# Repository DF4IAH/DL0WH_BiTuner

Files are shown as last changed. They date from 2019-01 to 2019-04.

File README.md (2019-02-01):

# DL0WH_BiTuner_Firmware
Based on the DJ0ABR tuner hardware this project is a replacement for the controller PCB and its firmware. The new PCB does have a __STM32L476RGT6__ MCU device and has got preparations for SWR metering.

## V1.2 PCB after placement and routing was done:
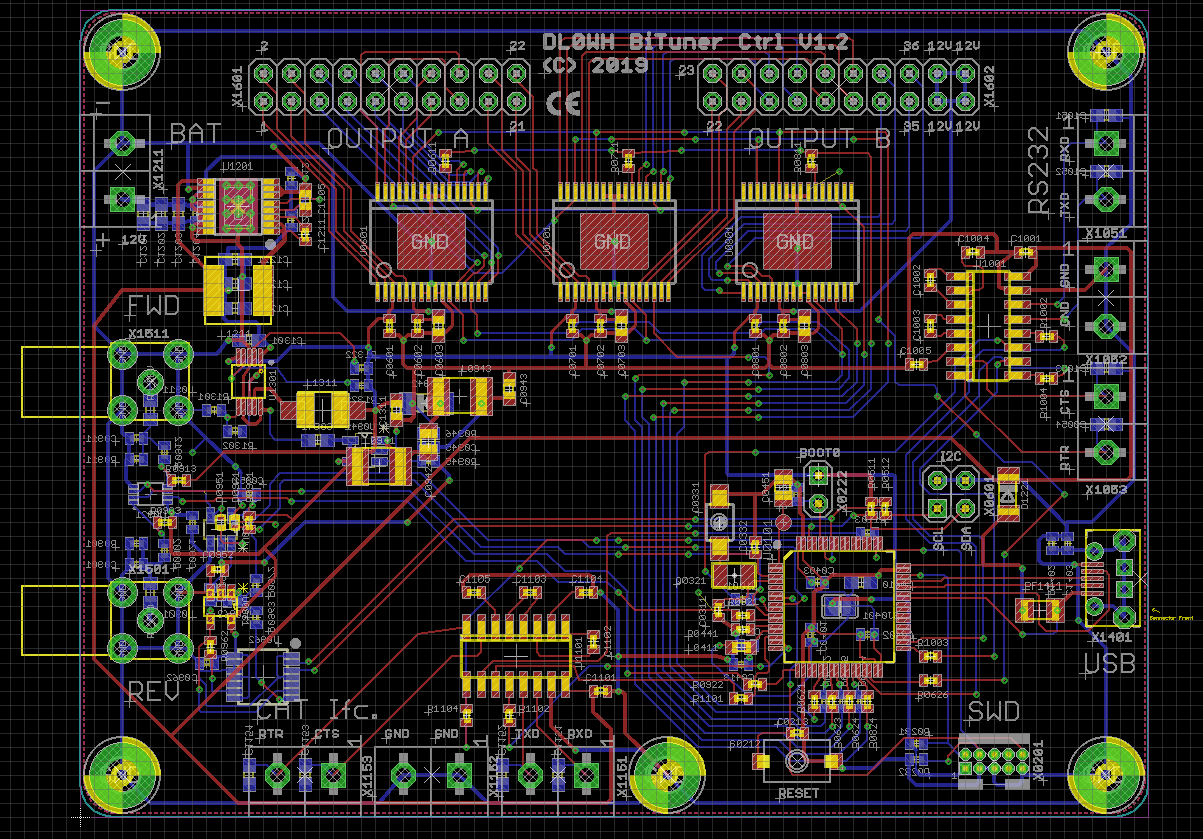
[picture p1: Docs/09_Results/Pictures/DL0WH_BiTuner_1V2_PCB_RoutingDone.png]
Screenshot of V1.2 no polyfill


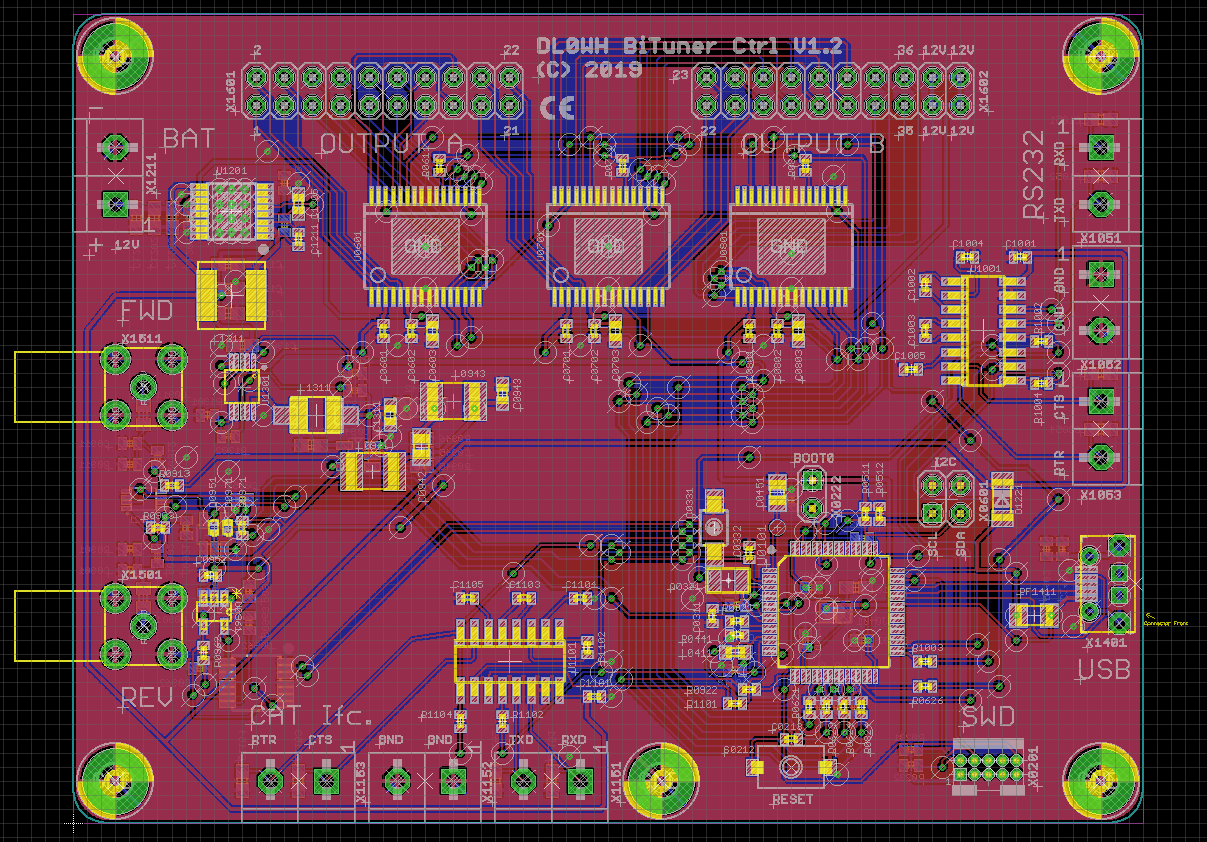
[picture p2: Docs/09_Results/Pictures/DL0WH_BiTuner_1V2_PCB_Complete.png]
Screenshot of V1.2 complete


## V1.2 MCU Pinout:
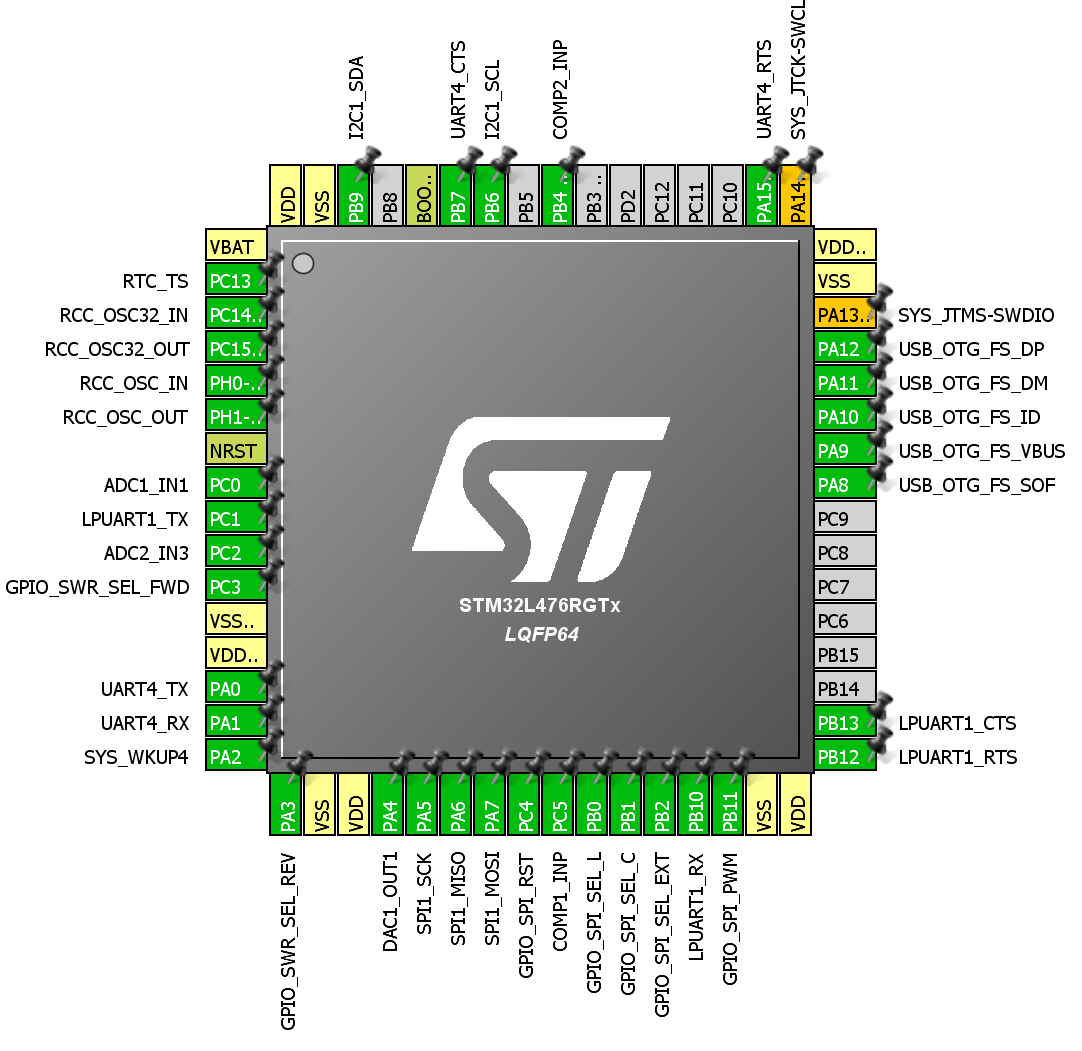
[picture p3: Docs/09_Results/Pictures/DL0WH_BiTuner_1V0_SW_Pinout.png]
MCU Pinout of V1.0


## Ready for samples:
The board is again ready for production.

## Version list:
V1.2 SWD connector bad size - 2019-02-01
* Library content for the CORTEX JTAG/SWD connector was wrong, fixed.
* PCB board house failed on trace distances of 6 mils. Design expanded to 8 mils.

---

V1.1 LQFP64 bug fix - 2019-01-18
* Due to a bad LQFP64 package within the STM32L4 library (who made that crappy library?) the device did not fit at the PCB. That made a turn-around to take time and money. Never trust any library again.

---

V1.0 initial version - 2019-01-04

---

73  Uli DF4IAH, Ladenburg, 2019-02-01

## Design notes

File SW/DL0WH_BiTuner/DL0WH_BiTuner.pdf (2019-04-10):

## DL0WH_BiTuner Project Configuration Report

# 1. Description

## 1.1. Project

Project Name | DL0WH_BiTuner
Board Name | custom
Generated with: | STM32CubeMX 4.27.0
Date | 04/10/2019

## 1.2. MCU

MCU Series | STM32L4
MCU Line | STM32L4x6
MCU name | STM32L476RGTx
MCU Package | LQFP64
MCU Pin number | 64

# 2. Pinout Configuration

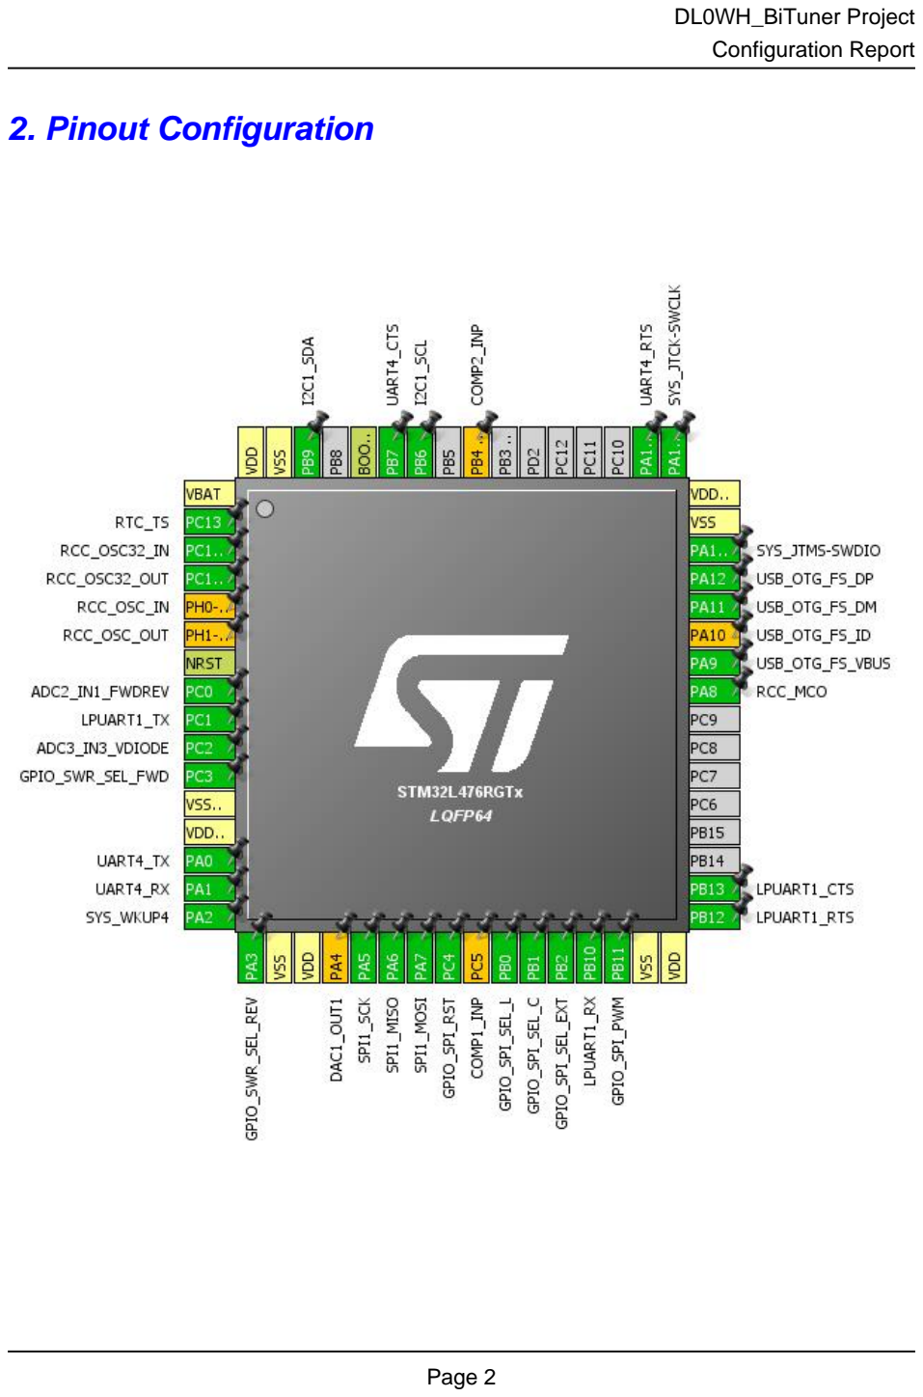
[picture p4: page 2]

# 3. Pins Configuration

Pin Number LQFP64 | Pin Name (function after reset) | Pin Type | Alternate Function(s) | Label
1 | VBAT | Power
2 | PC13 | I/O | RTC_TS
3 | PC14-OSC32_IN (PC14) | I/O | RCC_OSC32_IN
4 | PC15-OSC32_OUT (PC15) | I/O | RCC_OSC32_OUT
5 | PH0-OSC_IN (PH0) * | I/O | RCC_OSC_IN
6 | PH1-OSC_OUT (PH1) * | I/O | RCC_OSC_OUT
7 | NRST | Reset
8 | PC0 | I/O | ADC1_IN1, ADC2_IN1 | ADC2_IN1_FWDREV
9 | PC1 | I/O | LPUART1_TX
10 | PC2 | I/O | ADC2_IN3, ADC3_IN3 | ADC3_IN3_VDIODE
11 | PC3 ** | I/O | GPIO_Output | GPIO_SWR_SEL_FWD
12 | VSSA/VREF- | Power
13 | VDDA/VREF+ | Power
14 | PA0 | I/O | UART4_TX
15 | PA1 | I/O | UART4_RX
16 | PA2 | I/O | SYS_WKUP4
17 | PA3 ** | I/O | GPIO_Output | GPIO_SWR_SEL_REV
18 | VSS | Power
19 | VDD | Power
20 | PA4 * | I/O | DAC1_OUT1
21 | PA5 | I/O | SPI1_SCK
22 | PA6 | I/O | SPI1_MISO
23 | PA7 | I/O | SPI1_MOSI
24 | PC4 ** | I/O | GPIO_Output | GPIO_SPI_RST
25 | PC5 * | I/O | COMP1_INP
26 | PB0 ** | I/O | GPIO_Output | GPIO_SPI_SEL_L
27 | PB1 ** | I/O | GPIO_Output | GPIO_SPI_SEL_C
28 | PB2 ** | I/O | GPIO_Output | GPIO_SPI_SEL_EXT
29 | PB10 | I/O | LPUART1_RX
30 | PB11 ** | I/O | GPIO_Output | GPIO_SPI_PWM
31 | VSS | Power
32 | VDD | Power
33 | PB12 | I/O | LPUART1_RTS
34 | PB13 | I/O | LPUART1_CTS
41 | PA8 | I/O | RCC_MCO
42 | PA9 | I/O | USB_OTG_FS_VBUS

Pin Number LQFP64 | Pin Name (function after reset) | Pin Type | Alternate Function(s) | Label
43 | PA10 * | I/O | USB_OTG_FS_ID
44 | PA11 | I/O | USB_OTG_FS_DM
45 | PA12 | I/O | USB_OTG_FS_DP
46 | PA13 (JTMS-SWDIO) | I/O | SYS_JTMS-SWDIO
47 | VSS | Power
48 | VDDUSB | Power
49 | PA14 (JTCK-SWCLK) | I/O | SYS_JTCK-SWCLK
50 | PA15 (JTDI) | I/O | UART4_RTS
56 | PB4 (NJTRST) * | I/O | COMP2_INP
58 | PB6 | I/O | I2C1_SCL
59 | PB7 | I/O | UART4_CTS
60 | BOOT0 | Boot
62 | PB9 | I/O | I2C1_SDA
63 | VSS | Power
64 | VDD | Power

## ** The pin is affected with an I/O function * The pin is affected with a peripheral function but no peripheral mode is activated

# 4. Clock Tree Configuration

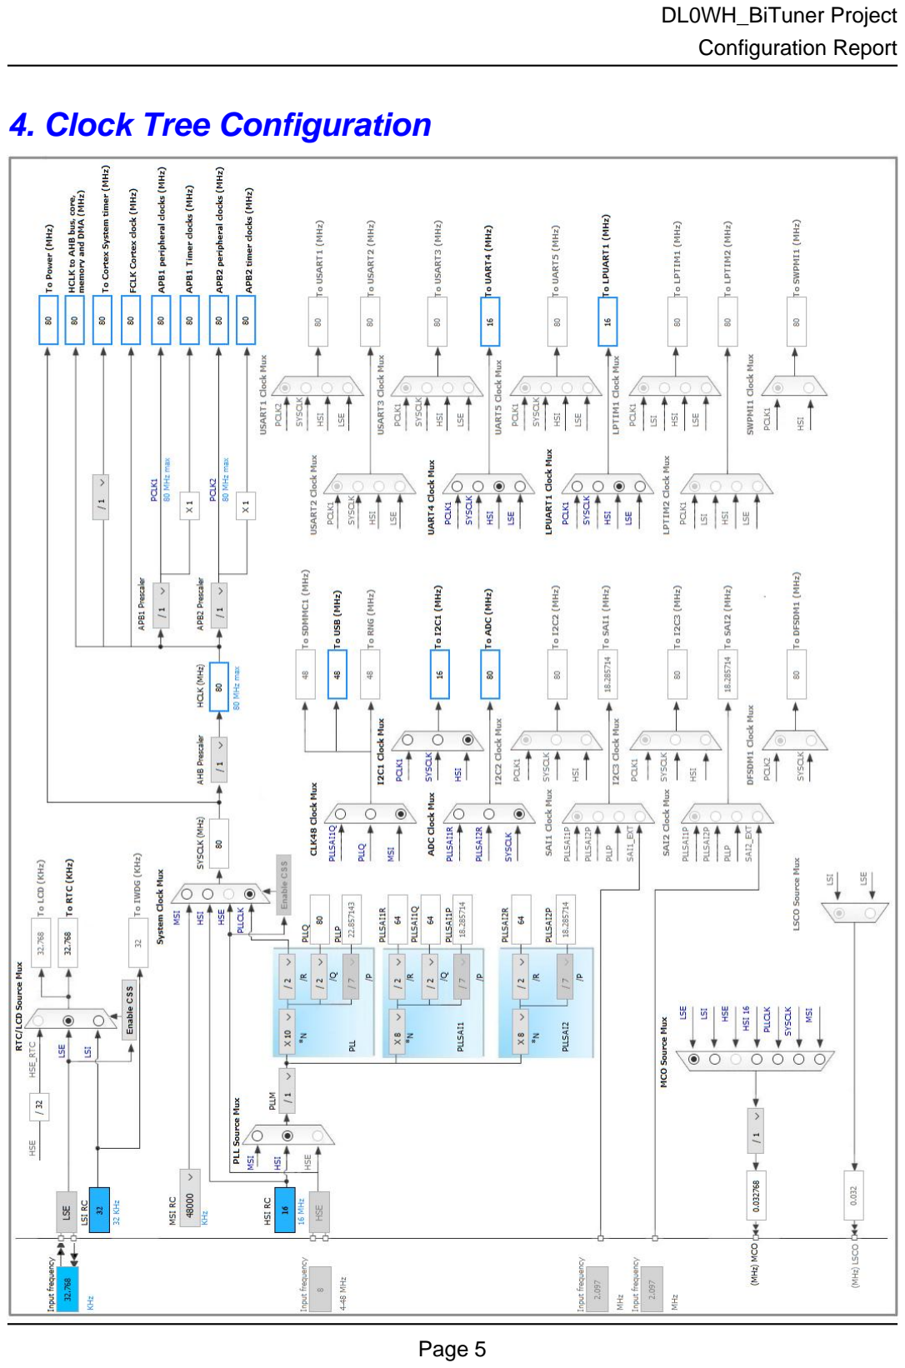
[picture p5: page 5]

# 5. IPs and Middleware Configuration

# 5.1. ADC1

## mode: Temperature Sensor Channel mode: Vbat Channel mode: Vrefint Channel 5.1.1. Parameter Settings:

### ADCs_Common_Settings:

Mode | Independent mode

### ADC_Settings:

Clock Prescaler | Asynchronous clock mode divided by 1
Resolution | ADC 12-bit resolution
Data Alignment | Right alignment
Scan Conversion Mode | Disabled
Continuous Conversion Mode | Disabled
Discontinuous Conversion Mode | Disabled
DMA Continuous Requests | Disabled
End Of Conversion Selection | End of single conversion
Overrun behaviour | Overrun data overwritten *
Low Power Auto Wait | Disabled

### ADC_Regular_ConversionMode:

Enable Regular Conversions | Enable
Enable Regular Oversampling | Enable *
Oversampling Right Shift | No bit shift for oversampling
Oversampling Ratio | Oversampling ratio 16x *
Regular Oversampling Mode | Oversampling Continued Mode
Triggered Regular Oversampling | Single trigger for all oversampled conversions
Number Of Conversion | 1
External Trigger Conversion Source | Regular Conversion launched by software
External Trigger Conversion Edge | None
Rank | 1
Channel | Channel Vrefint *
Sampling Time | 47.5 Cycles *
Offset Number | No offset

### ADC_Injected_ConversionMode:

Enable Injected Conversions | Disable

### Analog Watchdog 1:

Enable Analog WatchDog1 Mode | false

### Analog Watchdog 2:

Enable Analog WatchDog2 Mode | false

### Analog Watchdog 3:

Enable Analog WatchDog3 Mode | false

# 5.2. ADC2

## IN1: IN1 Single-ended 5.2.1. Parameter Settings:

### ADCs_Common_Settings:

Mode | Independent mode

### ADC_Settings:

Clock Prescaler | Asynchronous clock mode divided by 1
Resolution | ADC 12-bit resolution
Data Alignment | Right alignment
Scan Conversion Mode | Disabled
Continuous Conversion Mode | Disabled
Discontinuous Conversion Mode | Disabled
DMA Continuous Requests | Disabled
End Of Conversion Selection | End of single conversion
Overrun behaviour | Overrun data preserved
Low Power Auto Wait | Disabled

### ADC_Regular_ConversionMode:

Enable Regular Conversions | Enable
Enable Regular Oversampling | Enable *
Oversampling Right Shift | 4 bit shift for oversampling *
Oversampling Ratio | Oversampling ratio 256x *
Regular Oversampling Mode | Oversampling Continued Mode
Triggered Regular Oversampling | Single trigger for all oversampled conversions
Number Of Conversion | 1
External Trigger Conversion Source | Regular Conversion launched by software
External Trigger Conversion Edge | None
Rank | 1
Channel | Channel 1
Sampling Time | 12.5 Cycles *
Offset Number | No offset

### ADC_Injected_ConversionMode:

Enable Injected Conversions | Disable

### Analog Watchdog 1:

Enable Analog WatchDog1 Mode | false

### Analog Watchdog 2:

Enable Analog WatchDog2 Mode | false

### Analog Watchdog 3:

Enable Analog WatchDog3 Mode | false

# 5.3. ADC3

## IN3: IN3 Single-ended 5.3.1. Parameter Settings:

### ADC_Settings:

Clock Prescaler | Asynchronous clock mode divided by 1
Resolution | ADC 12-bit resolution
Data Alignment | Right alignment
Scan Conversion Mode | Disabled
Continuous Conversion Mode | Disabled
Discontinuous Conversion Mode | Disabled
DMA Continuous Requests | Disabled
End Of Conversion Selection | End of single conversion
Overrun behaviour | Overrun data overwritten *
Low Power Auto Wait | Disabled

### ADC_Regular_ConversionMode:

Enable Regular Conversions | Enable
Enable Regular Oversampling | Enable *
Oversampling Right Shift | No bit shift for oversampling
Oversampling Ratio | Oversampling ratio 16x *
Regular Oversampling Mode | Oversampling Continued Mode
Triggered Regular Oversampling | Single trigger for all oversampled conversions
Number Of Conversion | 1
External Trigger Conversion Source | Regular Conversion launched by software
External Trigger Conversion Edge | None
Rank | 1
Channel | Channel 3
Sampling Time | 47.5 Cycles *
Offset Number | No offset

### ADC_Injected_ConversionMode:

Enable Injected Conversions | Disable

### Analog Watchdog 1:

Enable Analog WatchDog1 Mode | false

### Analog Watchdog 2:

Enable Analog WatchDog2 Mode | false

### Analog Watchdog 3:

Enable Analog WatchDog3 Mode | false

# 5.4. I2C1

## I2C: I2C 5.4.1. Parameter Settings:

### Timing configuration:

I2C Speed Mode | Fast Mode *
I2C Speed Frequency (KHz) | 400
Rise Time (ns) | 50 *
Fall Time (ns) | 20 *
Coefficient of Digital Filter | 3 *
Analog Filter | Enabled
Timing | 0x00200316 *

### Slave Features:

Clock No Stretch Mode | Disabled
General Call Address Detection | Disabled
Primary Address Length selection | 7-bit
Dual Address Acknowledged | Disabled
Primary slave address | 0

# 5.5. LPUART1

## Mode: Asynchronous Hardware Flow Control (RS232): CTS/RTS 5.5.1. Parameter Settings:

### Basic Parameters:

Baud Rate | 9600 *
Word Length | 8 Bits (including Parity) *
Parity | None
Stop Bits | 1

### Advanced Parameters:

Data Direction | Receive and Transmit
Single Sample | Disable

### Advanced Features:

TX Pin Active Level Inversion | Disable
RX Pin Active Level Inversion | Disable
Data Inversion | Disable
TX and RX pins Swapping | Disable
Overrun | Enable
DMA on RX Error | Enable
MSB First | Disable

# 5.6. RCC

## Low Speed Clock (LSE) : Crystal/Ceramic Resonator mode: Master Clock Output 5.6.1. Parameter Settings:

### System Parameters:

VDD voltage (V) | 3.3
Instruction Cache | Enabled
Prefetch Buffer | Enabled *
Data Cache | Enabled
Flash Latency(WS) | 4 WS (5 CPU cycle)

### RCC Parameters:

HSI Calibration Value | 0x10
MSI Calibration Value | 0xfe *
MSI Auto Calibration | Enabled
HSE Startup Timout Value (ms) | 100
LSE Startup Timout Value (ms) | 5000
LSE Drive Capability | LSE oscillator medium low drive capability *

### Power Parameters:

Power Regulator Voltage Scale | Power Regulator Voltage Scale 1

# 5.7. RTC

## mode: Activate Clock Source mode: Activate Calendar

## Alarm A: Internal Alarm A WakeUp: Internal WakeUp mode: Timestamp 5.7.1. Parameter Settings:

### General:

Hour Format | Hourformat 24
Asynchronous Predivider value | 127
Synchronous Predivider value | 255

### Calendar Time:

Data Format | BCD data format
Hours | 0
Minutes | 0
Seconds | 0
Day Light Saving: value of hour adjustment | Daylightsaving None
Store Operation | Storeoperation Reset

### Calendar Date:

Week Day | Monday
Month | February *
Date | 4 *
Year | 19 *

### Alarm A:

Hours | 0
Minutes | 0
Seconds | 0
Sub Seconds | 0
Alarm Mask Date Week day | Disable
Alarm Mask Hours | Disable
Alarm Mask Minutes | Disable
Alarm Mask Seconds | Disable
Alarm Sub Second Mask | All Alarm SS fields are masked.
Alarm Date Week Day Sel | Date
Alarm Date | 1

### Wake UP:

Wake Up Clock | RTCCLK / 16
Wake Up Counter | 0

### Time Stamp:

Time Stamp Pin Edge | Time Stamp occurs on the Rising edge

# 5.8. SPI1

## Mode: Full-Duplex Master 5.8.1. Parameter Settings:

### Basic Parameters:

Frame Format | Motorola
Data Size | 8 Bits *
First Bit | MSB First

### Clock Parameters:

Prescaler (for Baud Rate) | 16 *
Baud Rate | 5.0 MBits/s *
Clock Polarity (CPOL) | Low
Clock Phase (CPHA) | 2 Edge *

### Advanced Parameters:

CRC Calculation | Disabled
NSS Signal Type | Software

# 5.9. SYS

## Debug: Serial Wire mode: System Wake-Up 4 Power Voltage Detector In: Power Voltage Detector In (Internal analog voltage) Timebase Source: TIM2 5.9.1. Parameter Settings:

### Programmable_Voltage_Detector_Settings:

PVD detection Level | PWR PVD LEVEL 3 (2.5 V) *
PWR PVD Mode | basic mode is used

# 5.10. TIM5

## mode: Clock Source 5.10.1. Parameter Settings:

### Counter Settings:

Prescaler (PSC - 16 bits value) | 0
Counter Mode | Up
Counter Period (AutoReload Register - 32 bits value ) | 79999999 *
Internal Clock Division (CKD) | No Division
auto-reload preload | Enable *

### Trigger Output (TRGO) Parameters:

Master/Slave Mode (MSM bit) | Disable (Trigger input effect not delayed)
Trigger Event Selection TRGO | Reset (UG bit from TIMx_EGR)

# 5.11. UART4

## Mode: Asynchronous Hardware Flow Control (RS232): CTS/RTS 5.11.1. Parameter Settings:

### Basic Parameters:

Baud Rate | 9600 *
Word Length | 8 Bits (including Parity)
Parity | None
Stop Bits | 1

### Advanced Parameters:

Data Direction | Receive and Transmit
Over Sampling | 16 Samples
Single Sample | Disable

### Advanced Features:

Auto Baudrate | Disable
TX Pin Active Level Inversion | Disable
RX Pin Active Level Inversion | Disable
Data Inversion | Disable
TX and RX Pins Swapping | Disable
Overrun | Enable
DMA on RX Error | Enable
MSB First | Disable

# 5.12. USB_OTG_FS

## Mode: Device_Only Activate_VBUS: VBUS sensing

## 5.12.1. Parameter Settings:

Speed | Full Speed 12MBit/s
Endpoint 0 Max Packet size | 64 Bytes
Enable internal IP DMA | Enabled *
Low power | Disabled
Battery charging | Disabled *
Link Power Management | Enabled *
VBUS sensing | Enabled
Signal start of frame | Disabled

# 5.13. FREERTOS

## mode: Enabled 5.13.1. Config parameters:

### Versions:

FreeRTOS version | 10.0.1
CMSIS-RTOS version | 1.02

### Kernel settings:

USE_PREEMPTION | Enabled
CPU_CLOCK_HZ | SystemCoreClock
TICK_RATE_HZ | 1000
MAX_PRIORITIES | 7
MINIMAL_STACK_SIZE | 256 *
MAX_TASK_NAME_LEN | 32 *
USE_16_BIT_TICKS | Disabled
IDLE_SHOULD_YIELD | Enabled
USE_MUTEXES | Enabled
USE_RECURSIVE_MUTEXES | Disabled
USE_COUNTING_SEMAPHORES | Enabled *
QUEUE_REGISTRY_SIZE | 8
USE_APPLICATION_TASK_TAG | Enabled *
ENABLE_BACKWARD_COMPATIBILITY | Disabled *
USE_PORT_OPTIMISED_TASK_SELECTION | Enabled
USE_TICKLESS_IDLE | Disabled
USE_TASK_NOTIFICATIONS | Enabled
RECORD_STACK_HIGH_ADDRESS | Enabled *

### Memory management settings:

Memory Allocation | Dynamic
TOTAL_HEAP_SIZE | 32768 *
Memory Management scheme | heap_4

### Hook function related definitions:

USE_IDLE_HOOK | Enabled *
USE_TICK_HOOK | Disabled
USE_MALLOC_FAILED_HOOK | Enabled *
USE_DAEMON_TASK_STARTUP_HOOK | Disabled
CHECK_FOR_STACK_OVERFLOW | Option1 *

### Run time and task stats gathering related definitions:

GENERATE_RUN_TIME_STATS | Enabled *
USE_TRACE_FACILITY | Enabled *
USE_STATS_FORMATTING_FUNCTIONS | Enabled *

### Co-routine related definitions:

USE_CO_ROUTINES | Disabled
MAX_CO_ROUTINE_PRIORITIES | 2

### Software timer definitions:

USE_TIMERS | Enabled
TIMER_TASK_PRIORITY | 2
TIMER_QUEUE_LENGTH | 10
TIMER_TASK_STACK_DEPTH | 512

### Interrupt nesting behaviour configuration:

LIBRARY_LOWEST_INTERRUPT_PRIORITY | 15
LIBRARY_MAX_SYSCALL_INTERRUPT_PRIORITY | 5

## 5.13.2. Include parameters:

### Include definitions:

vTaskPrioritySet | Enabled
uxTaskPriorityGet | Enabled
vTaskDelete | Enabled
vTaskCleanUpResources | Enabled *
vTaskSuspend | Enabled
vTaskDelayUntil | Enabled *
vTaskDelay | Enabled
xTaskGetSchedulerState | Enabled
xTaskResumeFromISR | Enabled
xQueueGetMutexHolder | Enabled *
xSemaphoreGetMutexHolder | Enabled *

pcTaskGetTaskName | Enabled *
uxTaskGetStackHighWaterMark | Enabled *
xTaskGetCurrentTaskHandle | Enabled *
eTaskGetState | Enabled *
xEventGroupSetBitFromISR | Enabled *
xTimerPendFunctionCall | Enabled *
xTaskAbortDelay | Enabled *
xTaskGetHandle | Enabled *

# 5.14. USB_DEVICE

## Class For FS IP: Communication Device Class (Virtual Port Com) 5.14.1. Parameter Settings:

### Basic Parameters:

USBD_MAX_NUM_INTERFACES (Maximum number of supported interfaces) | 1
USBD_MAX_NUM_CONFIGURATION (Maximum number of supported configuration) | 1
USBD_MAX_STR_DESC_SIZ (Maximum size for the string descriptors) | 512
USBD_SUPPORT_USER_STRING (Enable user string descriptor) | Disabled
USBD_SELF_POWERED (Enabled self power) | Enabled
USBD_DEBUG_LEVEL (USBD Debug Level) | 1: Only User messages are shown *
USBD_LPM_ENABLED (Link Power Management) | 1: Link Power Management supported

### Class Parameters:

USB CDC Rx Buffer Size | 2048
USB CDC Tx Buffer Size | 2048

## 5.14.2. Device Descriptor:

### Device Descriptor:

VID (Vendor IDentifier) | 0x0483
LANGID_STRING (Language Identifier) | English(United States)
MANUFACTURER_STRING (Manufacturer Identifier) | STMicroelectronics

### Device Descriptor FS:

PID (Product IDentifier) | 0x5740
PRODUCT_STRING (Product Identifier) | STM32 Virtual ComPort
SERIALNUMBER_STRING (Serial number) | 00000000001A
CONFIGURATION_STRING (Configuration Identifier) | CDC Config

INTERFACE_STRING (Interface Identifier) | CDC Interface

### * User modified value

# 6. System Configuration

# 6.1. GPIO configuration

IP | Pin | Signal | GPIO mode | GPIO pull/up pull down

## Max Speed

## User Label

ADC1 | PC0 | ADC1_IN1 | Analog mode for ADC
conversion
No pull-up and no pull-down | n/a | ADC2_IN1_FWDREV
ADC2 | PC0 | ADC2_IN1 | Analog mode for ADC
conversion
No pull-up and no pull-down | n/a | ADC2_IN1_FWDREV
PC2 | ADC2_IN3 | Analog mode for ADC
conversion
No pull-up and no pull-down | n/a | ADC3_IN3_VDIODE
ADC3 | PC2 | ADC3_IN3 | Analog mode for ADC
conversion
No pull-up and no pull-down | n/a | ADC3_IN3_VDIODE
I2C1 | PB6 | I2C1_SCL | Alternate Function Open
Drain
| | | Pull-up | Very High
*
PB9 | I2C1_SDA | Alternate Function Open
| | Drain | Pull-up | Very High
*
LPUART1 | PC1 | LPUART1_TX Alternate Function Push Pull | No pull-up and no pull-down | Medium *
| PB10 | LPUART1_RX Alternate Function Push Pull | Pull-up * | Medium *
| PB12 | LPUART1_RTS Alternate Function Push Pull | No pull-up and no pull-down | Medium *
| PB13 | LPUART1_CTS Alternate Function Push Pull | Pull-up * | Medium *
RCC | PC14- OSC32_IN (PC14)
RCC_OSC32_IN | n/a | n/a | n/a

PC15-
OSC32_OU
T (PC15)

RCC_OSC32_O
UT
n/a | n/a | n/a
| PA8 | RCC_MCO | Alternate Function Push Pull | No pull-up and no pull-down | Low
RTC | PC13 | RTC_TS | n/a | n/a | n/a
SPI1 | PA5 | SPI1_SCK | Alternate Function Push Pull | No pull-up and no pull-down | Very High
*
| PA6 | SPI1_MISO | Alternate Function Push Pull | Pull-down * | Very High
*
| PA7 | SPI1_MOSI | Alternate Function Push Pull | No pull-up and no pull-down | Very High
*
SYS | PA2 | SYS_WKUP4 | n/a | n/a | n/a
| PA13 (JTMS- SWDIO) | SYS_JTMS- SWDIO | n/a | n/a | n/a

PA14 (JTCK-SWCLK)

SYS_JTCK-SWCLK

n/a | n/a | n/a

IP | Pin | Signal | GPIO mode | GPIO pull/up pull down | Max Speed | User Label
UART4 | PA0 | UART4_TX | Alternate Function Push Pull | No pull-up and no pull-down | Medium *
| PA1 | UART4_RX | Alternate Function Push Pull | Pull-up * | Medium *
| PA15 (JTDI) | UART4_RTS | Alternate Function Push Pull | No pull-up and no pull-down | Medium *
| PB7 | UART4_CTS | Alternate Function Push Pull | Pull-up * | Medium *
USB_OTG_ FS | PA9 | USB_OTG_FS_ VBUS | Input mode | No pull-up and no pull-down | n/a
| PA11 | USB_OTG_FS_ DM | Alternate Function Push Pull | No pull-up and no pull-down | Very High *
| PA12 | USB_OTG_FS_ DP | Alternate Function Push Pull | No pull-up and no pull-down | Very High *
Single Mapped Signals | PH0-OSC_IN (PH0) | RCC_OSC_IN | n/a | n/a | n/a
| PH1-OSC_OUT (PH1) | RCC_OSC_OUT | n/a | n/a | n/a
| PA4 | DAC1_OUT1 | Analog mode | No pull-up and no pull-down | n/a
| PC5 | COMP1_INP | Analog mode | No pull-up and no pull-down | n/a
| PA10 | USB_OTG_FS_I D | Alternate Function Push Pull | No pull-up and no pull-down | Very High *
| PB4 (NJTRST) | COMP2_INP | Analog mode | No pull-up and no pull-down | n/a
GPIO | PC3 | GPIO_Output | Output Push Pull | No pull-up and no pull-down | Low | GPIO_SWR_SEL_FWD
| PA3 | GPIO_Output | Output Push Pull | No pull-up and no pull-down | Low | GPIO_SWR_SEL_REV
| PC4 | GPIO_Output | Output Push Pull | No pull-up and no pull-down | Low | GPIO_SPI_RST
| PB0 | GPIO_Output | Output Push Pull | No pull-up and no pull-down | Very High * | GPIO_SPI_SEL_L
| PB1 | GPIO_Output | Output Push Pull | No pull-up and no pull-down | Very High * | GPIO_SPI_SEL_C
| PB2 | GPIO_Output | Output Push Pull | No pull-up and no pull-down | Very High * | GPIO_SPI_SEL_EXT
| PB11 | GPIO_Output | Output Push Pull | No pull-up and no pull-down | Low | GPIO_SPI_PWM

# 6.2. DMA configuration

DMA request | Stream | Direction | Priority
SPI1_TX | DMA1_Channel3 | Memory To Peripheral | Low
SPI1_RX | DMA1_Channel2 | Peripheral To Memory | Low
I2C1_RX | DMA1_Channel7 | Peripheral To Memory | Low
I2C1_TX | DMA1_Channel6 | Memory To Peripheral | Low
LPUART_RX | DMA2_Channel7 | Peripheral To Memory | Low
LPUART_TX | DMA2_Channel6 | Memory To Peripheral | Low
UART4_RX | DMA2_Channel5 | Peripheral To Memory | Low
UART4_TX | DMA2_Channel3 | Memory To Peripheral | Low
ADC2 | DMA2_Channel4 | Peripheral To Memory | Low
ADC1 | DMA1_Channel1 | Peripheral To Memory | Low

## SPI1_TX: DMA1_Channel3 DMA request Settings:

Mode: | Normal
Peripheral Increment: | Disable
Memory Increment: | Enable *
Peripheral Data Width: | Byte
Memory Data Width: | Byte

## SPI1_RX: DMA1_Channel2 DMA request Settings:

Mode: | Normal
Peripheral Increment: | Disable
Memory Increment: | Enable *
Peripheral Data Width: | Byte
Memory Data Width: | Byte

## I2C1_RX: DMA1_Channel7 DMA request Settings:

Mode: | Normal
Peripheral Increment: | Disable
Memory Increment: | Enable *
Peripheral Data Width: | Byte
Memory Data Width: | Byte

## I2C1_TX: DMA1_Channel6 DMA request Settings:

Mode: | Normal
Peripheral Increment: | Disable
Memory Increment: | Enable *
Peripheral Data Width: | Byte
Memory Data Width: | Byte

## LPUART_RX: DMA2_Channel7 DMA request Settings:

Mode: | Normal
Peripheral Increment: | Disable
Memory Increment: | Enable *
Peripheral Data Width: | Byte
Memory Data Width: | Byte

## LPUART_TX: DMA2_Channel6 DMA request Settings:

Mode: | Normal
Peripheral Increment: | Disable
Memory Increment: | Enable *
Peripheral Data Width: | Byte
Memory Data Width: | Byte

## UART4_RX: DMA2_Channel5 DMA request Settings:

Mode: | Normal
Peripheral Increment: | Disable
Memory Increment: | Enable *
Peripheral Data Width: | Byte
Memory Data Width: | Byte

## UART4_TX: DMA2_Channel3 DMA request Settings:

Mode: | Normal
Peripheral Increment: | Disable
Memory Increment: | Enable *
Peripheral Data Width: | Byte
Memory Data Width: | Byte

## ADC2: DMA2_Channel4 DMA request Settings:

Mode: | Normal
Peripheral Increment: | Disable
Memory Increment: | Enable *
Peripheral Data Width: | Half Word
Memory Data Width: | Half Word

## ADC1: DMA1_Channel1 DMA request Settings:

Mode: | Normal
Peripheral Increment: | Disable
Memory Increment: | Enable *
Peripheral Data Width: | Half Word
Memory Data Width: | Half Word

# 6.3. NVIC configuration

Interrupt Table | Enable | Preenmption Priority | SubPriority
Non maskable interrupt | true | 0 | 0
Hard fault interrupt | true | 0 | 0
Memory management fault | true | 0 | 0
Prefetch fault, memory access fault | true | 0 | 0
Undefined instruction or illegal state | true | 0 | 0
System service call via SWI instruction | true | 0 | 0
Debug monitor | true | 0 | 0
Pendable request for system service | true | 15 | 0
System tick timer | true | 15 | 0
RTC wake-up interrupt through EXTI line 20 | true | 5 | 0
DMA1 channel1 global interrupt | true | 5 | 0
DMA1 channel2 global interrupt | true | 5 | 0
DMA1 channel3 global interrupt | true | 5 | 0
DMA1 channel6 global interrupt | true | 5 | 0
DMA1 channel7 global interrupt | true | 5 | 0
ADC1 and ADC2 interrupts | true | 5 | 0
TIM2 global interrupt | true | 0 | 0
I2C1 event interrupt | true | 5 | 0
I2C1 error interrupt | true | 5 | 0
SPI1 global interrupt | true | 5 | 0
RTC alarm interrupt through EXTI line 18 | true | 5 | 0
ADC3 global interrupt | true | 5 | 0
TIM5 global interrupt | true | 5 | 0
UART4 global interrupt | true | 5 | 0
DMA2 channel3 global interrupt | true | 5 | 0
DMA2 channel4 global interrupt | true | 5 | 0
DMA2 channel5 global interrupt | true | 5 | 0
USB OTG FS global interrupt | true | 5 | 0
DMA2 channel6 global interrupt | true | 5 | 0
DMA2 channel7 global interrupt | true | 5 | 0
LPUART1 global interrupt | true | 5 | 0
PVD/PVM1/PVM2/PVM3/PVM4 interrupts through EXTI lines 16/35/36/37/38 | unused
RTC tamper and time stamp, CSS on LSE interrupts through EXTI line 19 | unused
Flash global interrupt | unused
RCC global interrupt | unused
FPU global interrupt | unused

### * User modified value

# 7. Power Consumption Calculator report

### 7.1. Microcontroller Selection

Series | STM32L4
Line | STM32L4x6
MCU | STM32L476RGTx
Datasheet | 025976_Rev4

### 7.2. Parameter Selection

Temperature | 25
Vdd | 3.6

## 7.3. Sequence

Step | Step1 | Step2
Mode | RUN | SLEEP
Vdd | 3.6 | 3.6
Voltage Source | Battery | Vbus
Range | Range2-Medium | Range2-Medium
Fetch Type | FLASH/ART/Cache | ON
Clock Configuration | HSE | HSE
Clock Source Frequency 16 MHz | 16 MHz
CPU Frequency | 16 MHz | 16 MHz
Peripherals | ADC1:fs_10_ksps ADC2:fs_10_ksps ADC3:fs_10_ksps AHB_APB1_Bridge AHB_APB2_Bridge CRC DAC1:OUT1-Buffer_OFF- Middle_code GPIOA GPIOB GPIOC GPIOD GPIOH I2C1 LPTIM1 PVD/BOR RNG RTC SPI1 TIM5 UART4 USB_OTG_FS

### ADC1:fs_10_ksps ADC2:fs_10_ksps ADC3:fs_10_ksps AHB_APB1_Bridge AHB_APB2_Bridge Bus-Matrix CRC FLASH FW GPIOA GPIOB GPIOC GPIOD GPIOH I2C1 IWDG LPUART1 PVD/BOR PWR RNG RTC SPI1 SRAM1 SRAM2 TIM2 TIM5 UART4 USB_OTG_FS

Additional Cons. | 0 mA | 0 mA
Average Current | 2.62 mA | 1.63 mA

Duration | 1 ms | 1 ms
DMIPS | 0.0 | 0.0
Ta Max | 104.58 | 104.74
Category | In DS Table | In DS Table

## 7.4. RESULTS

Sequence Time | 2 ms | Average Current | 2.12 mA
Battery Life | 0 | Average DMIPS | 20.0 DMIPS

## 7.5. Chart

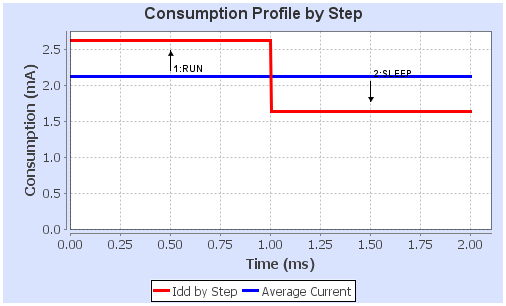
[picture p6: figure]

# 8. Software Project

## 8.1. Project Settings

Name | Value
Project Name | DL0WH_BiTuner
Project Folder | C:\Users\espero\git\DL0WH_BiTuner\SW\DL0WH_BiTuner
Toolchain / IDE | TrueSTUDIO
Firmware Package Name and Version | STM32Cube FW_L4 V1.13.0

## 8.2. Code Generation Settings

Name | Value
STM32Cube Firmware Library Package | Copy only the necessary library files
Generate peripheral initialization as a pair of '.c/.h' files | Yes
Backup previously generated files when re-generating | No
Delete previously generated files when not re-generated | Yes
Set all free pins as analog (to optimize the power consumption) | Yes

# 9. Software Pack Report

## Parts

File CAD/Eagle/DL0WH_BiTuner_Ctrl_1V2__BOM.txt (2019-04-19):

Stückliste exportiert aus /Users/espero/nfs_ds_nfs/git/_untracked/DL0WH_BiTuner/CAD/Eagle/DL0WH_BiTuner_Ctrl_1V2.sch am 19.04.19 14:24

Qty Value                    Device                               Package                             Parts                                                                                                                                             Description                                           

1   STM32L476RXT_64PIN_LDO   STM32L476RXT_64PIN_LDO               LQFP64                              U0101                                                                                                                                             STM32L476RxT 64LQFP                                   

2   MAX232_SOIC16            MAX232_SOIC16                        SOIC16N                             U1001, U1101                                                                                                                                      RS232 TRANSCEIVER                                     

1   LM53603-Q1               LM53603-Q1                           HTSSOP16                            U1201                                                                                                                                             TI LM53603-Q1                                         
1   TPS62056                 TPS62051                             S-PDSO-G10                          U1301                                                                                                                                             TPS62051 800-mA Synchronous Step-Down Converter: 3.3V 
1   LM2611                   LM2611                               SOT95P280X145-5N                    U0941                                                                                                                                             IC REG CUK INV ADJ 1.2A SOT23-5                       

2   OPA354                   OPA354                               SOT-23-5                            U0951, U0961                                                                                                                                      CMOS OPERATIONAL AMPLIFIERS                           

3   MC33996                  MC33996                              SOICW32                             U0601, U0701, U0801                                                                                                                               NXP MC33996                                           

1   TS5A23166                TS5A23166                            R-PDSO-G8                           U0921                                                                                                                                             TS5A23166                                             

1   MCP4661-103E-MS          MCP4661-104E-MS                      TSSOP14                             U0962                                                                                                                                             Microchip MCP4661                                     

1   ABS07-32.768KHZ          ABS07-32.768KHZ                      ABS07                               Q0321                                                                                                                                             ABRACON ABS07                                         

2   CMAD6001                 D_SOD923                             SOD923                              D0951, D0971                                                                                                                                      DIODE with SOD923 footprint                           
2   CRS08                    CRS08                                SOD80C                              D0942, D1221                                                                                                                                      SCHOTTKY BARRIER RECTIFIER                            

2   0R                       R-EU_R0402                           R0402                               R0441, R0622                                                                                                                                      RESISTOR, European symbol                             
1   3R                       R-EU_R0402                           R0402                               R1211                                                                                                                                             RESISTOR, European symbol                             
21  47R                      R-EU_R0402                           R0402                               R0611, R0621, R0623, R0624, R0625, R0626, R0711, R0724, R0811, R0824, R0921, R0922, R0972, R1001, R1002, R1003, R1004, R1101, R1102, R1103, R1104 RESISTOR, European symbol                             
6   1kR                      R-EU_R0402                           R0402                               R0511, R0512, R0901, R0911, R0961, R0962                                                                                                          RESISTOR, European symbol                             
2   2kR                      L-EUL0603                            L0603                               L0901, L0911                                                                                                                                      INDUCTOR, European symbol                             
1   8.2kR                    R-EU_R0402                           R0402                               R0945                                                                                                                                             RESISTOR, European symbol                             
1   10kR                     R-EU_R0402                           R0402                               R0971                                                                                                                                             RESISTOR, European symbol                             
2   15kR                     R-EU_R0402                           R0402                               R0902, R0912                                                                                                                                      RESISTOR, European symbol                             
1   20kR                     R-EU_R0402                           R0402                               R0963                                                                                                                                             RESISTOR, European symbol                             
2   33kR                     R-EU_R0402                           R0402                               R0221, R0946                                                                                                                                      RESISTOR, European symbol                             
1   100kR                    R-EU_R0402                           R0402                               R1301                                                                                                                                             RESISTOR, European symbol                             
2   150kR                    R-EU_R0402                           R0402                               R0903, R0913                                                                                                                                      RESISTOR, European symbol                             
3   220kR                    R-EU_R0402                           R0402                               R0231, R0232, R1302                                                                                                                               RESISTOR, European symbol                             
1   330kR                    R-EU_R0402                           R0402                               R1402                                                                                                                                             RESISTOR, European symbol                             
2   1MR                      R-EU_R0402                           R0402                               R1321, R1322                                                                                                                                      RESISTOR, European symbol                             

1   1.1A/2.2A                R-EU_M1206                           M1206                               PF1411                                                                                                                                            RESISTOR, European symbol                             

2   N/A                      C-EUC0402                            C0402                               C0901, C0911                                                                                                                                      CAPACITOR, European symbol                            
1   18pF                     C-EUC0402                            C0402                               C0332                                                                                                                                             CAPACITOR, European symbol                            
1   22pF                     C-EUC0402                            C0402                               C0311                                                                                                                                             CAPACITOR, European symbol                            
1   100pF                    C-EUC0402                            C0402                               C0963                                                                                                                                             CAPACITOR, European symbol                            
2   1nF                      C-EUC0402                            C0402                               C0945, C1403                                                                                                                                      CAPACITOR, European symbol                            
2   10nF                     C-EUC0402                            C0402                               C0412, C1204                                                                                                                                      CAPACITOR, European symbol                            
8   10nF                     C-EUC0603                            C0603                               C0054, C1051, C1052, C1053, C1151, C1152, C1153, C1154                                                                                            CAPACITOR, European symbol                            
15  100nF                    C-EUC0402                            C0402                               C0213, C0401, C0402, C0403, C0601, C0602, C0701, C0702, C0801, C0802, C0921, C0951, C0952, C0962, C1212                                           CAPACITOR, European symbol                            
1   0.47uF                   C-EUC0402                            C0402                               C1211                                                                                                                                             CAPACITOR, European symbol                            
11  1uF                      C-EUC0402                            C0402                               C0413, C1001, C1002, C1003, C1004, C1005, C1101, C1102, C1103, C1104, C1105                                                                       CAPACITOR, European symbol                            
1   2.2uF                    C-EUC0805                            C0805                               C0942                                                                                                                                             CAPACITOR, European symbol                            
1   3.3uF                    C-EUC0603                            C0603                               C1205                                                                                                                                             CAPACITOR, European symbol                            
1   4.7uF                    C-EUC0603                            C0603                               C0410                                                                                                                                             CAPACITOR, European symbol                            
3   10uF                     C-EUC0603                            C0603                               C1201, C1202, C1203                                                                                                                               CAPACITOR, European symbol                            
10  22uF                     C-EUC0603                            C0603                               C0603, C0703, C0803, C0941, C0943, C1221, C1222, C1223, C1301, C1311                                                                              CAPACITOR, European symbol                            
1   47uF                     C-EUC0805                            C0805                               C0451                                                                                                                                             CAPACITOR, European symbol                            

1   JR200                    C-TRIMM3MM2_2MM5                     3MM2_X_2MM5                         C0331                                                                                                                                             Trimm capacitor                                       

1   2.2uH                    L-EU6.00X6.00MM                      L_6.00MM_X_6.00MM                   L1211                                                                                                                                             INDUCTOR, European symbol                             
1   10uH                     L-EU4.50X3.20MM                      L_4.50MM_X_3.20MM                   L1311                                                                                                                                             INDUCTOR, European symbol                             
1   10uH                     L-EUL0603                            L0603                               L0411                                                                                                                                             INDUCTOR, European symbol                             
2   20uH                     L-EUL1812                            L1812                               L0941, L0943                                                                                                                                      INDUCTOR, European symbol                             

1   KSR223GLFG               KSR223G_SMD_1POL                     KSR223G_SMD_1POL                    S0212                                                                                                                                             KSR223G                                               

1   FTSH-105-01-F-D-K        2X05_1MM27_SHROUDED_CORTEX_JTAG_SWD" 2X05_1MM27_SHROUDED_CORTEX_JTAG_SWD X0201                                                                                                                                             Header 2X5 1.27mm 0.05" shrouded - CORTEX JTAG-SWD    
1   MOLEX 105017-0001        USB_MICRO-B_MOLEX                    USB-B-MICRO-SMD_MOLEX-105017-0001   X1401                                                                                                                                             USB Type Micro-B Connector                            
2   SAMTEC SMA-J-P-H-RA-TH1  SMA_SMT_AMPHENOL-901-143             SMA_SMT_AMPHENOL_901-143            X1501, X1511                                                                                                                                             RF/COAXIAL, SMA JACK, R/A, 50OHM, THD                 
2                            2X10_2MM56_SOCKET                    2X10                                X1601, X1602                                                                                                                                      Header 2X10 2.54mm                                    
1                            HEADER-1X2                           1X02                                X0222                                                                                                                                             Header 1X2 2.54mm                                     
1                            HEADER-2X2                           2X02                                X0601                                                                                                                                             Header 2X2 2.54mm                                     
7   WIRE-TO-BOARD_5MM08_1X02 WIRE-TO-BOARD_5MM08_1X02             WIRE-TO-BOARD_5MM08_1X02            X1051, X1052, X1053, X1151, X1152, X1153, X1211                                                                                                   Wire-to-Board connector 5.08mm 1x02                   

<EOF>

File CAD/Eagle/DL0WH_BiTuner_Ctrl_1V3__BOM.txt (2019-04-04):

Stückliste exportiert aus /Users/espero/nfs_ds_nfs/git/DL0WH_BiTuner/CAD/Eagle/DL0WH_BiTuner_Ctrl_1V3.sch am 16.03.19 19:05

Qty Value                    Device                               Package                             Parts                                                                                                                                             Description                                           

1   STM32L476RGT6_64PIN_LDO  STM32L476RXT_64PIN_LDO               LQFP64                              U0101                                                                                                                                             STM32L476RxT 64LQFP                                   

1   MCP4661-103E-MS          MCP4661-104E-MS                      TSSOP14                             U0962                                                                                                                                             Microchip MCP4661                                     

1   LM53603-Q1               LM53603-Q1                           HTSSOP16                            U1201                                                                                                                                             TI LM53603-Q1                                         
1   TPS62056                 TPS62051                             S-PDSO-G10                          U1301                                                                                                                                             TPS62051 800-mA Synchronous Step-Down Converter: 3.3V 
1   LM2611                   LM2611                               SOT95P280X145-5N                    U0941                                                                                                                                             IC REG CUK INV ADJ 1.2A SOT23-5                       

2   MAX232_SOIC16            MAX232_SOIC16                        SOIC16N                             U1001, U1101                                                                                                                                      RS232 TRANSCEIVER                                     
3   MC33996                  MC33996                              SOICW32                             U0601, U0701, U0801                                                                                                                               NXP MC33996                                           

2   OPA354                   OPA354                               SOT-23-5                            U0951, U0961                                                                                                                                      CMOS OPERATIONAL AMPLIFIERS                           

1   TS5A23166                TS5A23166                            R-PDSO-G8                           U0921                                                                                                                                             TS5A23166                                             

1   ABS07-32.768KHZ          ABS07-32.768KHZ                      ABS07                               Q0321                                                                                                                                             ABRACON ABS07                                         

2   CMAD6001                 D_SOD923                             SOD923                              D0951, D0971                                                                                                                                      DIODE with SOD923 footprint                           
2   CRS08                    CRS08                                SOD80C                              D0942, D1221                                                                                                                                      SCHOTTKY BARRIER RECTIFIER                            

3   0R                       R-EU_R0402                           R0402                               R0401, R0441, R0622                                                                                                                               RESISTOR, European symbol                             
1   3R                       R-EU_R0402                           R0402                               R1211                                                                                                                                             RESISTOR, European symbol                             
21  47R                      R-EU_R0402                           R0402                               R0611, R0621, R0623, R0624, R0625, R0626, R0711, R0724, R0811, R0824, R0921, R0922, R0972, R1001, R1002, R1003, R1004, R1101, R1102, R1103, R1104 RESISTOR, European symbol                             
6   1kR                      R-EU_R0402                           R0402                               R0511, R0512, R0901, R0911, R0961, R0962                                                                                                          RESISTOR, European symbol                             
1   8.2kR                    R-EU_R0402                           R0402                               R0945                                                                                                                                             RESISTOR, European symbol                             
2   10kR                     R-EU_R0402                           R0402                               R0963, R0971                                                                                                                                      RESISTOR, European symbol                             
2   15kR                     R-EU_R0402                           R0402                               R0902, R0912                                                                                                                                      RESISTOR, European symbol                             
2   33kR                     R-EU_R0402                           R0402                               R0221, R0946                                                                                                                                      RESISTOR, European symbol                             
1   100kR                    R-EU_R0402                           R0402                               R1301                                                                                                                                             RESISTOR, European symbol                             
2   150kR                    R-EU_R0402                           R0402                               R0903, R0913                                                                                                                                      RESISTOR, European symbol                             
3   220kR                    R-EU_R0402                           R0402                               R0231, R0232, R1302                                                                                                                               RESISTOR, European symbol                             
1   330kR                    R-EU_R0402                           R0402                               R1402                                                                                                                                             RESISTOR, European symbol                             
2   1MR                      R-EU_R0402                           R0402                               R1321, R1322                                                                                                                                      RESISTOR, European symbol                             

1   1.1A/2.2A                R-EU_M1206                           M1206                               PF1411                                                                                                                                            RESISTOR, European symbol                             

1   18pF                     C-EUC0402                            C0402                               C0332                                                                                                                                             CAPACITOR, European symbol                            
1   22pF                     C-EUC0402                            C0402                               C0311                                                                                                                                             CAPACITOR, European symbol                            
1   100pF                    C-EUC0402                            C0402                               C0963                                                                                                                                             CAPACITOR, European symbol                            
4   1nF                      C-EUC0402                            C0402                               C0901, C0911, C0945, C1403                                                                                                                        CAPACITOR, European symbol                            
10  10nF                     C-EUC0402                            C0402                               C0412, C1051, C1052, C1053, C1054, C1151, C1152, C1153, C1154, C1204                                                                              CAPACITOR, European symbol                            
15  100nF                    C-EUC0402                            C0402                               C0213, C0401, C0402, C0403, C0601, C0602, C0701, C0702, C0801, C0802, C0921, C0951, C0952, C0962, C1212                                           CAPACITOR, European symbol                            
1   0.47uF                   C-EUC0402                            C0402                               C1211                                                                                                                                             CAPACITOR, European symbol                            
11  1uF                      C-EUC0402                            C0402                               C0413, C1001, C1002, C1003, C1004, C1005, C1101, C1102, C1103, C1104, C1105                                                                       CAPACITOR, European symbol                            
1   2.2uF                    C-EUC0603                            C0603                               C0942                                                                                                                                             CAPACITOR, European symbol                            
1   3.3uF                    C-EUC0603                            C0603                               C1205                                                                                                                                             CAPACITOR, European symbol                            
1   4.7uF                    C-EUC0603                            C0603                               C0410                                                                                                                                             CAPACITOR, European symbol                            
3   10uF                     C-EUC0603                            C0603                               C1201, C1202, C1203                                                                                                                               CAPACITOR, European symbol
10  22uF                     C-EUC0603                            C0603                               C0603, C0703, C0803, C0941, C0943, C1221, C1222, C1223, C1301, C1311                                                                              CAPACITOR, European symbol                            
1   47uF                     C-EUC0805                            C0805                               C0451                                                                                                                                             CAPACITOR, European symbol                            

1   JR200                    C-TRIMM3MM2_2MM5                     3MM2_X_2MM5                         C0331                                                                                                                                             Trimm capacitor                                       

1   2.2uH                    L-EU6.00X6.00MM                      L_6.00MM_X_6.00MM                   L1211                                                                                                                                             INDUCTOR, European symbol                             
1   10uH                     L-EU4.50X3.20MM                      L_4.50MM_X_3.20MM                   L1311                                                                                                                                             INDUCTOR, European symbol                             
3   10uH                     L-EUL0603                            L0603                               L0411, L0901, L0911                                                                                                                               INDUCTOR, European symbol                             
2   20uH                     L-EUL1812                            L1812                               L0941, L0943                                                                                                                                      INDUCTOR, European symbol                             

1   KSR223GLFG               KSR223G_SMD_1POL                     KSR223G_SMD_1POL                    S0212                                                                                                                                             KSR223G                                               

1   SAMTEC SMA-J-P-H-RA-TH1  SMA_SMT_AMPHENOL-901-143             SMA_SMT_AMPHENOL_901-143            X1511                                                                                                                                             RF/COAXIAL, SMA JACK, R/A, 50OHM, THD                 
1   SMA_SMT_AMPHENOL-901-143 SMA_SMT_AMPHENOL-901-143             SMA_SMT_AMPHENOL_901-143            X1501                                                                                                                                             RF/COAXIAL, SMA JACK, R/A, 50OHM, THD                 

1   MOLEX 105017-0001        USB_MICRO-B_MOLEX                    USB-B-MICRO-SMD_MOLEX-105017-0001   X1401                                                                                                                                             USB Type Micro-B Connector                            

1   FTSH-105-01-F-D-K        2X05_1MM27_SHROUDED_CORTEX_JTAG_SWD" 2X05_1MM27_SHROUDED_CORTEX_JTAG_SWD X0201                                                                                                                                             Header 2X5 1.27mm 0.05" shrouded - CORTEX JTAG-SWD    
2                            2X10_2MM56_SOCKET                    2X10                                X1601, X1602                                                                                                                                      Header 2X10 2.54mm                                    
1                            HEADER-1X2                           1X02                                X0222                                                                                                                                             Header 1X2 2.54mm                                     
1                            HEADER-2X2                           2X02                                X0501                                                                                                                                             Header 2X2 2.54mm                                     

7   WIRE-TO-BOARD_5MM08_1X02 WIRE-TO-BOARD_5MM08_1X02             WIRE-TO-BOARD_5MM08_1X02            X1051, X1052, X1053, X1151, X1152, X1153, X1211                                                                                                   Wire-to-Board connector 5.08mm 1x02                   

<EOF>

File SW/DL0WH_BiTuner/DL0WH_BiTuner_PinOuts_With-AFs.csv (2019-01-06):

Position | Name | Type | Signal | Label | AF0 | AF1 | AF2 | AF3 | AF4 | AF5 | AF6 | AF7 | AF8 | AF9 | AF10 | AF11 | AF12 | AF13 | AF14 | AF15
1 | VBAT | Power
2 | PC13 | I/O | RTC_TS |  |  |  |  |  |  |  |  |  |  |  |  |  |  |  |  | EVENTOUT
3 | PC14-OSC32_IN (PC14) | I/O | RCC_OSC32_IN |  |  |  |  |  |  |  |  |  |  |  |  |  |  |  |  | EVENTOUT
4 | PC15-OSC32_OUT (PC15) | I/O | RCC_OSC32_OUT |  |  |  |  |  |  |  |  |  |  |  |  |  |  |  |  | EVENTOUT
5 | PH0-OSC_IN (PH0) | I/O | RCC_OSC_IN |  |  |  |  |  |  |  |  |  |  |  |  |  |  |  |  | EVENTOUT
6 | PH1-OSC_OUT (PH1) | I/O | RCC_OSC_OUT |  |  |  |  |  |  |  |  |  |  |  |  |  |  |  |  | EVENTOUT
7 | NRST | Reset
8 | PC0 | I/O | ADC1_IN1 ADC2_IN1 | ADC2_IN1_FWDREV |  | LPTIM1_IN1 |  |  | I2C3_SCL |  | DFSDM1_DATIN4 |  | LPUART1_RX |  |  | LCD_SEG18 |  |  | LPTIM2_IN1 | EVENTOUT
9 | PC1 | I/O | LPUART1_TX |  |  | LPTIM1_OUT |  |  | I2C3_SDA |  | DFSDM1_CKIN4 |  | LPUART1_TX |  |  | LCD_SEG19 |  |  |  | EVENTOUT
10 | PC2 | I/O | ADC2_IN3 ADC3_IN3 | ADC3_IN3_VDIODE |  | LPTIM1_IN2 |  |  |  | SPI2_MISO | DFSDM1_CKOUT |  |  |  |  | LCD_SEG20 |  |  |  | EVENTOUT
11 | PC3 | Output | GPIO_Output | GPIO_SWR_SEL_FWD |  | LPTIM1_ETR |  |  |  | SPI2_MOSI |  |  |  |  |  | LCD_VLCD |  | SAI1_SD_A | LPTIM2_ETR | EVENTOUT
12 | VSSA/VREF- | Power
13 | VDDA/VREF+ | Power
14 | PA0 | I/O | UART4_TX |  |  | TIM2_CH1 | TIM5_CH1 | TIM8_ETR |  |  |  | USART2_CTS | UART4_TX |  |  |  |  | SAI1_EXTCLK | TIM2_ETR | EVENTOUT
15 | PA1 | I/O | UART4_RX |  |  | TIM2_CH2 | TIM5_CH2 |  |  |  |  | USART2_DE/USART2_RTS | UART4_RX |  |  | LCD_SEG0 |  |  | TIM15_CH1N | EVENTOUT
16 | PA2 | I/O | SYS_WKUP4 |  |  | TIM2_CH3 | TIM5_CH3 |  |  |  |  | USART2_TX |  |  |  | LCD_SEG1 |  | SAI2_EXTCLK | TIM15_CH1 | EVENTOUT
17 | PA3 | Output | GPIO_Output | GPIO_SWR_SEL_REV |  | TIM2_CH4 | TIM5_CH4 |  |  |  |  | USART2_RX |  |  |  | LCD_SEG2 |  |  | TIM15_CH2 | EVENTOUT
18 | VSS | Power
19 | VDD | Power
20 | PA4 | I/O | DAC1_OUT1 |  |  |  |  |  |  | SPI1_NSS | SPI3_NSS | USART2_CK |  |  |  |  |  | SAI1_FS_B | LPTIM2_OUT | EVENTOUT
21 | PA5 | I/O | SPI1_SCK |  |  | TIM2_CH1 | TIM2_ETR | TIM8_CH1N |  | SPI1_SCK |  |  |  |  |  |  |  |  | LPTIM2_ETR | EVENTOUT
22 | PA6 | I/O | SPI1_MISO |  |  | TIM1_BKIN | TIM3_CH1 | TIM8_BKIN |  | SPI1_MISO |  | USART3_CTS |  |  | QUADSPI_BK1_IO3 | LCD_SEG3 | TIM1_BKIN_COMP2 | TIM8_BKIN_COMP2 | TIM16_CH1 | EVENTOUT
23 | PA7 | I/O | SPI1_MOSI |  |  | TIM1_CH1N | TIM3_CH2 | TIM8_CH1N |  | SPI1_MOSI |  |  |  |  | QUADSPI_BK1_IO2 | LCD_SEG4 |  |  | TIM17_CH1 | EVENTOUT
24 | PC4 | Output | GPIO_Output | GPIO_SPI_RST |  |  |  |  |  |  |  | USART3_TX |  |  |  | LCD_SEG22 |  |  |  | EVENTOUT
25 | PC5 | I/O | COMP1_INP |  |  |  |  |  |  |  |  | USART3_RX |  |  |  | LCD_SEG23 |  |  |  | EVENTOUT
26 | PB0 | Output | GPIO_Output | GPIO_SPI_SEL_L |  | TIM1_CH2N | TIM3_CH3 | TIM8_CH2N |  |  |  | USART3_CK |  |  | QUADSPI_BK1_IO1 | LCD_SEG5 | COMP1_OUT |  |  | EVENTOUT
27 | PB1 | Output | GPIO_Output | GPIO_SPI_SEL_C |  | TIM1_CH3N | TIM3_CH4 | TIM8_CH3N |  |  | DFSDM1_DATIN0 | USART3_DE/USART3_RTS |  |  | QUADSPI_BK1_IO0 | LCD_SEG6 |  |  | LPTIM2_IN1 | EVENTOUT
28 | PB2 | Output | GPIO_Output | GPIO_SPI_SEL_EXT | RTC_OUT_ALARM/RTC_OUT_CALIB | LPTIM1_OUT |  |  | I2C3_SMBA |  | DFSDM1_CKIN0 |  |  |  |  |  |  |  |  | EVENTOUT
29 | PB10 | I/O | LPUART1_RX |  |  | TIM2_CH3 |  |  | I2C2_SCL | SPI2_SCK | DFSDM1_DATIN7 | USART3_TX | LPUART1_RX |  | QUADSPI_CLK | LCD_SEG10 | COMP1_OUT | SAI1_SCK_A |  | EVENTOUT
30 | PB11 | Output | GPIO_Output | GPIO_SPI_PWM |  | TIM2_CH4 |  |  | I2C2_SDA |  | DFSDM1_CKIN7 | USART3_RX | LPUART1_TX |  | QUADSPI_NCS | LCD_SEG11 | COMP2_OUT |  |  | EVENTOUT
31 | VSS | Power
32 | VDD | Power
33 | PB12 | I/O | LPUART1_RTS |  |  | TIM1_BKIN |  | TIM1_BKIN_COMP2 | I2C2_SMBA | SPI2_NSS | DFSDM1_DATIN1 | USART3_CK | LPUART1_DE/LPUART1_RTS | TSC_G1_IO1 |  | LCD_SEG12 | SWPMI1_IO | SAI2_FS_A | TIM15_BKIN | EVENTOUT
34 | PB13 | I/O | LPUART1_CTS |  |  | TIM1_CH1N |  |  | I2C2_SCL | SPI2_SCK | DFSDM1_CKIN1 | USART3_CTS | LPUART1_CTS | TSC_G1_IO2 |  | LCD_SEG13 | SWPMI1_TX | SAI2_SCK_A | TIM15_CH1N | EVENTOUT
35 | PB14 | I/O |  |  |  | TIM1_CH2N |  | TIM8_CH2N | I2C2_SDA | SPI2_MISO | DFSDM1_DATIN2 | USART3_DE/USART3_RTS |  | TSC_G1_IO3 |  | LCD_SEG14 | SWPMI1_RX | SAI2_MCLK_A | TIM15_CH1 | EVENTOUT
36 | PB15 | I/O |  |  | RTC_REFIN | TIM1_CH3N |  | TIM8_CH3N |  | SPI2_MOSI | DFSDM1_CKIN2 |  |  | TSC_G1_IO4 |  | LCD_SEG15 | SWPMI1_SUSPEND | SAI2_SD_A | TIM15_CH2 | EVENTOUT
37 | PC6 | I/O |  |  |  |  | TIM3_CH1 | TIM8_CH1 |  |  | DFSDM1_CKIN3 |  |  | TSC_G4_IO1 |  | LCD_SEG24 | SDMMC1_D6 | SAI2_MCLK_A |  | EVENTOUT
38 | PC7 | I/O |  |  |  |  | TIM3_CH2 | TIM8_CH2 |  |  | DFSDM1_DATIN3 |  |  | TSC_G4_IO2 |  | LCD_SEG25 | SDMMC1_D7 | SAI2_MCLK_B |  | EVENTOUT
39 | PC8 | I/O |  |  |  |  | TIM3_CH3 | TIM8_CH3 |  |  |  |  |  | TSC_G4_IO3 |  | LCD_SEG26 | SDMMC1_D0 |  |  | EVENTOUT
40 | PC9 | I/O |  |  |  | TIM8_BKIN2 | TIM3_CH4 | TIM8_CH4 |  |  |  |  |  | TSC_G4_IO4 | USB_OTG_FS_NOE | LCD_SEG27 | SDMMC1_D1 | SAI2_EXTCLK | TIM8_BKIN2_COMP1 | EVENTOUT
41 | PA8 | I/O | USB_OTG_FS_SOF |  | RCC_MCO | TIM1_CH1 |  |  |  |  |  | USART1_CK |  |  | USB_OTG_FS_SOF | LCD_COM0 |  |  | LPTIM2_OUT | EVENTOUT
42 | PA9 | I/O | USB_OTG_FS_VBUS |  |  | TIM1_CH2 |  |  |  |  |  | USART1_TX |  |  |  | LCD_COM1 |  |  | TIM15_BKIN | EVENTOUT
43 | PA10 | I/O | USB_OTG_FS_ID |  |  | TIM1_CH3 |  |  |  |  |  | USART1_RX |  |  | USB_OTG_FS_ID | LCD_COM2 |  |  | TIM17_BKIN | EVENTOUT
44 | PA11 | I/O | USB_OTG_FS_DM |  |  | TIM1_CH4 | TIM1_BKIN2 |  |  |  |  | USART1_CTS |  | CAN1_RX | USB_OTG_FS_DM |  | TIM1_BKIN2_COMP1 |  |  | EVENTOUT
45 | PA12 | I/O | USB_OTG_FS_DP |  |  | TIM1_ETR |  |  |  |  |  | USART1_DE/USART1_RTS |  | CAN1_TX | USB_OTG_FS_DP |  |  |  |  | EVENTOUT
46 | PA13 (JTMS-SWDIO) | I/O | SYS_JTMS-SWDIO |  | SYS_JTMS-SWDIO | IR_OUT |  |  |  |  |  |  |  |  | USB_OTG_FS_NOE |  |  |  |  | EVENTOUT
47 | VSS | Power
48 | VDDUSB | Power
49 | PA14 (JTCK-SWCLK) | I/O | SYS_JTCK-SWCLK |  | SYS_JTCK-SWCLK |  |  |  |  |  |  |  |  |  |  |  |  |  |  | EVENTOUT
50 | PA15 (JTDI) | I/O | UART4_RTS |  | SYS_JTDI | TIM2_CH1 | TIM2_ETR |  |  | SPI1_NSS | SPI3_NSS |  | UART4_DE/UART4_RTS | TSC_G3_IO1 |  | LCD_SEG17 |  | SAI2_FS_B |  | EVENTOUT
51 | PC10 | I/O |  |  |  |  |  |  |  |  | SPI3_SCK | USART3_TX | UART4_TX | TSC_G3_IO2 |  | LCD_COM4/LCD_SEG28/LCD_SEG40 | SDMMC1_D2 | SAI2_SCK_B |  | EVENTOUT
52 | PC11 | I/O |  |  |  |  |  |  |  |  | SPI3_MISO | USART3_RX | UART4_RX | TSC_G3_IO3 |  | LCD_COM5/LCD_SEG29/LCD_SEG41 | SDMMC1_D3 | SAI2_MCLK_B |  | EVENTOUT
53 | PC12 | I/O |  |  |  |  |  |  |  |  | SPI3_MOSI | USART3_CK | UART5_TX | TSC_G3_IO4 |  | LCD_COM6/LCD_SEG30/LCD_SEG42 | SDMMC1_CK | SAI2_SD_B |  | EVENTOUT
54 | PD2 | I/O |  |  |  |  | TIM3_ETR |  |  |  |  | USART3_DE/USART3_RTS | UART5_RX | TSC_SYNC |  | LCD_COM7/LCD_SEG31/LCD_SEG43 | SDMMC1_CMD |  |  | EVENTOUT
55 | PB3 (JTDO-TRACESWO) | I/O |  |  | SYS_JTDO-SWO | TIM2_CH2 |  |  |  | SPI1_SCK | SPI3_SCK | USART1_DE/USART1_RTS |  |  |  | LCD_SEG7 |  | SAI1_SCK_B |  | EVENTOUT
56 | PB4 (NJTRST) | I/O | COMP2_INP |  | SYS_JTRST |  | TIM3_CH1 |  |  | SPI1_MISO | SPI3_MISO | USART1_CTS | UART5_DE/UART5_RTS | TSC_G2_IO1 |  | LCD_SEG8 |  | SAI1_MCLK_B | TIM17_BKIN | EVENTOUT
57 | PB5 | I/O |  |  |  | LPTIM1_IN1 | TIM3_CH2 |  | I2C1_SMBA | SPI1_MOSI | SPI3_MOSI | USART1_CK | UART5_CTS | TSC_G2_IO2 |  | LCD_SEG9 | COMP2_OUT | SAI1_SD_B | TIM16_BKIN | EVENTOUT
58 | PB6 | I/O | I2C1_SCL |  |  | LPTIM1_ETR | TIM4_CH1 | TIM8_BKIN2 | I2C1_SCL |  | DFSDM1_DATIN5 | USART1_TX |  | TSC_G2_IO3 |  |  | TIM8_BKIN2_COMP2 | SAI1_FS_B | TIM16_CH1N | EVENTOUT
59 | PB7 | I/O | UART4_CTS |  |  | LPTIM1_IN2 | TIM4_CH2 | TIM8_BKIN | I2C1_SDA |  | DFSDM1_CKIN5 | USART1_RX | UART4_CTS | TSC_G2_IO4 |  | LCD_SEG21 |  | TIM8_BKIN_COMP1 | TIM17_CH1N | EVENTOUT
60 | BOOT0 | Boot
61 | PB8 | I/O |  |  |  |  | TIM4_CH3 |  | I2C1_SCL |  | DFSDM1_DATIN6 |  |  | CAN1_RX |  | LCD_SEG16 | SDMMC1_D4 | SAI1_MCLK_A | TIM16_CH1 | EVENTOUT
62 | PB9 | I/O | I2C1_SDA |  |  | IR_OUT | TIM4_CH4 |  | I2C1_SDA | SPI2_NSS | DFSDM1_CKIN6 |  |  | CAN1_TX |  | LCD_COM3 | SDMMC1_D5 | SAI1_FS_A | TIM17_CH1 | EVENTOUT
63 | VSS | Power
64 | VDD | Power

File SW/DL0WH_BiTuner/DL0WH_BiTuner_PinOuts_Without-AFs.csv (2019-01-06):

Position | Name | Type | Signal | Label
1 | VBAT | Power
2 | PC13 | I/O | RTC_TS
3 | PC14-OSC32_IN (PC14) | I/O | RCC_OSC32_IN
4 | PC15-OSC32_OUT (PC15) | I/O | RCC_OSC32_OUT
5 | PH0-OSC_IN (PH0) | I/O | RCC_OSC_IN
6 | PH1-OSC_OUT (PH1) | I/O | RCC_OSC_OUT
7 | NRST | Reset
8 | PC0 | I/O | ADC1_IN1 ADC2_IN1 | ADC2_IN1_FWDREV
9 | PC1 | I/O | LPUART1_TX
10 | PC2 | I/O | ADC2_IN3 ADC3_IN3 | ADC3_IN3_VDIODE
11 | PC3 | Output | GPIO_Output | GPIO_SWR_SEL_FWD
12 | VSSA/VREF- | Power
13 | VDDA/VREF+ | Power
14 | PA0 | I/O | UART4_TX
15 | PA1 | I/O | UART4_RX
16 | PA2 | I/O | SYS_WKUP4
17 | PA3 | Output | GPIO_Output | GPIO_SWR_SEL_REV
18 | VSS | Power
19 | VDD | Power
20 | PA4 | I/O | DAC1_OUT1
21 | PA5 | I/O | SPI1_SCK
22 | PA6 | I/O | SPI1_MISO
23 | PA7 | I/O | SPI1_MOSI
24 | PC4 | Output | GPIO_Output | GPIO_SPI_RST
25 | PC5 | I/O | COMP1_INP
26 | PB0 | Output | GPIO_Output | GPIO_SPI_SEL_L
27 | PB1 | Output | GPIO_Output | GPIO_SPI_SEL_C
28 | PB2 | Output | GPIO_Output | GPIO_SPI_SEL_EXT
29 | PB10 | I/O | LPUART1_RX
30 | PB11 | Output | GPIO_Output | GPIO_SPI_PWM
31 | VSS | Power
32 | VDD | Power
33 | PB12 | I/O | LPUART1_RTS
34 | PB13 | I/O | LPUART1_CTS
35 | PB14 | I/O
36 | PB15 | I/O
37 | PC6 | I/O
38 | PC7 | I/O
39 | PC8 | I/O
40 | PC9 | I/O
41 | PA8 | I/O | USB_OTG_FS_SOF
42 | PA9 | I/O | USB_OTG_FS_VBUS
43 | PA10 | I/O | USB_OTG_FS_ID
44 | PA11 | I/O | USB_OTG_FS_DM
45 | PA12 | I/O | USB_OTG_FS_DP
46 | PA13 (JTMS-SWDIO) | I/O | SYS_JTMS-SWDIO
47 | VSS | Power
48 | VDDUSB | Power
49 | PA14 (JTCK-SWCLK) | I/O | SYS_JTCK-SWCLK
50 | PA15 (JTDI) | I/O | UART4_RTS
51 | PC10 | I/O
52 | PC11 | I/O
53 | PC12 | I/O
54 | PD2 | I/O
55 | PB3 (JTDO-TRACESWO) | I/O
56 | PB4 (NJTRST) | I/O | COMP2_INP
57 | PB5 | I/O
58 | PB6 | I/O | I2C1_SCL
59 | PB7 | I/O | UART4_CTS
60 | BOOT0 | Boot
61 | PB8 | I/O
62 | PB9 | I/O | I2C1_SDA
63 | VSS | Power
64 | VDD | Power

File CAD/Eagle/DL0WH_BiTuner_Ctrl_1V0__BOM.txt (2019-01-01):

Stückliste exportiert aus /Users/espero/nfs_ds_nfs/git/DL0WH_BiTuner/CAD/Eagle/DL0WH_BiTuner_MCU_1V0.sch am 01.01.19 19:52

Qty Value                    Device                                Package                           Parts                                                                                                                                             Digikey

2   0R                       R-EU_R0402                            R0402                             R0441, R9622                                                                                                                                      =541-0.0YBCT-ND
1   3R                       R-EU_R0402                            R0402                             R2411                                                                                                                                             =541-3.00YCT-ND
21  47R                      R-EU_R0402                            R0402                             R8921, R8922, R8952, R9411, R9424, R9511, R9524, R9611, R9621, R9623, R9624, R9625, R9626, R9801, R9802, R9803, R9804, R9901, R9902, R9903, R9904 =P47.0LCT-ND
4   1kR                      R-EU_R0402                            R0402                             R0611, R0612, R8901, R8911                                                                                                                        =RR05P1.0KDCT-ND
1   10kR                     R-EU_R0402                            R0402                             R8961                                                                                                                                             =RR05P10.0KDCT-ND
2   15kR                     R-EU_R0402                            R0402                             R8902, R8912                                                                                                                                      =RR05P15.0KDCT-ND
1   33kR                     R-EU_R0402                            R0402                             R0221                                                                                                                                             =RR05P33.0KDCT-ND‎
3   100kR                    R-EU_R0402                            R0402                             R8903, R8913, R9001                                                                                                                               =RR05P100KDCT-ND
3   220kR                    R-EU_R0402                            R0402                             R0231, R0232, R9002                                                                                                                               =P220KLCT-ND
1   330kR                    R-EU_R0402                            R0402                             R3202                                                                                                                                             =P330KLCT-ND
3   1MR                      R-EU_R0402                            R0402                             R8951, R9021, R9022                                                                                                                               =P1.00MLCT-ND
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

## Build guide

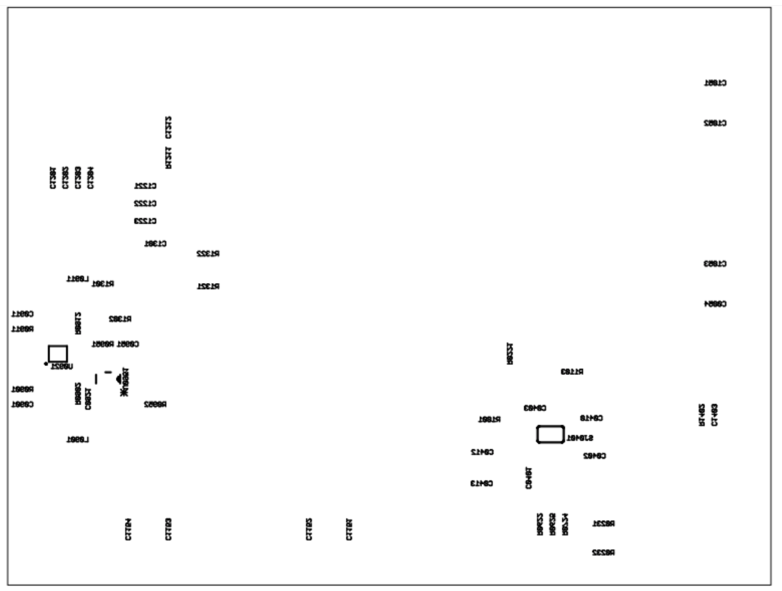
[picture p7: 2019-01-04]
CAD/Eagle/Manufacturing/Pictures/HW_1V0/Bottom_Silkscreen.png

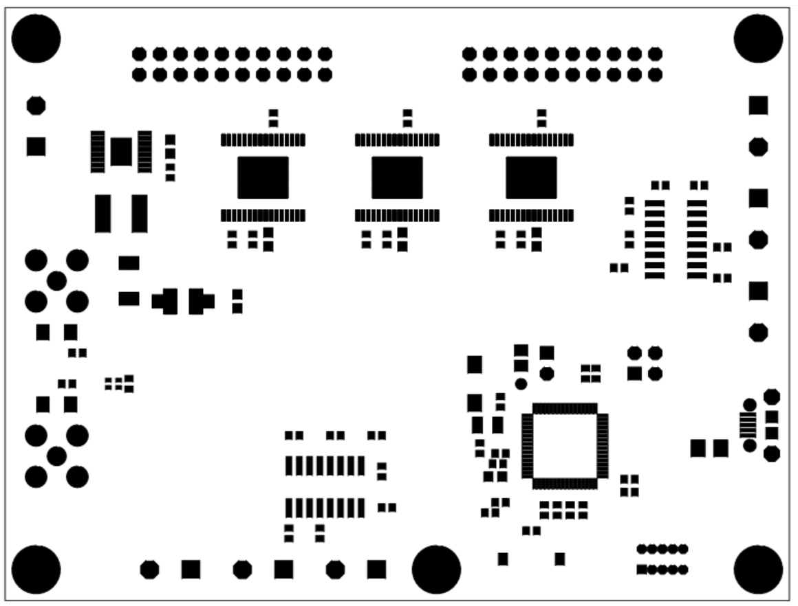
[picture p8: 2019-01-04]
CAD/Eagle/Manufacturing/Pictures/HW_1V0/Top_Soldermask.png

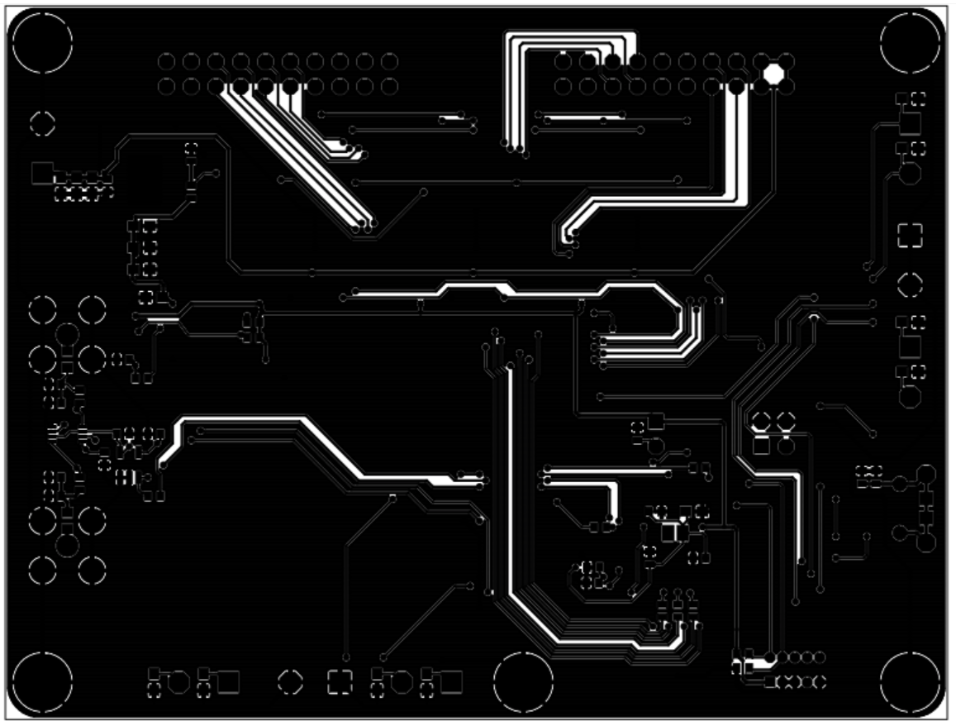
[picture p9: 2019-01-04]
CAD/Eagle/Manufacturing/Pictures/HW_1V1/Bottom_Copper.png

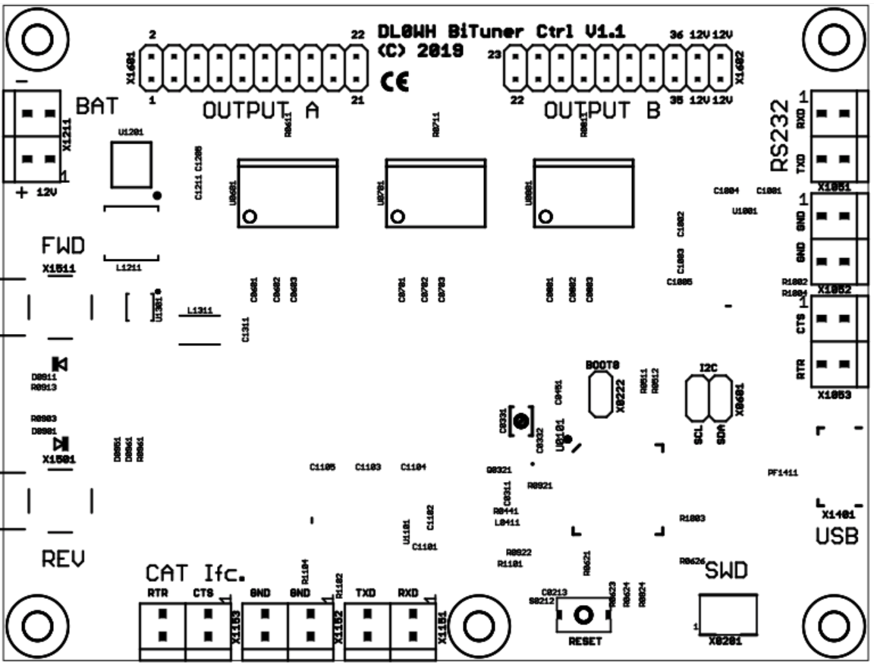
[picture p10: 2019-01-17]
CAD/Eagle/Manufacturing/Pictures/HW_1V1/Top_Silkscreen.png

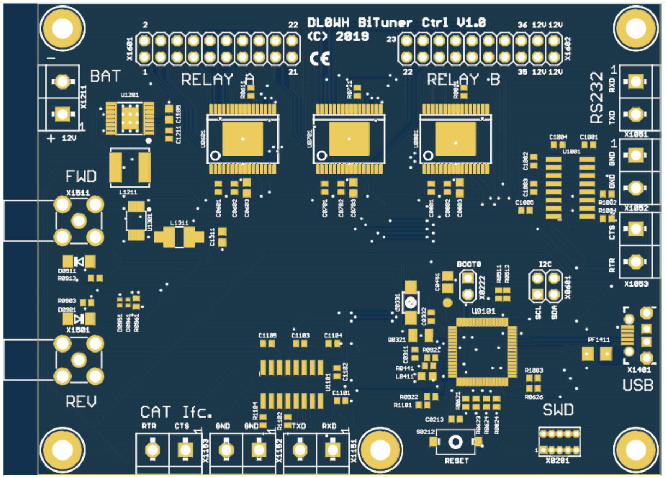
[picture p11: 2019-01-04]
CAD/Eagle/Manufacturing/Pictures/HW_1V0/Top.png

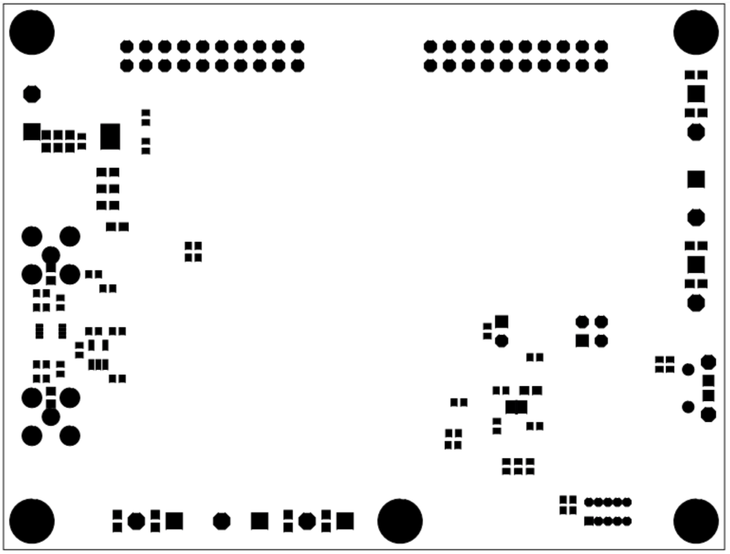
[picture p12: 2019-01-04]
CAD/Eagle/Manufacturing/Pictures/HW_1V0/Bottom_Soldermask.png

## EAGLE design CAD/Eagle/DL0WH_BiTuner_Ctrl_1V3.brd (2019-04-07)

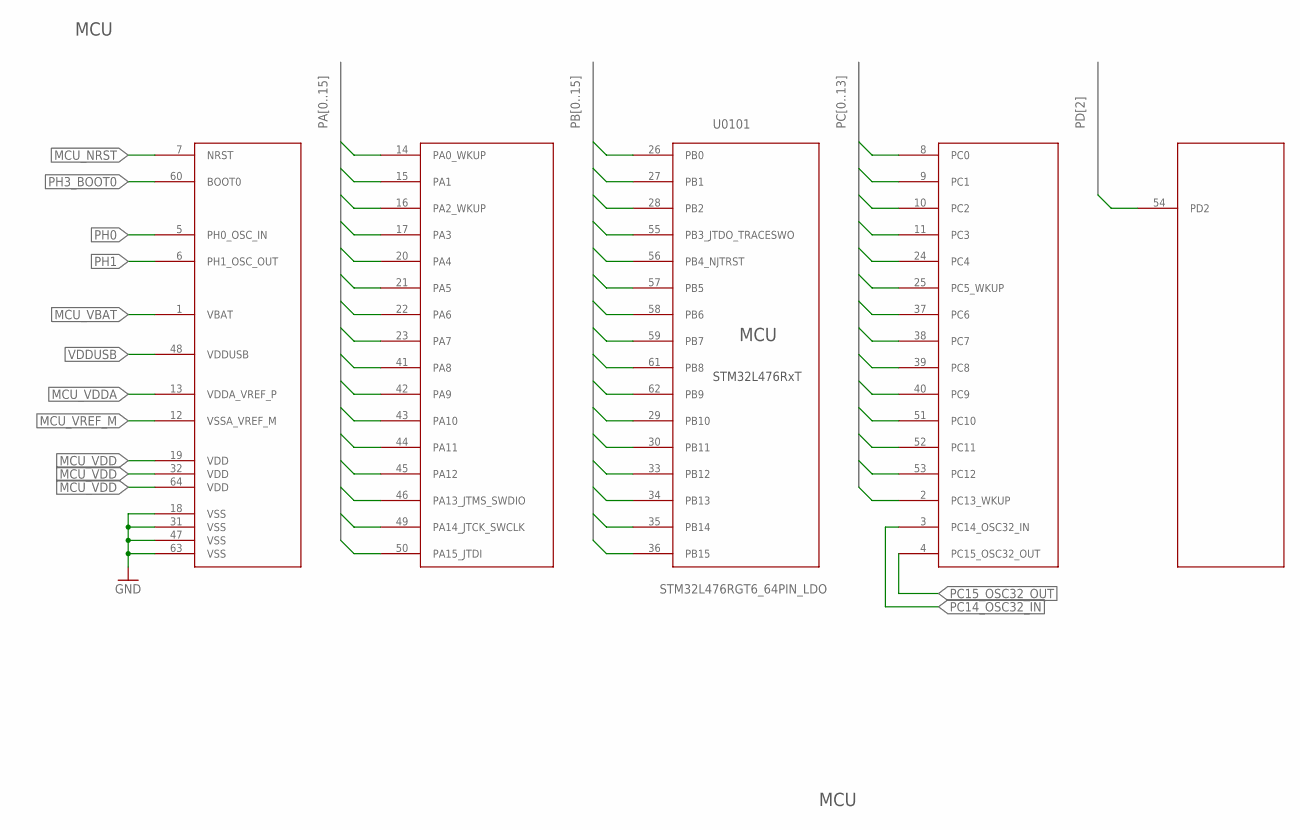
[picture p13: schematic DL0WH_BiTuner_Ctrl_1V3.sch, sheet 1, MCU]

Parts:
U0101: STM32L476RGT6_64PIN_LDO; LQFP64

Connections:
GND: U0101.18 (VSS), U0101.31 (VSS), U0101.47 (VSS), U0101.63 (VSS); also elsewhere on the board
MCU_NRST: U0101.7 (NRST); also elsewhere on the board
MCU_VBAT: U0101.1 (VBAT); also elsewhere on the board
MCU_VDD: U0101.19 (VDD), U0101.32 (VDD), U0101.64 (VDD); also elsewhere on the board
MCU_VDDA: U0101.13 (VDDA_VREF_P); also elsewhere on the board
MCU_VREF_M: U0101.12 (VSSA_VREF_M); also elsewhere on the board
PA0: U0101.14 (PA0_WKUP); also elsewhere on the board
PA1: U0101.15 (PA1); also elsewhere on the board
PA2: U0101.16 (PA2_WKUP)
PA3: U0101.17 (PA3); also elsewhere on the board
PA4: U0101.20 (PA4)
PA5: U0101.21 (PA5); also elsewhere on the board
PA6: U0101.22 (PA6); also elsewhere on the board
PA7: U0101.23 (PA7); also elsewhere on the board
PA8: U0101.41 (PA8)
PA9: U0101.42 (PA9); also elsewhere on the board
PA10: U0101.43 (PA10); also elsewhere on the board
PA11: U0101.44 (PA11); also elsewhere on the board
PA12: U0101.45 (PA12); also elsewhere on the board
PA13: U0101.46 (PA13_JTMS_SWDIO); also elsewhere on the board
PA14: U0101.49 (PA14_JTCK_SWCLK); also elsewhere on the board
PA15: U0101.50 (PA15_JTDI); also elsewhere on the board
PB0: U0101.26 (PB0); also elsewhere on the board
PB1: U0101.27 (PB1); also elsewhere on the board
PB2: U0101.28 (PB2); also elsewhere on the board
PB3: U0101.55 (PB3_JTDO_TRACESWO)
PB4: U0101.56 (PB4_NJTRST)
PB5: U0101.57 (PB5)
PB6: U0101.58 (PB6); also elsewhere on the board
PB7: U0101.59 (PB7); also elsewhere on the board
PB8: U0101.61 (PB8)
PB9: U0101.62 (PB9); also elsewhere on the board
PB10: U0101.29 (PB10); also elsewhere on the board
PB11: U0101.30 (PB11); also elsewhere on the board
PB12: U0101.33 (PB12); also elsewhere on the board
PB13: U0101.34 (PB13); also elsewhere on the board
PB14: U0101.35 (PB14)
PB15: U0101.36 (PB15)
PC0: U0101.8 (PC0); also elsewhere on the board
PC1: U0101.9 (PC1); also elsewhere on the board
PC2: U0101.10 (PC2); also elsewhere on the board
PC3: U0101.11 (PC3); also elsewhere on the board
PC4: U0101.24 (PC4); also elsewhere on the board
PC5: U0101.25 (PC5_WKUP)
PC6: U0101.37 (PC6)
PC7: U0101.38 (PC7)
PC8: U0101.39 (PC8)
PC9: U0101.40 (PC9)
PC10: U0101.51 (PC10)
PC11: U0101.52 (PC11)
PC12: U0101.53 (PC12)
PC13: U0101.2 (PC13_WKUP)
PC14_OSC32_IN: U0101.3 (PC14_OSC32_IN); also elsewhere on the board
PC15_OSC32_OUT: U0101.4 (PC15_OSC32_OUT); also elsewhere on the board
PD2: U0101.54 (PD2)
PH0: U0101.5 (PH0_OSC_IN)
PH1: U0101.6 (PH1_OSC_OUT)
PH3_BOOT0: U0101.60 (BOOT0); also elsewhere on the board
VDDUSB: U0101.48 (VDDUSB); also elsewhere on the board

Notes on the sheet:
STM32L476RxT
MCU

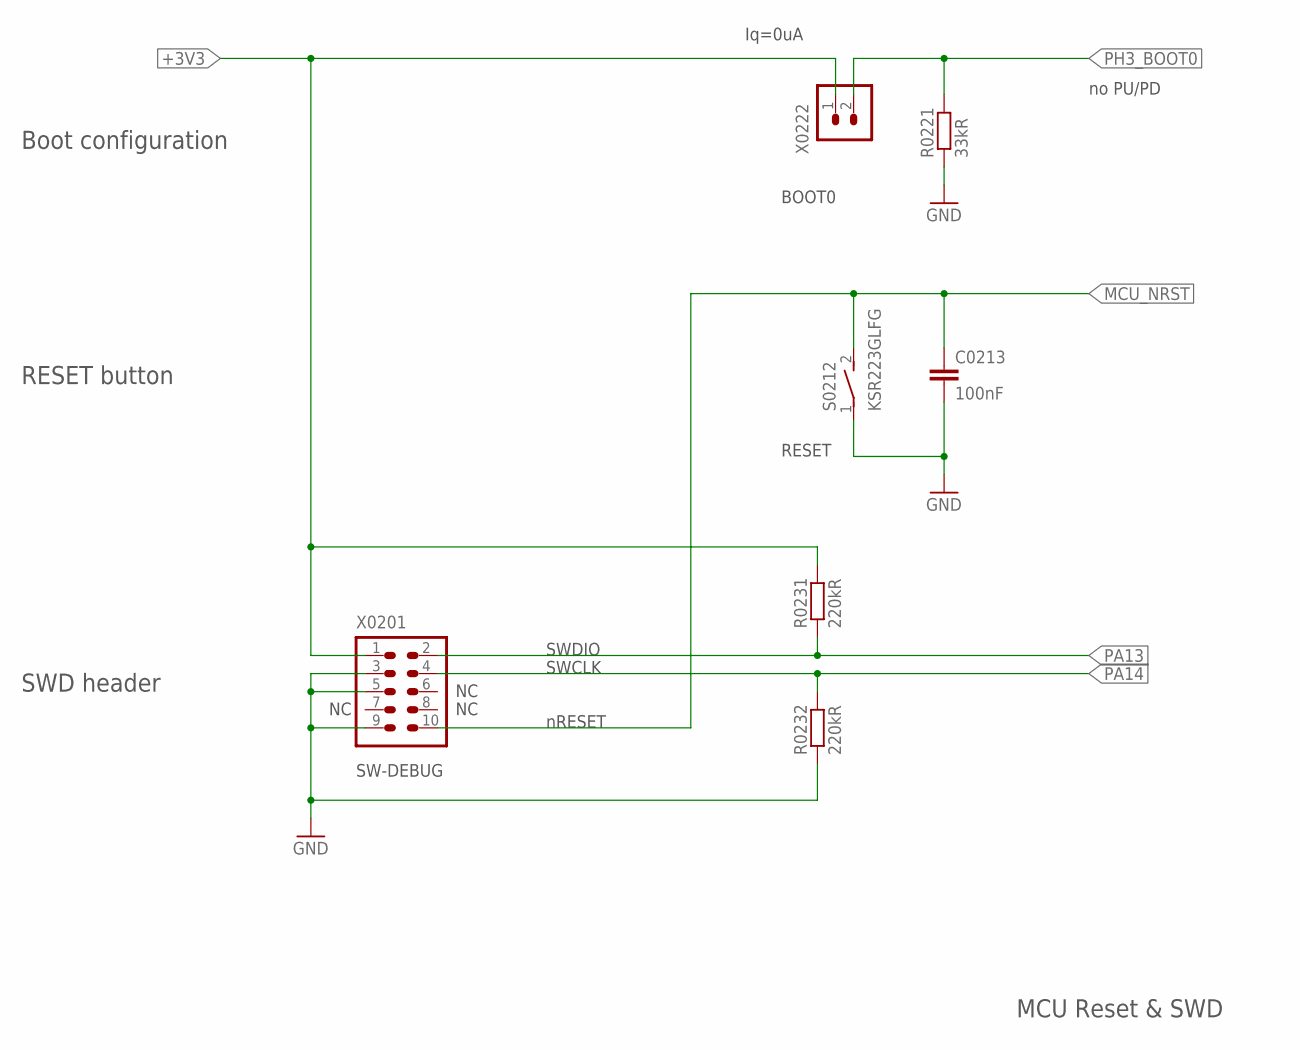
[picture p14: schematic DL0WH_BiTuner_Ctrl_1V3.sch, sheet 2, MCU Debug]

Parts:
C0213: 100nF; C0402
R0221: 33kR; R0402
R0231, R0232: 220kR; R0402
S0212: KSR223GLFG; KSR223G_SMD_1POL
X0201: FTSH-105-01-F-D-K; 2X05_1MM27_SHROUDED_CORTEX_JTAG_SWD
X0222: HEADER-1X2; 1X02

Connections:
+3V3: R0231.2, X0201.1, X0222.1; also elsewhere on the board
GND: C0213.2, R0221.1, R0232.1, S0212.1, X0201.3, X0201.5, X0201.9; also elsewhere on the board
MCU_NRST: C0213.1, S0212.2 (S), X0201.10; also elsewhere on the board
PA13: R0231.1, X0201.2; also elsewhere on the board
PA14: R0232.2, X0201.4; also elsewhere on the board
PH3_BOOT0: R0221.2, X0222.2; also elsewhere on the board

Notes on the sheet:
SWDIO
SWCLK
RESET
BOOT0
SW-DEBUG
SWD header
Boot configuration
RESET button
nRESET
MCU Reset & SWD
no PU/PD
Iq=0uA

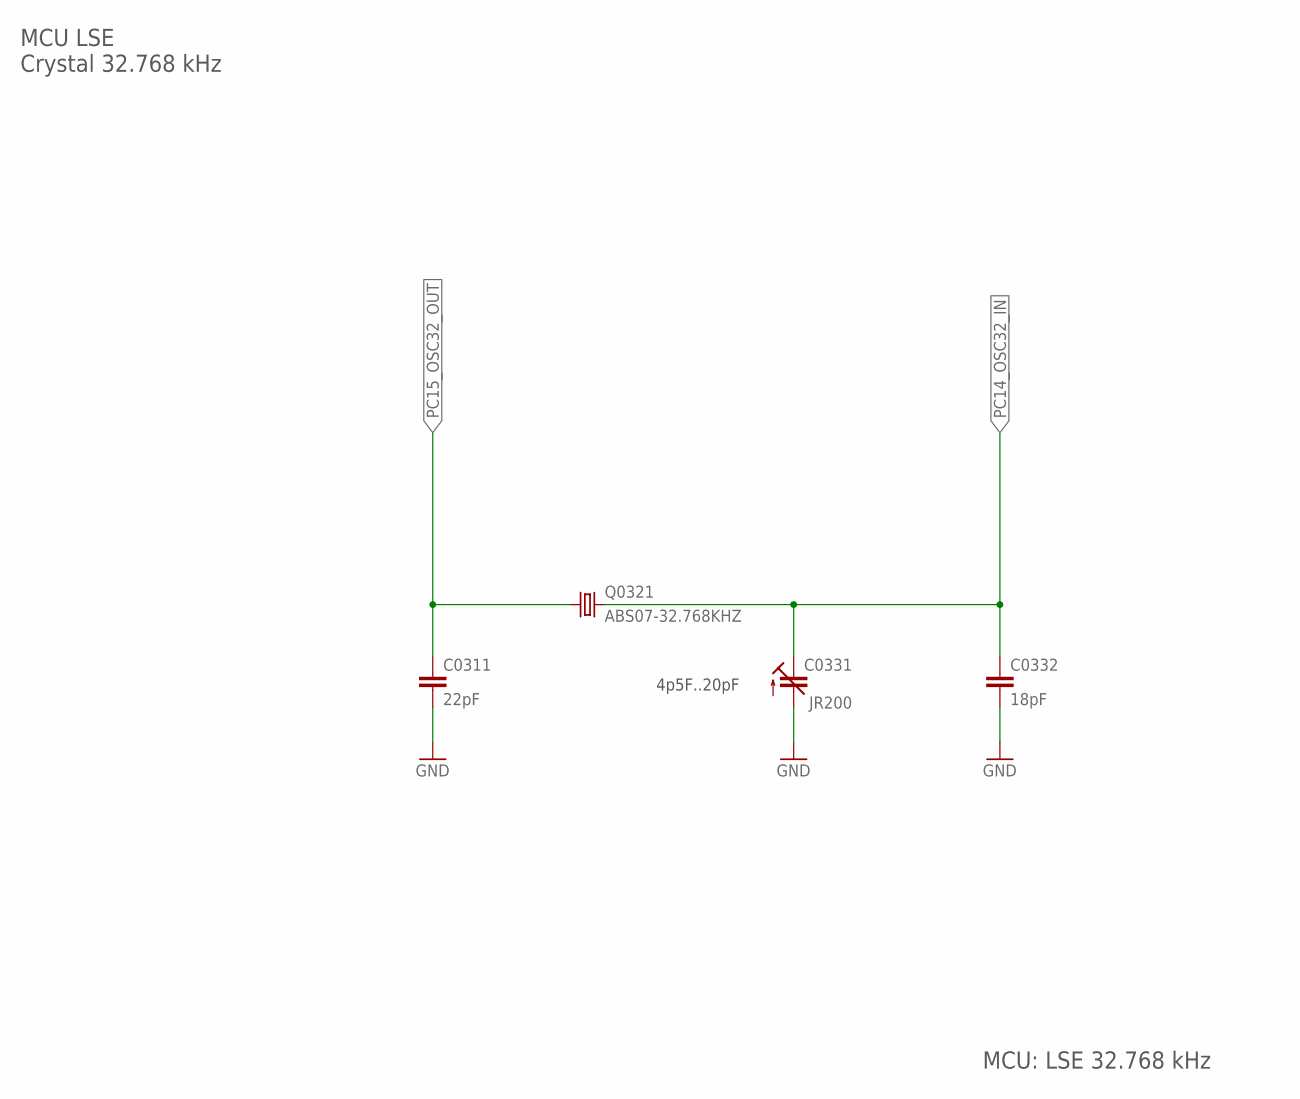
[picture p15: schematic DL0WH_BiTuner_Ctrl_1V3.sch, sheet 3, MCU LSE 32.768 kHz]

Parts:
C0311: 22pF; C0402
C0331: JR200; 3MM2_X_2MM5
C0332: 18pF; C0402
Q0321: ABS07-32.768KHZ; ABS07

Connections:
GND: C0311.2, C0331.+ (A), C0332.2; also elsewhere on the board
PC14_OSC32_IN: C0331.- (E), C0332.1, Q0321.2; also elsewhere on the board
PC15_OSC32_OUT: C0311.1, Q0321.1; also elsewhere on the board

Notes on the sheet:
4p5F..20pF
MCU LSE Crystal 32.768 kHz
MCU: LSE 32.768 kHz

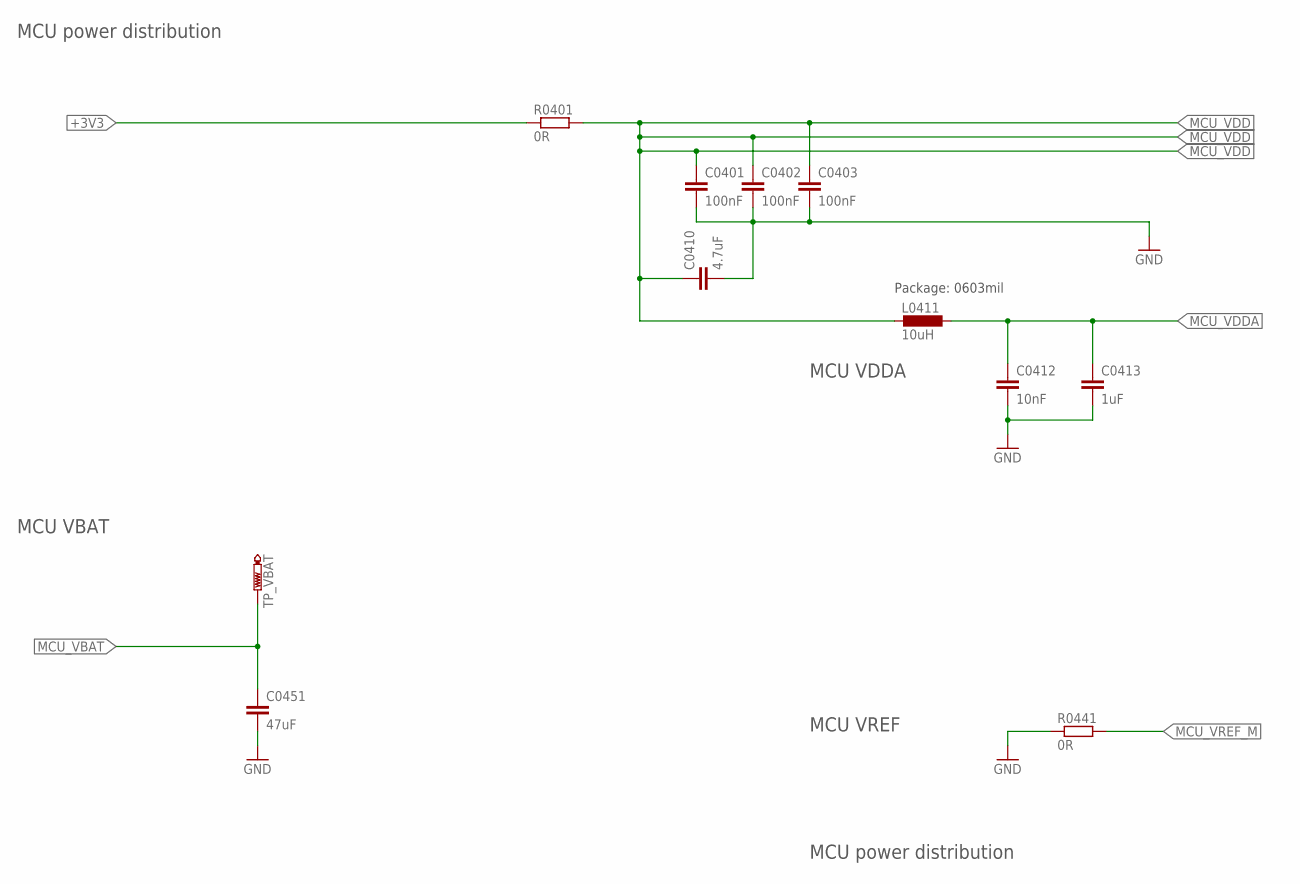
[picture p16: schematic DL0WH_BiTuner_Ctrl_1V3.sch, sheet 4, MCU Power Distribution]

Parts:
C0401, C0402, C0403: 100nF; C0402
C0410: 4.7uF; C0603
C0412: 10nF; C0402
C0413: 1uF; C0402
C0451: 47uF; C0805
L0411: 10uH; L0603
R0401, R0441: 0R; R0402
TP_VBAT: PTR1B1,27; B1,27

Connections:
+3V3: R0401.1; also elsewhere on the board
GND: C0401.2, C0402.2, C0403.2, C0410.2, C0412.2, C0413.2, C0451.2, R0441.1; also elsewhere on the board
MCU_VBAT: C0451.1, TP_VBAT.TP; also elsewhere on the board
MCU_VDD: C0401.1, C0402.1, C0403.1, C0410.1, L0411.1, R0401.2; also elsewhere on the board
MCU_VDDA: C0412.1, C0413.1, L0411.2; also elsewhere on the board
MCU_VREF_M: R0441.2; also elsewhere on the board

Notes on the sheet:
MCU VDDA
MCU VREF
MCU VBAT
MCU power distribution
Package: 0603mil

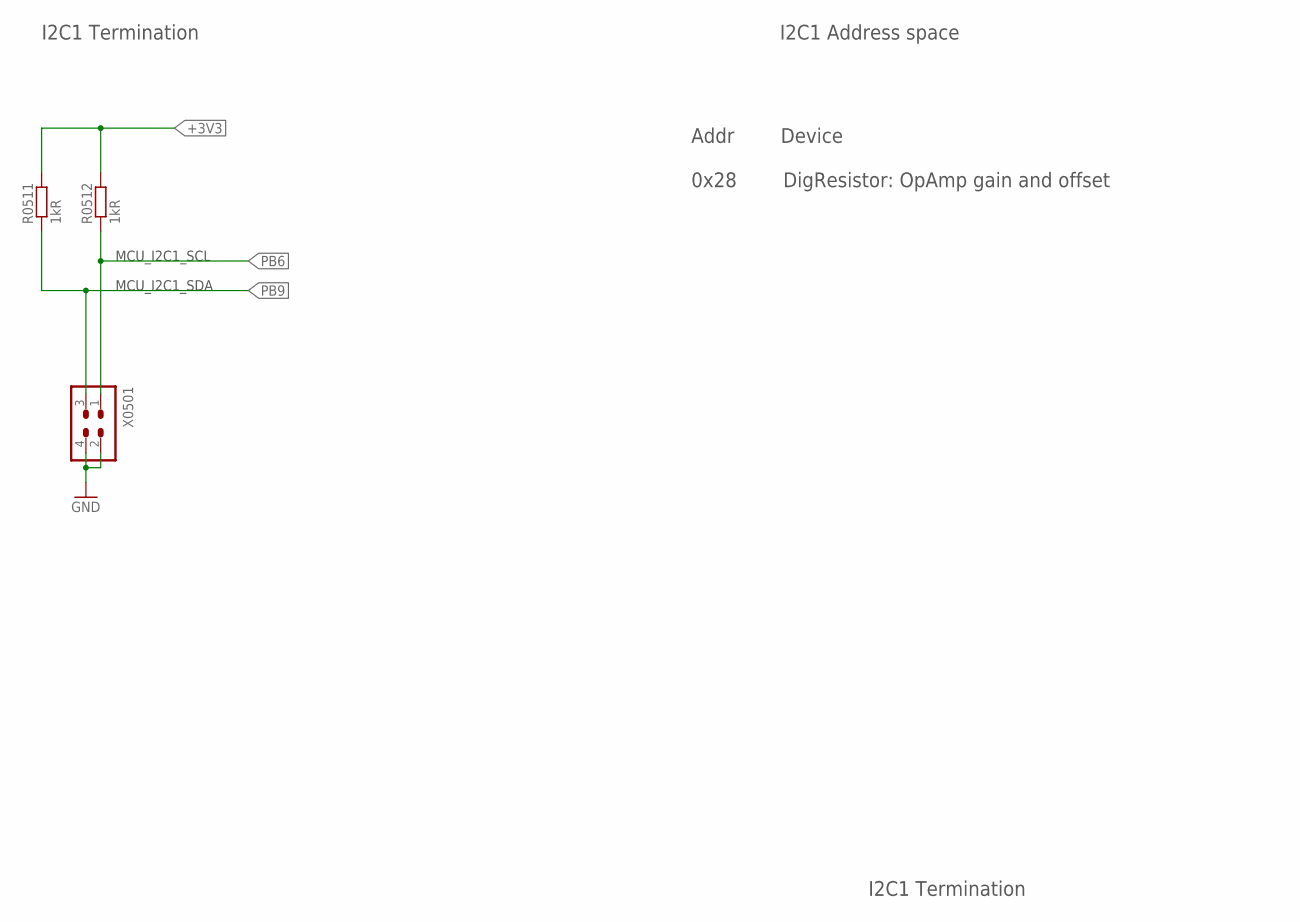
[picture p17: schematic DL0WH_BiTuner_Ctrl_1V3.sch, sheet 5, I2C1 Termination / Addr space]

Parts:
R0511, R0512: 1kR; R0402
X0501: HEADER-2X2; 2X02

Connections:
+3V3: R0511.2, R0512.2; also elsewhere on the board
GND: X0501.2, X0501.4; also elsewhere on the board
PB6: R0512.1, X0501.1; also elsewhere on the board
PB9: R0511.1, X0501.3; also elsewhere on the board

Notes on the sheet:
Addr Device 0x28 DigResistor: OpAmp gain and offset
I2C1 Termination
I2C1 Address space
MCU_I2C1_SCL
MCU_I2C1_SDA

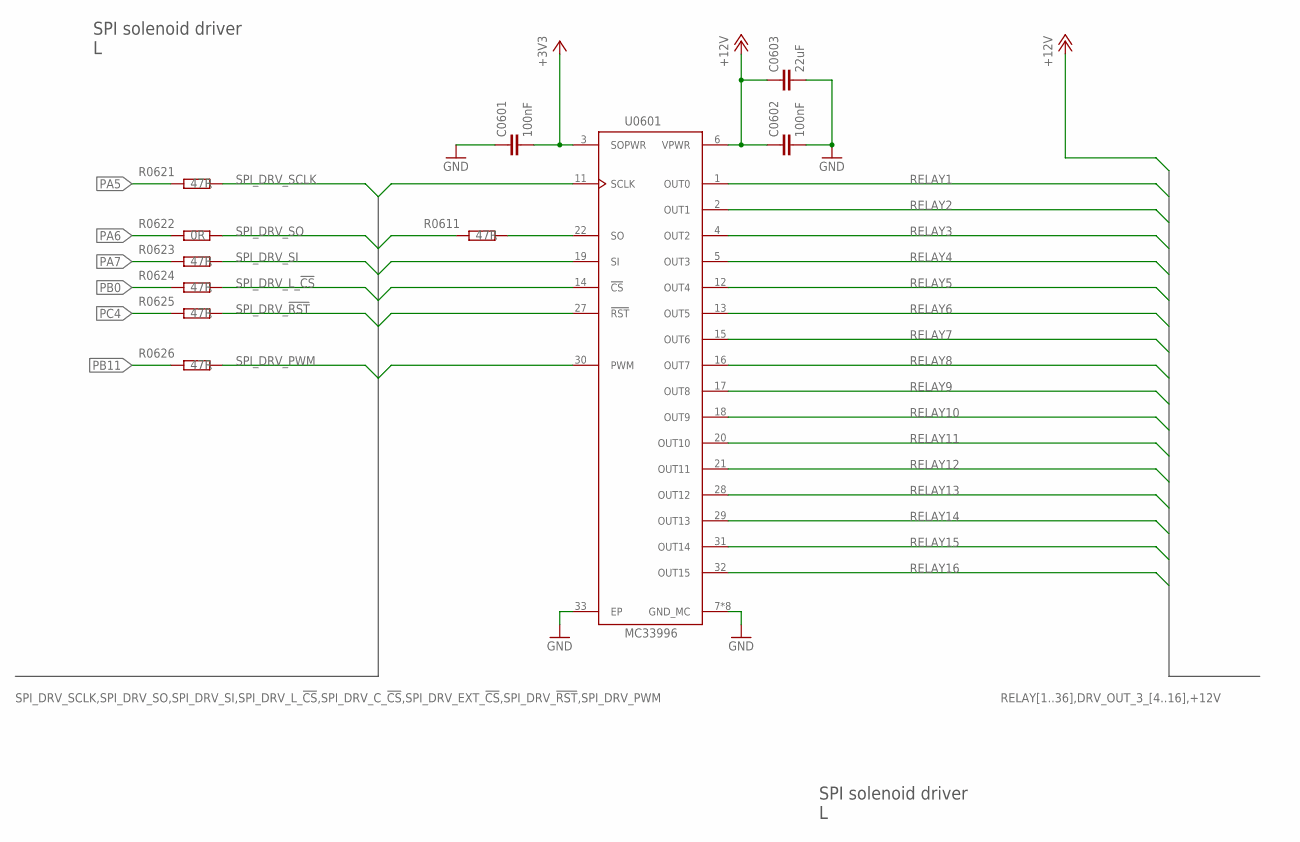
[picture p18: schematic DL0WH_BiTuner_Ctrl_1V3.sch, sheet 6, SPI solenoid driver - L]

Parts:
C0601, C0602: 100nF; C0402
C0603: 22uF; C0603
R0611, R0621, R0623, R0624, R0625, R0626: 47R; R0402
R0622: 0R; R0402
U0601: MC33996; SOICW32

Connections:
+3V3: C0601.2, U0601.3 (SOPWR); also elsewhere on the board
+12V: C0602.1, C0603.1, U0601.6 (VPWR); also elsewhere on the board
GND: C0601.1, C0602.2, C0603.2, U0601.7 (GND_MC), U0601.8 (GND_MC), U0601.9 (GND_MC), U0601.10 (GND_MC), U0601.23 (GND_MC), U0601.24 (GND_MC), U0601.25 (GND_MC), U0601.26 (GND_MC), U0601.33 (EP); also elsewhere on the board
unnamed: R0611.2, U0601.22 (SO)
PA5: R0621.1; also elsewhere on the board
PA6: R0622.1; also elsewhere on the board
PA7: R0623.1; also elsewhere on the board
PB0: R0624.1; also elsewhere on the board
PB11: R0626.1; also elsewhere on the board
PC4: R0625.1; also elsewhere on the board
RELAY1: U0601.1 (OUT0); also elsewhere on the board
RELAY2: U0601.2 (OUT1); also elsewhere on the board
RELAY3: U0601.4 (OUT2); also elsewhere on the board
RELAY4: U0601.5 (OUT3); also elsewhere on the board
RELAY5: U0601.12 (OUT4); also elsewhere on the board
RELAY6: U0601.13 (OUT5); also elsewhere on the board
RELAY7: U0601.15 (OUT6); also elsewhere on the board
RELAY8: U0601.16 (OUT7); also elsewhere on the board
RELAY9: U0601.17 (OUT8); also elsewhere on the board
RELAY10: U0601.18 (OUT9); also elsewhere on the board
RELAY11: U0601.20 (OUT10); also elsewhere on the board
RELAY12: U0601.21 (OUT11); also elsewhere on the board
RELAY13: U0601.28 (OUT12); also elsewhere on the board
RELAY14: U0601.29 (OUT13); also elsewhere on the board
RELAY15: U0601.31 (OUT14); also elsewhere on the board
RELAY16: U0601.32 (OUT15); also elsewhere on the board
SPI_DRV_!RST: R0625.2, U0601.27 (!RST); also elsewhere on the board
SPI_DRV_L_!CS: R0624.2, U0601.14 (!CS)
SPI_DRV_PWM: R0626.2, U0601.30 (PWM); also elsewhere on the board
SPI_DRV_SCLK: R0621.2, U0601.11 (SCLK); also elsewhere on the board
SPI_DRV_SI: R0623.2, U0601.19 (SI); also elsewhere on the board
SPI_DRV_SO: R0611.1, R0622.2; also elsewhere on the board

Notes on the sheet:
SPI solenoid driver L

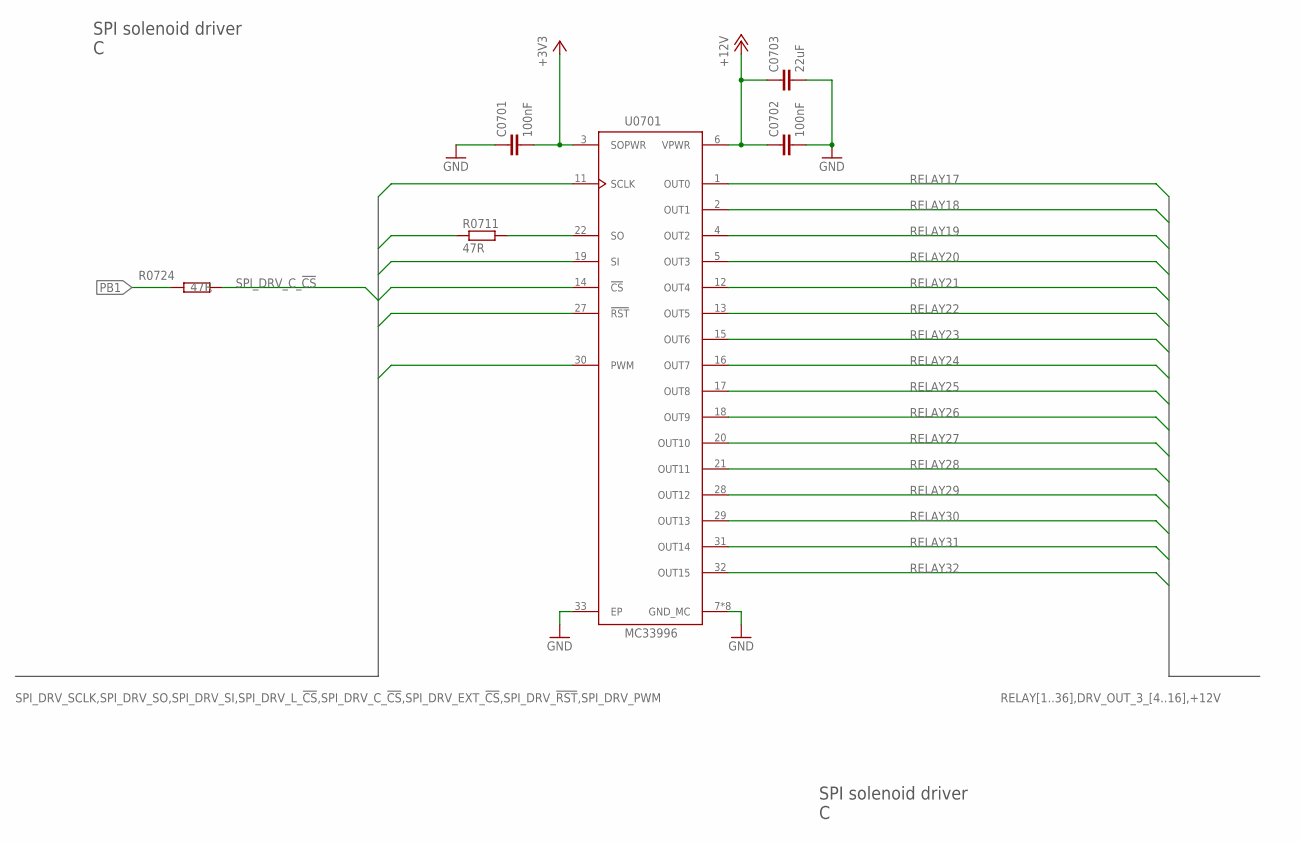
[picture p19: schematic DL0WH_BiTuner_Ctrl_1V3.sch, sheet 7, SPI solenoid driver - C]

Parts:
C0701, C0702: 100nF; C0402
C0703: 22uF; C0603
R0711, R0724: 47R; R0402
U0701: MC33996; SOICW32

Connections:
+3V3: C0701.2, U0701.3 (SOPWR); also elsewhere on the board
+12V: C0702.1, C0703.1, U0701.6 (VPWR); also elsewhere on the board
GND: C0701.1, C0702.2, C0703.2, U0701.7 (GND_MC), U0701.8 (GND_MC), U0701.9 (GND_MC), U0701.10 (GND_MC), U0701.23 (GND_MC), U0701.24 (GND_MC), U0701.25 (GND_MC), U0701.26 (GND_MC), U0701.33 (EP); also elsewhere on the board
unnamed: R0711.2, U0701.22 (SO)
PB1: R0724.1; also elsewhere on the board
RELAY17: U0701.1 (OUT0); also elsewhere on the board
RELAY18: U0701.2 (OUT1); also elsewhere on the board
RELAY19: U0701.4 (OUT2); also elsewhere on the board
RELAY20: U0701.5 (OUT3); also elsewhere on the board
RELAY21: U0701.12 (OUT4); also elsewhere on the board
RELAY22: U0701.13 (OUT5); also elsewhere on the board
RELAY23: U0701.15 (OUT6); also elsewhere on the board
RELAY24: U0701.16 (OUT7); also elsewhere on the board
RELAY25: U0701.17 (OUT8); also elsewhere on the board
RELAY26: U0701.18 (OUT9); also elsewhere on the board
RELAY27: U0701.20 (OUT10); also elsewhere on the board
RELAY28: U0701.21 (OUT11); also elsewhere on the board
RELAY29: U0701.28 (OUT12); also elsewhere on the board
RELAY30: U0701.29 (OUT13); also elsewhere on the board
RELAY31: U0701.31 (OUT14); also elsewhere on the board
RELAY32: U0701.32 (OUT15); also elsewhere on the board
SPI_DRV_!RST: U0701.27 (!RST); also elsewhere on the board
SPI_DRV_C_!CS: R0724.2, U0701.14 (!CS)
SPI_DRV_PWM: U0701.30 (PWM); also elsewhere on the board
SPI_DRV_SCLK: U0701.11 (SCLK); also elsewhere on the board
SPI_DRV_SI: U0701.19 (SI); also elsewhere on the board
SPI_DRV_SO: R0711.1; also elsewhere on the board

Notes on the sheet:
SPI solenoid driver C

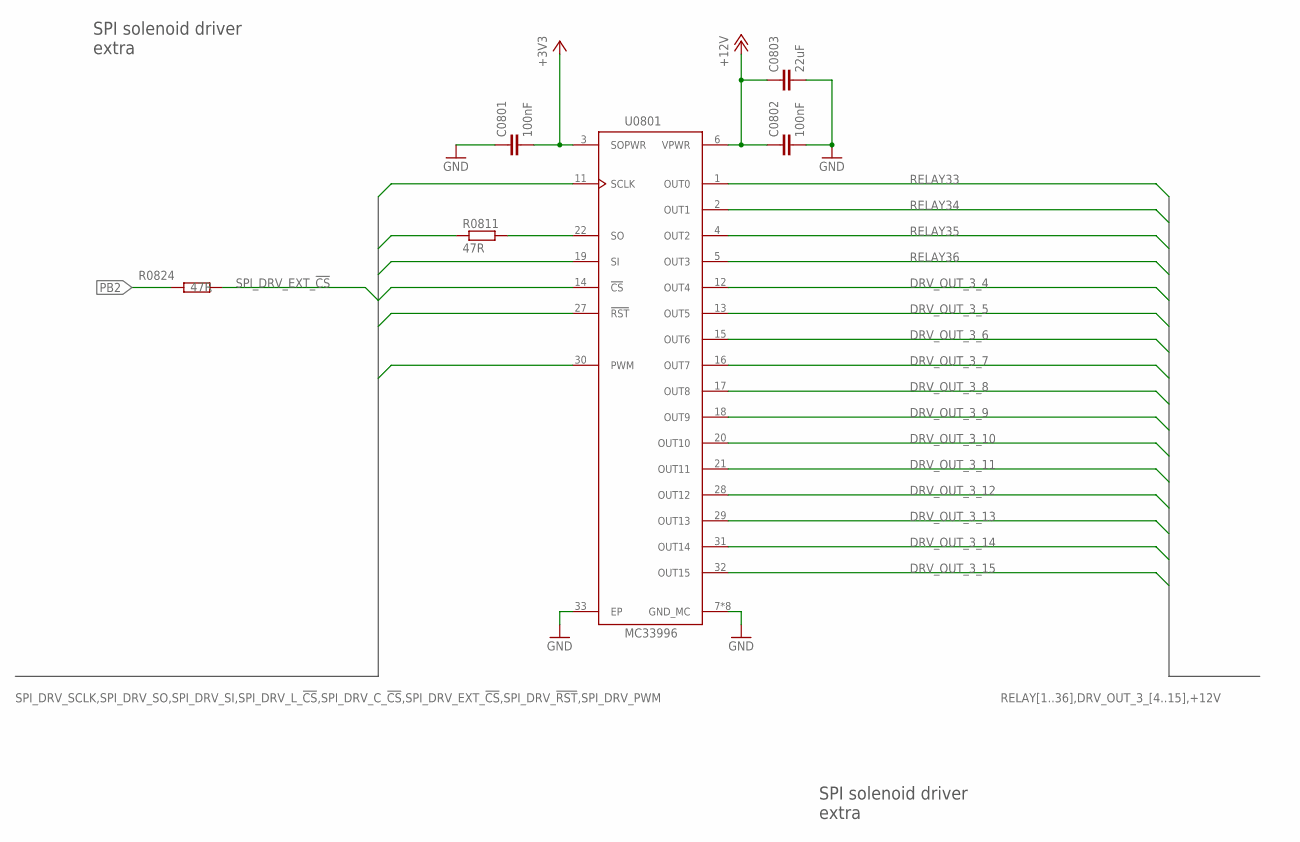
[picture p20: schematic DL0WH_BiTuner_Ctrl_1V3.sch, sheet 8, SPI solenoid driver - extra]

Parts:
C0801, C0802: 100nF; C0402
C0803: 22uF; C0603
R0811, R0824: 47R; R0402
U0801: MC33996; SOICW32

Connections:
+3V3: C0801.2, U0801.3 (SOPWR); also elsewhere on the board
+12V: C0802.1, C0803.1, U0801.6 (VPWR); also elsewhere on the board
DRV_OUT_3_4: U0801.12 (OUT4)
DRV_OUT_3_5: U0801.13 (OUT5)
DRV_OUT_3_6: U0801.15 (OUT6)
DRV_OUT_3_7: U0801.16 (OUT7)
DRV_OUT_3_8: U0801.17 (OUT8)
DRV_OUT_3_9: U0801.18 (OUT9)
DRV_OUT_3_10: U0801.20 (OUT10)
DRV_OUT_3_11: U0801.21 (OUT11)
DRV_OUT_3_12: U0801.28 (OUT12)
DRV_OUT_3_13: U0801.29 (OUT13)
DRV_OUT_3_14: U0801.31 (OUT14)
DRV_OUT_3_15: U0801.32 (OUT15)
GND: C0801.1, C0802.2, C0803.2, U0801.7 (GND_MC), U0801.8 (GND_MC), U0801.9 (GND_MC), U0801.10 (GND_MC), U0801.23 (GND_MC), U0801.24 (GND_MC), U0801.25 (GND_MC), U0801.26 (GND_MC), U0801.33 (EP); also elsewhere on the board
unnamed: R0811.2, U0801.22 (SO)
PB2: R0824.1; also elsewhere on the board
RELAY33: U0801.1 (OUT0); also elsewhere on the board
RELAY34: U0801.2 (OUT1); also elsewhere on the board
RELAY35: U0801.4 (OUT2); also elsewhere on the board
RELAY36: U0801.5 (OUT3); also elsewhere on the board
SPI_DRV_!RST: U0801.27 (!RST); also elsewhere on the board
SPI_DRV_EXT_!CS: R0824.2, U0801.14 (!CS)
SPI_DRV_PWM: U0801.30 (PWM); also elsewhere on the board
SPI_DRV_SCLK: U0801.11 (SCLK); also elsewhere on the board
SPI_DRV_SI: U0801.19 (SI); also elsewhere on the board
SPI_DRV_SO: R0811.1; also elsewhere on the board

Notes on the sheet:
SPI solenoid driver extra

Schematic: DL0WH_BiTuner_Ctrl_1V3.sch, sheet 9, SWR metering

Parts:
C0901, C0911, C0945: 1nF; C0402
C0921, C0951, C0952, C0962: 100nF; C0402
C0941, C0943: 22uF; C0603
C0942: 2.2uF; C0603
C0963: 100pF; C0402
D0942: CRS08; SOD80C
D0951, D0971: CMAD6001; SOD923
L0901, L0911: 10uH; L0603
L0941, L0943: 20uH; L1812
R0901, R0911: 2kR; R0402
R0902, R0912, R0961, R0962, R0972: 1kR; R0402
R0903, R0913: 15kR; R0402
R0904, R0914: 150kR; R0402
R0921, R0922: 47R; R0402
R0923: 2MR; R0402
R0945: 8.2kR; R0402
R0946: 33kR; R0402
R0963: 20kR; R0402
R0971: 10kR; R0402
U0921: TS5A23166; R-PDSO-G8
U0941: LM2611; SOT95P280X145-5N
U0951, U0961: OPA354; SOT-23-5
U0962: MCP4661-103E-MS; TSSOP14

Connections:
+3V3: C0921.1, C0941.1, C0951.1, C0962.1, L0941.2, R0904.2, R0914.2, R0971.1, U0921.8, U0941.4 (!SHDN), U0941.5 (VIN), U0951.5 (V+), U0961.5 (V+), U0962.8 (P0A), U0962.11 (!WP), U0962.14 (VDD); also elsewhere on the board
-1V5: C0943.1, C0945.2, C0952.1, L0943.1, R0945.2, U0951.2 (V-), U0961.2 (V-)
GND: C0901.2, C0911.2, C0921.2, C0941.2, C0943.2, C0951.2, C0952.2, C0962.2, D0942.C, D0971.C, R0902.1, R0912.1, R0923.1, R0946.1, U0921.4, U0941.2 (GND), U0951.3 (+IN), U0961.3 (+IN), U0962.1 (HVC/A0), U0962.4 (VSS), U0962.12 (A2), U0962.13 (A1); also elsewhere on the board
LM2611_NFB: C0945.1, R0945.1, R0946.2, U0941.3 (NFB)
LM2611_SW: C0942.1, L0941.1, U0941.1 (SW)
LM_DA: C0942.2, D0942.A, L0943.2
OPA_FB: R0963.1, U0962.7 (P1A)
OPA_PULL: R0962.2, U0962.9 (P0W)
PA3: R0922.1; also elsewhere on the board
PB6: U0962.2 (SCL); also elsewhere on the board
PB9: U0962.3 (SDA); also elsewhere on the board
PC0: R0972.2; also elsewhere on the board
PC2: D0971.A, R0971.2; also elsewhere on the board
PC3: R0921.1; also elsewhere on the board
RM_FWD: L0901.2; also elsewhere on the board
RM_REV: L0911.2; also elsewhere on the board
SWR_IN_FWD: R0903.2, R0904.1, U0921.1
SWR_IN_FWD_HI: C0901.1, L0901.1, R0901.1
SWR_IN_FWD_LO: R0901.2, R0902.2, R0903.1
SWR_IN_REV: R0913.2, R0914.1, U0921.5
SWR_IN_REV_HI: C0911.1, L0911.1, R0911.1
SWR_IN_REV_LO: R0911.2, R0912.2, R0913.1
SWR_OP1_OUT: D0951.C, R0961.1, U0951.1 (OUT)
SWR_OP2_IN: C0963.1, R0961.2, R0962.1, U0961.4 (-IN), U0962.6 (P1W)
SWR_OP2_OUT: C0963.2, R0963.2, R0972.1, U0961.1 (OUT)
SWR_SEL_FWD: R0921.2, U0921.7
SWR_SEL_PWR: D0951.A, R0923.2, U0921.2, U0921.6, U0951.4 (-IN)
SWR_SEL_REV: R0922.2, U0921.3

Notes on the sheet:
SWR metering
SWR_ADC
FWD / REV switch
Logarithmic Amp I2C1 addr: 0x28
SWR_TEMP
PMIC -1.5V Cuk
Reference diode
MCU_I2C1_SCL
MCU_I2C1_SDA
nom: 5.0kR
nom: 4.9kR

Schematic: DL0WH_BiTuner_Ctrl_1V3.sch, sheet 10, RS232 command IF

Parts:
C1001, C1002, C1003, C1004, C1005: 1uF; C0402
C1051, C1052, C1053, C1054: 10nF; C0402
R1001, R1002, R1003, R1004: 47R; R0402
U1001: MAX232_SOIC16; SOIC16N
X1051, X1052, X1053: WIRE-TO-BOARD_5MM08_1X02

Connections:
+5V: C1001.1, U1001.16 (VCC); also elsewhere on the board
GND: C1001.2, C1004.2, C1005.2, C1051.2, C1052.2, C1053.2, C1054.2, U1001.15 (GND), X1052.1, X1052.2; also elsewhere on the board
MP_RS_CTS_R: R1003.2, U1001.10 (T2IN)
MP_RS_RTR_R: R1004.2, U1001.9 (R2OUT)
MP_RS_RXD_R: R1001.2, U1001.11 (T1IN)
MP_RS_TXD_R: R1002.2, U1001.12 (R1OUT)
PB10: R1002.1; also elsewhere on the board
PB12: R1003.1; also elsewhere on the board
PB13: R1004.1; also elsewhere on the board
PC1: R1001.1; also elsewhere on the board
RS_DTE_CTS: C1053.1, U1001.7 (T2OUT), X1053.1
RS_DTE_RTR: C1054.1, U1001.8 (R2IN), X1053.2
RS_DTE_RXD: C1051.1, U1001.14 (T1OUT), X1051.1
RS_DTE_TXD: C1052.1, U1001.13 (R1IN), X1051.2
RS_MX_C1N1: C1002.2, U1001.3 (C1-)
RS_MX_C1P: C1002.1, U1001.1 (C1+)
RS_MX_C2M1: C1003.2, U1001.5 (C2-)
RS_MX_C2P: C1003.1, U1001.4 (C2+)
RS_MX_VM: C1005.1, U1001.6 (V-)
RS_MX_VP: C1004.1, U1001.2 (V+)

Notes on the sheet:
RS232 command interface (V24)
RS232 command IF
RS232 TXD
RS232 CTS
RS232 GND
RS232 RXD
RS232 RTR
Use LF filters at BiTuner box connector !
---- 100 uH ---- | | 10nF 100nF | | GND GND

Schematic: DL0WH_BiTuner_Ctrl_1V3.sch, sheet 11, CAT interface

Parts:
C1101, C1102, C1103, C1104, C1105: 1uF; C0402
C1151, C1152, C1153, C1154: 10nF; C0402
R1101, R1102, R1103, R1104: 47R; R0402
U1101: MAX232_SOIC16; SOIC16N
X1151, X1152, X1153: WIRE-TO-BOARD_5MM08_1X02

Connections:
+5V: C1101.1, U1101.16 (VCC); also elsewhere on the board
CAT_DTE_CTS: C1153.1, U1101.7 (T2OUT), X1153.1
CAT_DTE_RTR: C1154.1, U1101.8 (R2IN), X1153.2
CAT_DTE_RXD: C1151.1, U1101.14 (T1OUT), X1151.1
CAT_DTE_TXD: C1152.1, U1101.13 (R1IN), X1151.2
CAT_MX_C1N: C1102.2, U1101.3 (C1-)
CAT_MX_C1P: C1102.1, U1101.1 (C1+)
CAT_MX_C2M: C1103.2, U1101.5 (C2-)
CAT_MX_C2P: C1103.1, U1101.4 (C2+)
CAT_MX_VM: C1105.1, U1101.6 (V-)
CAT_MX_VP: C1104.1, U1101.2 (V+)
GND: C1101.2, C1104.2, C1105.2, C1151.2, C1152.2, C1153.2, C1154.2, U1101.15 (GND), X1152.1, X1152.2; also elsewhere on the board
MP_CAT_CTS_R: R1103.2, U1101.10 (T2IN)
MP_CAT_RTR_R: R1104.2, U1101.9 (R2OUT)
MP_CAT_RXD_R: R1101.2, U1101.11 (T1IN)
MP_CAT_TXD_R: R1102.2, U1101.12 (R1OUT)
PA0: R1101.1; also elsewhere on the board
PA1: R1102.1; also elsewhere on the board
PA15: R1103.1; also elsewhere on the board
PB7: R1104.1; also elsewhere on the board

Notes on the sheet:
CAT interface (V24)
CAT interface
CAT TXD
CAT CTS
CAT GND
CAT RXD
CAT RTR
Use LF filters at BiTuner box connector !
---- 100 uH ---- | | 10nF 100nF | | GND GND

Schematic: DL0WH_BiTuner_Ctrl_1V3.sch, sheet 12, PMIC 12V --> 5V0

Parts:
C1201, C1202, C1203: 10uF; C0603
C1204: 10nF; C0402
C1205: 3.3uF; C0603
C1211: 0.47uF; C0402
C1212: 100nF; C0402
C1221, C1222, C1223: 22uF; C0603
D1221: CRS08; SOD80C
L1211: 2.2uH; L_6.00MM_X_6.00MM
R1211: 3R; R0402
U1201: LM53603-Q1; HTSSOP16
X1211: WIRE-TO-BOARD_5MM08_1X02

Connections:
+5V: C1221.1, C1222.1, C1223.1, D1221.C, L1211.1, R1211.2, U1201.9 (FB); also elsewhere on the board
+12V: C1201.1, C1202.1, C1203.1, C1204.1, U1201.11 (EN), U1201.12 (VIN), U1201.13 (VIN), X1211.1; also elsewhere on the board
GND: C1201.2, C1202.2, C1203.2, C1204.2, C1205.1, C1212.2, C1221.2, C1222.2, C1223.2, U1201.6 (SYNC), U1201.7 (FPWM), U1201.10 (AGND), U1201.15 (PGND), U1201.16 (PGND), U1201.PAD (EP), U1201.PAD1 (EP), U1201.PAD2 (EP), U1201.PAD3 (EP), U1201.PAD4 (EP), U1201.PAD5 (EP), U1201.PAD6 (EP), U1201.PAD7 (EP), U1201.PAD8 (EP), U1201.PAD9 (EP), U1201.PAD10 (EP), U1201.PAD11 (EP), U1201.PAD12 (EP), U1201.PAD13 (EP), X1211.2; also elsewhere on the board
LM53603_!RESET: U1201.8 (!RESET)
LM53603_BIAS: C1212.1, R1211.1, U1201.5 (BIAS)
LM53603_CBOOT: C1211.2, U1201.3 (CBOOT)
LM53603_SW: C1211.1, L1211.2, U1201.1 (SW), U1201.2 (SW)
LM53603_VCC: C1205.2, U1201.4 (VCC)
VDDUSB: D1221.A; also elsewhere on the board

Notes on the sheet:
PMIC 12V --> 5V0
12V Down-Converter
Iq=24uA
Abracon ASPI-6045S-2R2N-T 6.0mm x 6.0mm

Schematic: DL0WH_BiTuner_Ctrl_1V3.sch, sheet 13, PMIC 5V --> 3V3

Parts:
C1301, C1311: 22uF; C0603
L1311: 10uH; L_4.50MM_X_3.20MM
R1301: 100kR; R0402
R1302: 220kR; R0402
R1321, R1322: 1MR; R0402
U1301: TPS62056; S-PDSO-G10

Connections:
+3V3: C1311.1, L1311.1, L1311.3 (1), R1321.2, R1322.2, U1301.5 (FB); also elsewhere on the board
+5V: C1301.1, R1302.2, U1301.1 (VIN), U1301.8 (EN); also elsewhere on the board
GND: C1301.2, C1311.2, R1301.1, U1301.3 (VSS), U1301.7 (SYNC), U1301.10 (PGND); also elsewhere on the board
TPS_LBI: R1301.2, R1302.1, U1301.6 (LBI)
TPS_LBO: R1322.1, U1301.2 (LBO)
TPS_PG: R1321.1, U1301.4 (PG)
TPS_SW: L1311.2, L1311.4 (2), U1301.9 (SW)

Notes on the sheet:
PMIC 5V --> 3V3
TPS_PG
TPS_LBO
MURATA LQH43PN100M26L 4.5mm x 3.2mm (1812)

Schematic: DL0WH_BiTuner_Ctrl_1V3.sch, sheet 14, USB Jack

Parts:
C1403: 1nF; C0402
PF1411: 1.1A/2.2A; M1206
R1402: 330kR; R0402
X1401: MOLEX 105017-0001; USB-B-MICRO-SMD_MOLEX-105017-0001

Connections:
GND: C1403.1, R1402.1, X1401.GND; also elsewhere on the board
PA9: PF1411.1, X1401.VBUS (J_VUSB); also elsewhere on the board
PA10: X1401.ID (J_ID); also elsewhere on the board
PA11: X1401.D- (J_D-); also elsewhere on the board
PA12: X1401.D+ (J_D+); also elsewhere on the board
USB_SHIELD: C1403.2, R1402.2, X1401.JSHIELD (SHIELD), X1401.JSHIELD@2 (SHIELD), X1401.JSHIELD@3 (SHIELD), X1401.JSHIELD@4 (SHIELD), X1401.JSHIELD@5 (SHIELD), X1401.JSHIELD@6 (SHIELD)
VDDUSB: PF1411.2; also elsewhere on the board

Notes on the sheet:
Impedance 90 Ohms
USB device and USB host (OTG) interface
MCU_USB_OTG_FS_DM
MCU_USB_OTG_FS_DP
MCU_USB_OTG_FS_ID
MCU_USB_OTG_FS_VBUS
LITTLEFUSE 1206L050YR

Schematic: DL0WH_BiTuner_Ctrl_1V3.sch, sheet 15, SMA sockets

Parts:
X1501: SMA_SMT_AMPHENOL-901-143; SMA_SMT_AMPHENOL_901-143
X1511: SAMTEC SMA-J-P-H-RA-TH1; SMA_SMT_AMPHENOL_901-143

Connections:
GND: X1501.2, X1501.3 (2), X1501.4 (2), X1501.5 (2), X1511.2, X1511.3 (2), X1511.4 (2), X1511.5 (2); also elsewhere on the board
RM_FWD: X1501.1; also elsewhere on the board
RM_REV: X1511.1; also elsewhere on the board

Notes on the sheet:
SMA direct. coupler FWD
SMA direct. coupler REV

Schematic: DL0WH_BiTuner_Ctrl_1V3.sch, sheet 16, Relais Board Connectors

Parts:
X1601, X1602: 2X10_2MM56_SOCKET; 2X10

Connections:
+12V: X1602.17, X1602.18, X1602.19, X1602.20; also elsewhere on the board
RELAY1: X1601.1; also elsewhere on the board
RELAY2: X1601.2; also elsewhere on the board
RELAY3: X1601.3; also elsewhere on the board
RELAY4: X1601.4; also elsewhere on the board
RELAY5: X1601.5; also elsewhere on the board
RELAY6: X1601.6; also elsewhere on the board
RELAY7: X1601.7; also elsewhere on the board
RELAY8: X1601.8; also elsewhere on the board
RELAY9: X1601.9; also elsewhere on the board
RELAY10: X1601.10; also elsewhere on the board
RELAY11: X1601.11; also elsewhere on the board
RELAY12: X1601.12; also elsewhere on the board
RELAY13: X1601.13; also elsewhere on the board
RELAY14: X1601.14; also elsewhere on the board
RELAY15: X1601.15; also elsewhere on the board
RELAY16: X1601.16; also elsewhere on the board
RELAY17: X1601.17; also elsewhere on the board
RELAY18: X1601.18; also elsewhere on the board
RELAY19: X1601.19; also elsewhere on the board
RELAY20: X1601.20; also elsewhere on the board
RELAY21: X1602.1; also elsewhere on the board
RELAY22: X1602.2; also elsewhere on the board
RELAY23: X1602.3; also elsewhere on the board
RELAY24: X1602.4; also elsewhere on the board
RELAY25: X1602.5; also elsewhere on the board
RELAY26: X1602.6; also elsewhere on the board
RELAY27: X1602.7; also elsewhere on the board
RELAY28: X1602.8; also elsewhere on the board
RELAY29: X1602.9; also elsewhere on the board
RELAY30: X1602.10; also elsewhere on the board
RELAY31: X1602.11; also elsewhere on the board
RELAY32: X1602.12; also elsewhere on the board
RELAY33: X1602.13; also elsewhere on the board
RELAY34: X1602.14; also elsewhere on the board
RELAY35: X1602.15; also elsewhere on the board
RELAY36: X1602.16; also elsewhere on the board

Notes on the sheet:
Relay Connectors

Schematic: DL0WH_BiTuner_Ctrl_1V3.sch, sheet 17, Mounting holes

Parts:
H1711, H1721, H1731, H1751, H1761: MOUNT-PAD-ROUND3.0; 3,0-PAD

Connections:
GND: H1711.B3,0, H1721.B3,0, H1731.B3,0, H1751.B3,0, H1761.B3,0; also elsewhere on the board

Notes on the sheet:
Mounting holes

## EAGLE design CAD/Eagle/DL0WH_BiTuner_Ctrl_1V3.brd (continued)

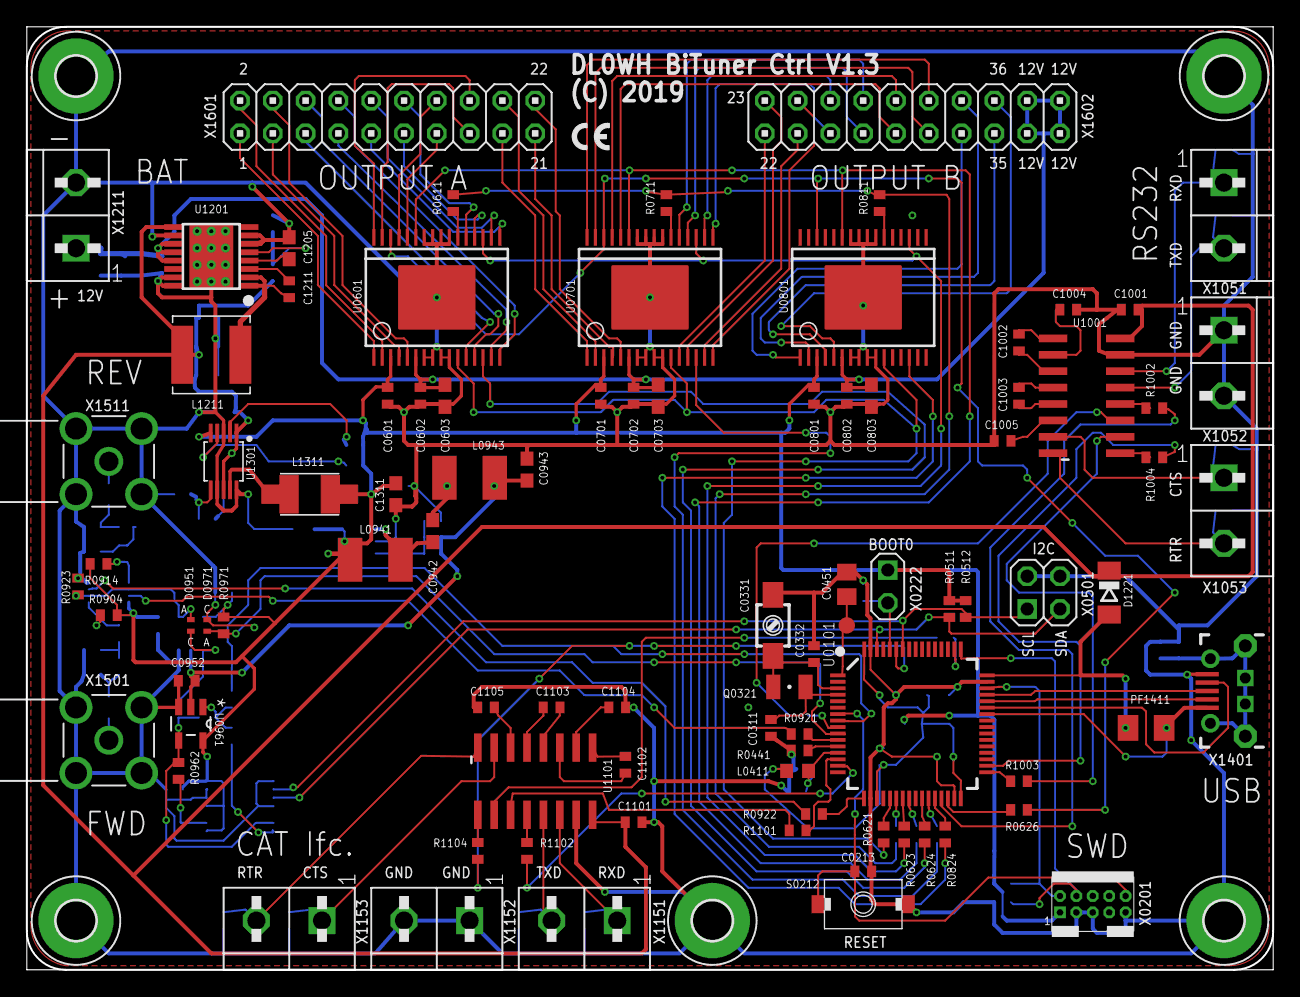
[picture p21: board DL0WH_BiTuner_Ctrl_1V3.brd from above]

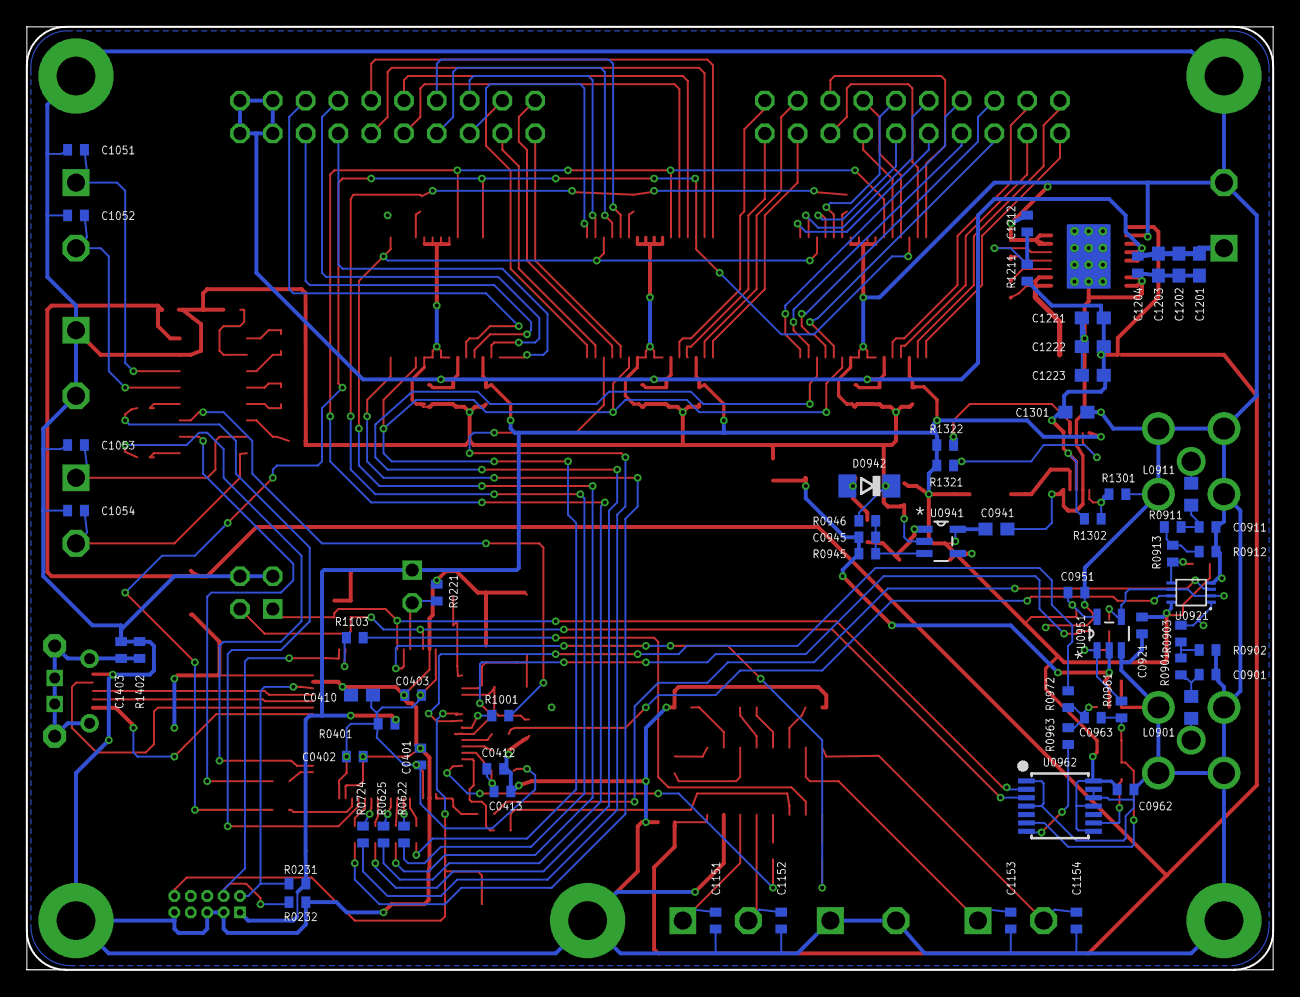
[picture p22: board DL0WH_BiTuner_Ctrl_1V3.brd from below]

Board: 2 copper layers, 96.5 x 73.0 mm, 160 parts (65 on the bottom side), 145 nets.

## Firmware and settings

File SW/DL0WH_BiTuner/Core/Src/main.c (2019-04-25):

/**
  ******************************************************************************
  * @file           : main.c
  * @brief          : Main program body
  ******************************************************************************
  * This notice applies to any and all portions of this file
  * that are not between comment pairs USER CODE BEGIN and
  * USER CODE END. Other portions of this file, whether 
  * inserted by the user or by software development tools
  * are owned by their respective copyright owners.
  *
  * Copyright (c) 2019 STMicroelectronics International N.V. 
  * All rights reserved.
  *
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
  ******************************************************************************
  */
/* Includes ------------------------------------------------------------------*/
#include "main.h"
#include "stm32l4xx_hal.h"
#include "cmsis_os.h"
#include "adc.h"
#include "dma.h"
#include "i2c.h"
#include "usart.h"
#include "rtc.h"
#include "spi.h"
#include "tim.h"
#include "usb_device.h"
#include "gpio.h"

/* USER CODE BEGIN Includes */
#include "FreeRTOS.h"

#include <stddef.h>
#include <stdio.h>
#include <ctype.h>
#include <math.h>

#include "device_adc.h"
#include "bus_i2c.h"
#include "bus_spi.h"
#include "task_Controller.h"
#include "task_Interpreter.h"
#include "task_USB.h"


#define  PERIOD_VALUE       (uint32_t)(16000UL - 1)                                             /* Period Value = 1ms */

/* USER CODE END Includes */


/* USER CODE BEGIN PV */
extern EventGroupHandle_t             adcEventGroupHandle;
extern EventGroupHandle_t             extiEventGroupHandle;
extern EventGroupHandle_t             globalEventGroupHandle;
extern EventGroupHandle_t             spiEventGroupHandle;
extern EventGroupHandle_t             usbToHostEventGroupHandle;

extern TIM_HandleTypeDef              htim2;
extern __IO uint32_t                  uwTick;

extern uint8_t                        i2c1TxBuffer[I2C_TXBUFSIZE];
extern uint8_t                        i2c1RxBuffer[I2C_RXBUFSIZE];


ADC1_RUNNING_VAR_t                    g_adc1_running_var      = ADC1__NOT_RUNNING;
float                                 g_adc_refint_val        = 0.0f;
float                                 g_adc_vref_mv           = 0.0f;
float                                 g_adc_bat_mv            = 0.0f;
float                                 g_adc_temp_deg          = 0.0f;
float                                 g_adc_logamp_ofsMeas_mv = 0.0f;
float                                 g_adc_fwd_raw_mv        = 0.0f;
float                                 g_adc_fwd_mv_log        = 0.0f;
float                                 g_adc_fwd_mv            = 0.0f;
float                                 g_adc_rev_raw_mv        = 0.0f;
float                                 g_adc_rev_mv_log        = 0.0f;
float                                 g_adc_rev_mv            = 0.0f;
float                                 g_adc_vdiode_mv         = 0.0f;
float                                 g_adc_vdiode_temp_deg   = 0.0f;
float                                 g_adc_swr               = 1e+3f;
_Bool                                 g_adc_select_rev        = 0;

SYSCLK_CONFIG_t                       g_main_SYSCLK_CONFIG    = SYSCLK_CONFIG_80MHz_MSI16_PLL;

/* Counter Prescaler value */
uint32_t                              uhPrescalerValue        = 0;

volatile uint32_t                     g_rtc_ssr_last          = 0UL;

static uint64_t                       s_timerLast_us          = 0ULL;
static uint64_t                       s_timerStart_us         = 0ULL;


/* USER CODE END PV */

void SystemClock_Config(void);
void MX_FREERTOS_Init(void);

/* USER CODE BEGIN PFP */

/* USER CODE END PFP */

/* USER CODE BEGIN 0 */
uint32_t crcCalc(const uint32_t* ptr, uint32_t len)
{
#if 0
    return HAL_CRC_Calculate(&hcrc, (uint32_t*) ptr, len);
#else
    const char msg[] = "*** CRC requested but CRC unit is not enabled ***\r\n";
    interpreterConsolePush(msg, strlen(msg), 1);
    return 0UL;
#endif
}


void calcStrToUpper(char* inBuf, uint32_t inBufLen)
{
  char* ptr = inBuf;

  for (uint32_t idx = 0; idx < inBufLen; idx++, ptr++) {
    *ptr = toupper(*ptr);
  }
}

uint8_t sel_u8_from_u32(uint32_t in_u32, uint8_t sel)
{
  return 0xff & (in_u32 >> (sel << 3));
}

void mainCalcFloat2IntFrac(float val, uint8_t fracCnt, int32_t* outInt, uint32_t* outFrac)
{
  const uint8_t isNeg = val >= 0 ?  0U : 1U;

  /* Sanity checks */
  if (!outInt || !outFrac) {
    return;
  }

  /* Integer value */
  *outInt    = (int32_t) val;
  val       -= *outInt;

  /* Fraction part is always positive */
  if (isNeg) {
    val = -val;
  }

  /* Fraction within fraction decade count */
  const float decade = powf(10, fracCnt);
  val       *= decade;
  *outFrac   = (uint32_t) (val + 0.5f);

  /* Check for overflow after rounding */
  uint32_t testFrac = (*outFrac) % (uint32_t)decade;
  if (testFrac != *outFrac) {
    /* Integer part */
    if (isNeg) {
      (*outInt)--;

    } else {
      (*outInt)++;
    }

    /* Overflow to next zero */
    *outFrac = 0UL;
  }
}

float mainCalc_fwdRev_mV(float adc_mv, float vdiode_mv)
{
  return powf(M_E + (0.0f * (vdiode_mv - 500.0f)), adc_mv / 144.0f);
}

float mainCalc_VSWR(float fwd_mv, float rev_mv)
{
  /* Sanity check against reversed voltage */
  if (fwd_mv < 0.0f || rev_mv < 0.0f) {
    return SWR_MAX;
  }

  /* Sanity check against wrong connected channels */
  if (fwd_mv <= rev_mv) {
    return SWR_MAX;
  }

  /* To low energy (25mV) for correct calculation? */
  if (fwd_mv < 25.0f) {
    return SWR_MAX;
  }

  /* VSWR calculation */
  return (float) ((fwd_mv + rev_mv) / (fwd_mv - rev_mv));
}

float mainCalc_mV_to_mW(float mV)
{
  const float in_V = mV / 1000.0f;
  return 1000.0f * ((in_V * in_V) / 50.0f);
}


void mainPowerSwitchDo(POWERSWITCH_ENUM_t sw, uint8_t enable)
{
  __HAL_RCC_GPIOC_CLK_ENABLE();
  __NOP();

  switch (sw) {
  case POWERSWITCH__SLOWER_24MHZ:
    /* SMPS handling */
    if (enable)
    {
      /* Scale2: 1.0V up to 24MHz */
      HAL_PWREx_ControlVoltageScaling(PWR_REGULATOR_VOLTAGE_SCALE2);

    } else {
      /* Scale1: 1.2V up to 80MHz */
      HAL_PWREx_ControlVoltageScaling(PWR_REGULATOR_VOLTAGE_SCALE1);
    }
    break;

  case POWERSWITCH__BAT_SW:
    if (enable) {
      HAL_PWREx_EnableBatteryCharging(PWR_BATTERY_CHARGING_RESISTOR_5);

    } else {
      HAL_PWREx_DisableBatteryCharging();
    }
    break;

  case POWERSWITCH__BAT_HICUR:
    if (enable) {
      HAL_PWREx_EnableBatteryCharging(PWR_BATTERY_CHARGING_RESISTOR_1_5);

    } else {
      HAL_PWREx_EnableBatteryCharging(PWR_BATTERY_CHARGING_RESISTOR_5);
    }
    break;

  default:
    { }
  }

  __HAL_RCC_GPIOC_CLK_DISABLE();
}

void mainPowerSwitchInit(void)
{
  /* Vbat charger of MCU enabled with 1.5 kOhm */
  mainPowerSwitchDo(POWERSWITCH__BAT_HICUR, 1U);

  /* MCU core frequency = 16 MHz */
  mainPowerSwitchDo(POWERSWITCH__SLOWER_24MHZ, 1U);
}


void SystemResetbyARMcore(void)
{
  /* Set SW reset bit */
  SCB->AIRCR = 0x05FA0000UL | SCB_AIRCR_SYSRESETREQ_Msk;
}

/* Used by the run-time stats */
void configureTimerForRunTimeStats(void)
{
  getRunTimeCounterValue();

  /* Interrupt disabled block */
  {
    __disable_irq();

    /* Called only once */
    s_timerStart_us = s_timerLast_us;

    __enable_irq();
  }
}

/* Used by the run-time stats */
unsigned long getRunTimeCounterValue(void)
{
  uint64_t l_timerStart_us = 0ULL;
  uint64_t l_timer_us;

  /* Interrupt disabled block */
  {
    taskDISABLE_INTERRUPTS();

    l_timer_us      = HAL_GetTick();
    l_timerStart_us = s_timerStart_us;

    taskENABLE_INTERRUPTS();
  }

  /* Avoid overflows */
  l_timer_us &= 0x003fffffUL;

  /* Add microseconds */
  l_timer_us *= 1000ULL;
  l_timer_us += TIM2->CNT % 1000UL;                                                                   // TIM2 counts microseconds

  /* Interrupt disabled block */
  {
    taskDISABLE_INTERRUPTS();

    s_timerLast_us  = l_timer_us;

    taskENABLE_INTERRUPTS();
  }

  uint64_t l_timerDiff64 = (l_timer_us >= l_timerStart_us) ?  (l_timer_us - l_timerStart_us) : l_timer_us;
  uint32_t l_timerDiff32 = (uint32_t) (l_timerDiff64 & 0xffffffffULL);
  return l_timerDiff32;
}

/* USER CODE END 0 */

/**
  * @brief  The application entry point.
  *
  * @retval None
  */
int main(void)
{
  /* USER CODE BEGIN 1 */
  /* Check if ARM core is already in reset state */
  if (!(RCC->CSR & 0xff000000UL)) {
    /* Turn off battery charger of Vbat */
    HAL_PWREx_DisableBatteryCharging();

    /* ARM software reset to be done */
    SystemResetbyARMcore();
  }
  __HAL_RCC_CLEAR_RESET_FLAGS();
  /* USER CODE END 1 */

  /* MCU Configuration----------------------------------------------------------*/

  /* Reset of all peripherals, Initializes the Flash interface and the Systick. */
  HAL_Init();

  /* Configure the system clock */
  SystemClock_Config();

  /* Initialize all configured peripherals */
  MX_GPIO_Init();
  MX_DMA_Init();
  MX_ADC1_Init();
  MX_ADC2_Init();
  MX_I2C1_Init();
  MX_LPUART1_UART_Init();
  MX_UART4_Init();
  MX_RTC_Init();
  MX_SPI1_Init();
  MX_TIM5_Init();
  MX_ADC3_Init();
  /* Call init function for freertos objects (in freertos.c) */
  MX_FREERTOS_Init();

  /* Start scheduler */
  osKernelStart();
  
  /* We should never get here as control is now taken by the scheduler */

  /* Infinite loop */
  /* USER CODE BEGIN WHILE */
  while (1)
  {

  /* USER CODE END WHILE */

  /* USER CODE BEGIN 3 */

  }
  /* USER CODE END 3 */

}

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
/* USER CODE BEGIN 4 */

void Again_SystemClock_Config(SYSCLK_CONFIG_t sel)
{
  RCC_OscInitTypeDef RCC_OscInitStruct;
  RCC_ClkInitTypeDef RCC_ClkInitStruct;
  RCC_PeriphCLKInitTypeDef PeriphClkInit;

  /* Configure LSE Drive Capability */
  {
    HAL_PWR_EnableBkUpAccess();

    __HAL_RCC_LSEDRIVE_CONFIG(RCC_LSEDRIVE_MEDIUMLOW);
  }


  if (g_main_SYSCLK_CONFIG != sel) {
    switch (sel) {

    default:
    case SYSCLK_CONFIG_80MHz_MSI16_PLL:
      {
        /* Set global variable */
        g_main_SYSCLK_CONFIG = sel;

        /**Initializes the CPU, AHB and APB busses clocks
        */
        RCC_OscInitStruct.OscillatorType = RCC_OSCILLATORTYPE_HSI|RCC_OSCILLATORTYPE_LSE
                                    |RCC_OSCILLATORTYPE_MSI;
        RCC_OscInitStruct.LSEState = RCC_LSE_ON;
        RCC_OscInitStruct.HSIState = RCC_HSI_ON;
        RCC_OscInitStruct.HSICalibrationValue = 0x10;
        RCC_OscInitStruct.MSIState = RCC_MSI_ON;
        RCC_OscInitStruct.MSICalibrationValue = 0xfe;
        RCC_OscInitStruct.MSIClockRange = RCC_MSIRANGE_11;
        RCC_OscInitStruct.PLL.PLLState = RCC_PLL_ON;
        RCC_OscInitStruct.PLL.PLLSource = RCC_PLLSOURCE_HSI;
        RCC_OscInitStruct.PLL.PLLM = 1;
        RCC_OscInitStruct.PLL.PLLN = 10;
        RCC_OscInitStruct.PLL.PLLP = RCC_PLLP_DIV7;
        RCC_OscInitStruct.PLL.PLLQ = RCC_PLLQ_DIV2;
        RCC_OscInitStruct.PLL.PLLR = RCC_PLLR_DIV2;
        if (HAL_RCC_OscConfig(&RCC_OscInitStruct) != HAL_OK)
        {
          _Error_Handler(__FILE__, __LINE__);
        }

        /**Initializes the CPU, AHB and APB busses clocks
        */
        RCC_ClkInitStruct.ClockType = RCC_CLOCKTYPE_HCLK|RCC_CLOCKTYPE_SYSCLK
                                    |RCC_CLOCKTYPE_PCLK1|RCC_CLOCKTYPE_PCLK2;
        RCC_ClkInitStruct.SYSCLKSource = RCC_SYSCLKSOURCE_PLLCLK;
        RCC_ClkInitStruct.AHBCLKDivider = RCC_SYSCLK_DIV1;
        RCC_ClkInitStruct.APB1CLKDivider = RCC_HCLK_DIV1;
        RCC_ClkInitStruct.APB2CLKDivider = RCC_HCLK_DIV1;

        if (HAL_RCC_ClockConfig(&RCC_ClkInitStruct, FLASH_LATENCY_4) != HAL_OK)
        {
          _Error_Handler(__FILE__, __LINE__);
        }

        PeriphClkInit.PeriphClockSelection = RCC_PERIPHCLK_RTC|RCC_PERIPHCLK_UART4
                                    |RCC_PERIPHCLK_LPUART1|RCC_PERIPHCLK_I2C1
                                    |RCC_PERIPHCLK_USB|RCC_PERIPHCLK_ADC;
        PeriphClkInit.Uart4ClockSelection = RCC_UART4CLKSOURCE_HSI;
        PeriphClkInit.Lpuart1ClockSelection = RCC_LPUART1CLKSOURCE_HSI;
        PeriphClkInit.I2c1ClockSelection = RCC_I2C1CLKSOURCE_HSI;
        PeriphClkInit.AdcClockSelection = RCC_ADCCLKSOURCE_SYSCLK;
        PeriphClkInit.RTCClockSelection = RCC_RTCCLKSOURCE_LSE;
        PeriphClkInit.UsbClockSelection = RCC_USBCLKSOURCE_MSI;
        if (HAL_RCCEx_PeriphCLKConfig(&PeriphClkInit) != HAL_OK)
        {
          _Error_Handler(__FILE__, __LINE__);
        }

        HAL_RCC_MCOConfig(RCC_MCO1, RCC_MCO1SOURCE_LSE, RCC_MCODIV_1);

        /**Configure the main internal regulator output voltage
        */
        if (HAL_PWREx_ControlVoltageScaling(PWR_REGULATOR_VOLTAGE_SCALE1) != HAL_OK)
        {
          _Error_Handler(__FILE__, __LINE__);
        }

        /**Configure the Systick interrupt time
        */
        HAL_SYSTICK_Config(HAL_RCC_GetHCLKFreq()/1000);

        /**Configure the Systick
        */
        HAL_SYSTICK_CLKSourceConfig(SYSTICK_CLKSOURCE_HCLK);

        /**Enable MSI Auto calibration
        */
        HAL_RCCEx_EnableMSIPLLMode();

        //HFT_TIM2_AdjustClock(2U);
      }
      break;
    }  // switch(sel)

    /* SysTick_IRQn interrupt configuration */
    HAL_NVIC_SetPriority(SysTick_IRQn, 15, 0);
  }  // if (g_main_SYSCLK_CONFIG != sel)
}


#if 1
void  vApplicationIdleHook(void)
{
  /* vApplicationIdleHook() will only be called if configUSE_IDLE_HOOK is set
  to 1 in FreeRTOSConfig.h. It will be called on each iteration of the idle
  task. It is essential that code added to this hook function never attempts
  to block in any way (for example, call xQueueReceive() with a block time
  specified, or call vTaskDelay()). If the application makes use of the
  vTaskDelete() API function (as this demo application does) then it is also
  important that vApplicationIdleHook() is permitted to return to its calling
  function, because it is the responsibility of the idle task to clean up
  memory allocated by the kernel to any task that has since been deleted. */
  /* TODO: coding here
   * 1) Reduce 80 MHz  to  2 MHz
   * 2)  go to LPRun  (SMPS 2 High (-->  MR range 1) --> MR range 2 --> LPR
   * 3)  Go to LPSleep
   *
   * WAKEUP
   * 1)  In LPRun go to 80 MHz (LPR --> MR range 2 (--> MR range 1) --> SMPS 2 High)
   * 2)  Increase 2 MHz to 80 MHz
   */

  /* Enter sleep mode */
  __WFI();

  /* Increase clock frequency to 80 MHz */
  // TODO: TBD
}
#endif

void vApplicationMallocFailedHook(void)
{
  configASSERT(0);
}

/* USER CODE END 4 */

/**
  * @brief  Period elapsed callback in non blocking mode
  * @note   This function is called  when TIM2 interrupt took place, inside
  * HAL_TIM_IRQHandler(). It makes a direct call to HAL_IncTick() to increment
  * a global variable "uwTick" used as application time base.
  * @param  htim : TIM handle
  * @retval None
  */
void HAL_TIM_PeriodElapsedCallback(TIM_HandleTypeDef *htim)
{
  if (htim->Instance == TIM2) {
    HAL_IncTick();
  }
}

/**
  * @brief  This function is executed in case of error occurrence.
  * @param  file: The file name as string.
  * @param  line: The line in file as a number.
  * @retval None
  */
void _Error_Handler(char *file, int line)
{
  /* USER CODE BEGIN Error_Handler_Debug */
  /* User can add his own implementation to report the HAL error return state */
  configASSERT(0);
  /* USER CODE END Error_Handler_Debug */
}

#ifdef  USE_FULL_ASSERT
/**
  * @brief  Reports the name of the source file and the source line number
  *         where the assert_param error has occurred.
  * @param  file: pointer to the source file name
  * @param  line: assert_param error line source number
  * @retval None
  */
void assert_failed(uint8_t* file, uint32_t line)
{ 
  /* USER CODE BEGIN 6 */
  /* User can add his own implementation to report the file name and line number,
     printf("Wrong parameters value: file %s on line %d\r\n", file, line) */
  configASSERT(0);
  /* USER CODE END 6 */
}
#endif /* USE_FULL_ASSERT */

/**
  * @}
  */

/**
  * @}
  */

/************************ (C) COPYRIGHT STMicroelectronics *****END OF FILE****/

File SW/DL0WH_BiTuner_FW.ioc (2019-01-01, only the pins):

Mcu.UserName=STM32L476RGTx
PA0.Signal=UART4_TX
PA1.Signal=UART4_RX
PA10.Signal=USB_OTG_FS_ID
PA11.Signal=USB_OTG_FS_DM
PA12.Signal=USB_OTG_FS_DP
PA2.Signal=SYS_WKUP4
PA3.GPIO_Label=GPIO_SWR_SEL_REV
PA3.Signal=GPIO_Output
PA4.Signal=COMP_DAC11_group
PA5.Signal=SPI1_SCK
PA6.Signal=SPI1_MISO
PA7.Signal=SPI1_MOSI
PA8.Signal=USB_OTG_FS_SOF
PA9.Signal=USB_OTG_FS_VBUS
PB0.GPIO_Label=GPIO_SPI_SEL_L
PB0.Signal=GPIO_Output
PB1.GPIO_Label=GPIO_SPI_SEL_C
PB1.Signal=GPIO_Output
PB10.Signal=LPUART1_RX
PB11.GPIO_Label=GPIO_SPI_PWM
PB11.Signal=GPIO_Output
PB12.Signal=LPUART1_RTS
PB13.Signal=LPUART1_CTS
PB2.GPIO_Label=GPIO_SPI_SEL_EXT
PB2.Signal=GPIO_Output
PB6.Signal=I2C1_SCL
PB7.Signal=UART4_CTS
PB9.Signal=I2C1_SDA
PC0.Signal=ADCx_IN1
PC1.Signal=LPUART1_TX
PC13.Signal=RTC_TS
PC2.Signal=ADCx_IN3
PC3.GPIO_Label=GPIO_SWR_SEL_FWD
PC3.Signal=GPIO_Output
PC4.GPIO_Label=GPIO_SPI_RST
PC4.Signal=GPIO_Output
PC5.Signal=COMP1_INP

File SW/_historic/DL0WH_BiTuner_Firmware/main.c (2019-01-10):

#include <atmel_start.h>
#include "Tuner/tuner.h"

extern bool isReady;

/* Source code modified by DF4IAH  2019-01-10 */


int main(void)
{
#ifdef OLD_CODE

	/* Call Tuner */
	tuner_main();

#else

	/* Initializes MCU, drivers and middleware */
	atmel_start_init();

    /* Globally enable interrupts */
    cpu_irq_enable();

	/* RESET all C relays, SET all L relays */
    Grundstellung();
	USART_0_enable();

	isReady = true;
	printWelcome();
	printHelp();
	printState();

	/* Work loop */
	while (1) {
		readSerialCommand();
		switchRelais();
	}

#endif
}

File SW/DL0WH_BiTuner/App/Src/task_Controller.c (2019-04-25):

/*
 * task_Controller.c
 *
 *  Created on: 06.01.2019
 *      Author: DF4IAH
 */


/* Includes ------------------------------------------------------------------*/
#include "task_Controller.h"

#include <stdbool.h>
#include <stdio.h>
#include <string.h>
#include <math.h>

#include "FreeRTOS.h"
#include "cmsis_os.h"
#include "stm32l476xx.h"

//#include "stm32l4xx_hal_gpio.h"
#include "bus_spi.h"
#include "device_adc.h"
#include "task_USB.h"
#include "task_CAT.h"
#include "task_Interpreter.h"


//#define I2C1_BUS_ADDR_SCAN

#ifdef I2C1_BUS_ADDR_SCAN
# include "bus_i2c.h"
extern I2C_HandleTypeDef    hi2c1;
extern osSemaphoreId        i2c1_BSemHandle;
#endif


extern osMessageQId         controllerInQueueHandle;
extern osMessageQId         controllerOutQueueHandle;

extern osTimerId            controllerTimerHandle;

extern osSemaphoreId        usb_BSemHandle;
extern osSemaphoreId        uart_BSemHandle;
extern osSemaphoreId        cat_BSemHandle;

extern osSemaphoreId        cQin_BSemHandle;
extern osSemaphoreId        cQout_BSemHandle;

extern osSemaphoreId        c2default_BSemHandle;
extern osSemaphoreId        c2interpreter_BSemHandle;
extern osSemaphoreId        c2usbToHost_BSemHandle;
extern osSemaphoreId        c2usbFromHost_BSemHandle;
extern osSemaphoreId        c2uartTx_BSemHandle;
extern osSemaphoreId        c2uartRx_BSemHandle;
extern osSemaphoreId        c2catTx_BSemHandle;
extern osSemaphoreId        c2catRx_BSemHandle;

extern EventGroupHandle_t   globalEventGroupHandle;
extern EventGroupHandle_t   adcEventGroupHandle;

extern float                g_adc_refint_val;
extern float                g_adc_vref_mv;
extern float                g_adc_bat_mv;
extern float                g_adc_temp_deg;
extern float                g_adc_logamp_ofsMeas_mv;
extern float                g_adc_fwd_raw_mv;
extern float                g_adc_fwd_mv_log;
extern float                g_adc_fwd_mv;
extern float                g_adc_rev_raw_mv;
extern float                g_adc_rev_mv_log;
extern float                g_adc_rev_mv;
extern float                g_adc_vdiode_mv;
extern float                g_adc_vdiode_temp_deg;
extern float                g_adc_swr;


#define Controller_L0_nH                                      50.0f
const float Controller_Ls_nH[8]                      = {
    187.5f,
    375.0f,
    750.0f,
    1.5e+3f,
    3.0e+3f,
    6.0e+3f,
    12.0e+3f,
    24.0e+3f
};

#define Controller_C0_pF                                      25.0f
const float Controller_Cp_pF[8]                      = {
    25.0f,
    //33.0f,
    50.0f,
    89.0f,
    165.0f,
    340.0f,
    600.0f,
    1137.0f,
    1939.0f
};



static ControllerMsg2Proc_t s_msg_in                          = { 0 };
static ControllerMods_t     s_mod_start                       = { 0 };
static ControllerMods_t     s_mod_rdy                         = { 0 };


static const float          Controller_AutoSWR_P_mW_Min       =  5000.0f  / 1000.0f;  // -30 dB coupling
static const float          Controller_AutoSWR_P_mW_Max       = 15000.0f  / 1000.0f;  // -30 dB coupling
static const float          Controller_AutoSWR_SWR_Init       = SWR_MAX;
static const float          Controller_AutoSWR_SWR_Course_Min = 1.3f;
static const float          Controller_AutoSWR_SWR_Fine_Min   = 1.1f;
static const uint8_t        Controller_AutoSWR_Fine_Ctr_Max   = 100U;
static const float          Controller_AutoSWR_WaitBefore_ms  = 750.0f;
static const uint8_t        Controller_AutoSWR_CVHpong_Max    = 1U;
static const uint8_t        Controller_AutoSWR_LCpong_Max     = 3U;
static const float          Controller_Adc_Ofs_Max_mV         = 10.0f;

static uint32_t             s_controller_swr_tmr              = 0UL;
static uint8_t              s_controller_fine_ctr             = 0U;

static uint8_t              s_controller_RelVal_L_cur         = 0U;
static uint8_t              s_controller_RelVal_C_cur         = 0U;

static Meas_Data_t          s_controller_L_Meas               = { 0 };
static Meas_Data_t          s_controller_C_Meas               = { 0 };

static ControllerFsm_t        s_controller_FSM_state            = ControllerFsm__NOP;
static ControllerOptiCVH_t    s_controller_FSM_optiCVH          = ControllerOptiCVH__CV;
static uint8_t                s_controller_opti_CVHpongCtr      = 0U;
static uint8_t                s_controller_opti_LCpongCtr       = 0U;

static float                  s_controller_best_swr             = 0.0f;
static uint8_t                s_controller_best_swr_L           = 0U;
static uint8_t                s_controller_best_swr_C           = 0U;
static ControllerOptiCVH_t    s_controller_best_swr_CVH         = ControllerOptiCVH__CV;

static float                  s_controller_adc_bat_mv           = 0.0f;
static float                  s_controller_adc_temp_deg         = 0.0f;
static float                  s_controller_adc_fwd_mv_log       = 0.0f;
static float                  s_controller_adc_fwd_mv           = 0.0f;
static float                  s_controller_adc_rev_mv_log       = 0.0f;
static float                  s_controller_adc_rev_mv           = 0.0f;
static float                  s_controller_adc_vdiode_mv        = 0.0f;
static float                  s_controller_adc_vdiode_temp_deg  = 0.0f;
static float                  s_controller_adc_swr              = 0.0f;
static float                  s_controller_adc_swr_previous     = 0.0f;
static float                  s_controller_adc_fwd_mw           = 0.0f;
static float                  s_controller_adc_rev_mw           = 0.0f;

static uint8_t                s_controller_logamp_pot_val       = 0.0f;

static _Bool                  s_controller_doAdc                = 0;
static _Bool                  s_controller_doAutoMatching       = 0;
static ControllerMonitor_BF_t s_controller_verbose_bf           = 0UL;
static uint32_t               s_controller_doCycle              = 0UL;

static DefaultMcuClocking_t   s_controller_McuClocking          = DefaultMcuClocking_80MHz_MSI16_PLL;



/* Controller's welcome */

const char controllerGreetMsg01[] = "\r\n";
const char controllerGreetMsg02[] = "+=======================================================+\r\n";
const char controllerGreetMsg03[] = "*                                                       *\r\n";
const char controllerGreetMsg04[] = "*  DL0WH BiTuner - ARM Cortex M4  powered by STM32L476  *\r\n";

const char controllerGreetMsg11[] =
    "\tDL0WH BiTuner version:\r\n"
    "\t=====================\r\n"
    "\r\n"
    "\t\tFirmware date\t%08lu\r\n"
    "\t\tDeveloped by\tDF4IAH\r\n";
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

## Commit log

2018-12-13 Atmel ICE attached - trying 2MHz programmer clock
2018-12-29 Readout of DJ0ARB ATmega88 for security reasons (FUSES & LockBits)
2018-12-29 No debug mode available - do not use SPI and debugWIRE together!
2018-12-30 HW_1V0 - CAD/Eagle - Copy template from HFT-Core-Module
    [DL0WH_BiTuner_MCU_1V0.brd, DL0WH_BiTuner_MCU_1V0.sch]
2018-12-30 HW_1V0 - CAD/Eagle - STM32L476RGT6 added to df4iah_stm32l4.lbr
2018-12-30 HW_1V0 - CAD/Eagle - Initial setup of new PCB
    [DL0WH_BiTuner_MCU_1V0.brd, DL0WH_BiTuner_MCU_1V0.sch]
2018-12-31 HW_1V0 - CAD/Eagle - I/O drivers added
    [DL0WH_BiTuner_MCU_1V0.brd, DL0WH_BiTuner_MCU_1V0.sch]
2018-12-31 HW_1V0 - CAD/Eagle - level shifter not needed and removed
2018-12-31 HW_1V0 - CAD/Eagle - I2C port expander not needed and removed
    [DL0WH_BiTuner_MCU_1V0.brd, DL0WH_BiTuner_MCU_1V0.sch]
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2019-01-01 HW_1V0 - CAD/Eagle - I2C port added
    [DL0WH_BiTuner_MCU_1V0.brd, DL0WH_BiTuner_MCU_1V0.sch]
2019-01-01 HW_1V0 - CAD/Eagle - SWR metering added, all placed
    [DL0WH_BiTuner_MCU_1V0.brd, DL0WH_BiTuner_MCU_1V0.sch]
2019-01-01 HW_1V0 - CAD/Eagle - some routing done
    [DL0WH_BiTuner_MCU_1V0.brd, DL0WH_BiTuner_MCU_1V0.sch]
2019-01-01 HW_1V0 - CAD/Eagle - prepared BOM and adjusted some package sizes - still L9011 needs correct package
    [DL0WH_BiTuner_MCU_1V0.brd, DL0WH_BiTuner_MCU_1V0.sch]
2019-01-01 HW_1V0 - CAD/Eagle - STM32L476 symbol fixed
    [DL0WH_BiTuner_MCU_1V0.sch]
2019-01-01 HW_1V0 - CAD/Eagle - pages renumbered: 17 pages
    [DL0WH_BiTuner_MCU_1V0.brd, DL0WH_BiTuner_MCU_1V0.sch]
2019-01-02 HW_1V0 - 10uH Murata inductivity added
    [DL0WH_BiTuner_MCU_1V0.brd, DL0WH_BiTuner_MCU_1V0.sch]
2019-01-02 HW_1V0 - text size fixed for 0603 and 0402 devices
    [DL0WH_BiTuner_MCU_1V0.brd, DL0WH_BiTuner_MCU_1V0.sch]
2019-01-02 HW_1V0 - CAD/Eagle - some parts re-routed
    [DL0WH_BiTuner_MCU_1V0.brd]
2019-01-02 HW_1V0 - CAD/Eagle - all placed, next: ERC and DRC
    [DL0WH_BiTuner_MCU_1V0.brd, DL0WH_BiTuner_MCU_1V0.sch]
2019-01-02 HW_1V0 - CAD/Eagle - ERC done
    [DL0WH_BiTuner_MCU_1V0.sch]
2019-01-02 HW_1V0 - CAD/Eagle - missing *.dru file added
2019-01-02 HW_1V0 - CAD/Eagle - some DRC error fixed
    [DL0WH_BiTuner_MCU_1V0.brd, DL0WH_BiTuner_MCU_1V0.sch]
2019-01-03 HW_1V0 - CAD/Eagle - I/O protection on V24 lines added
    [DL0WH_BiTuner_MCU_1V0.brd, DL0WH_BiTuner_MCU_1V0.sch]
2019-01-04 HW_1V0 - CAD/Eagle - Final imporovements done. Ready for production.
    [DL0WH_BiTuner_MCU_1V0.brd, DL0WH_BiTuner_MCU_1V0.sch]
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2019-01-04 HW_1V0 - CAD/Eagle - Ready for V1.0 production.
    [DL0WH_BiTuner_Ctrl_1V0.brd, DL0WH_BiTuner_Ctrl_1V0.sch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]
2019-01-04 HW_1V0 - CAD/Eagle - Polygon GND checks also done
    [DL0WH_BiTuner_Ctrl_1V0.brd]
2019-01-04 HW_1V0 - CAD/Eagle - Pre-view pictures of the PCB added
2019-01-04 HW_1V0 - CAD/Eagle - Prepare for README.md update
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2019-01-06 SW - infrastructure from HFT-Core-Module used as template
    [DL0WH_BiTuner_PinOuts_With-AFs.csv, DL0WH_BiTuner_PinOuts_Without-AFs.csv]
2019-01-11 DOCS - manufacturing - pre-views of top and bottom of the PCB
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2019-01-13 SW - SWR opti algo missing parts added
    [main.h, task_Controller.c]
2019-01-13 SW - float type mismatch fixed
    [main.c]
2019-01-13 SW - task_Controller - missing prototypes added
    [main.c]
2019-01-13 SW - tester - step size fixed
    [main.c]
2019-01-13 SW - task_Controller - C/L --> value fixed
    [task_Controller.c]
2019-01-14 SW - tuner Algo uses real capacity and inductivity values instead of L/C count numbers due to overlapping areas
2019-01-14 SW - printf() format fixes
    [task_Controller.c]
2019-01-15 SW - print format different for STM32L4 and Linux/Mac environment
2019-01-15 SW - SWR Algo - wrong signedness fixed
    [main.c, task_Controller.c]
2019-01-15 SW - Tuner Algo - timer sped up
2019-01-17 HW - CAD/Eagle/lbr - STM32L4 library with bad package LQFP64 fixed, LQFP144 minor fix
2019-01-17 HW_1V1 - CAD/Eagle - new version V1.1 with fixed STM32L476 device added
    [DL0WH_BiTuner_Ctrl_1V1.brd, DL0WH_BiTuner_Ctrl_1V1.sch]
2019-01-17 HW_1V1 - CAD/Eagle - after DRC fixes, ready for production with new STM32L476 device package.
    [DL0WH_BiTuner_Ctrl_1V1.brd]
2019-01-17 HW_1V1 - CAD/Eagle - Manufacturing data added
    [DL0WH_BiTuner_Ctrl_1V0.brd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]
2019-01-18 SW - Tuner Algo - STL mapped values with much better results
2019-01-19 SW - _Tests - auto tuner seems to work quiet well in the antenna simulator
2019-01-19 SW - _Tests - Ground plane impedances added
2019-01-29 SW - task_UART - adapted for current build
2019-01-29 SW - task_CAT - copied and adapted for current build
2019-01-29 SW - task_Interpreter - warning solved
    [task_Interpreter.c]
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2019-02-01 HW_1V2 - df4iah_connector.lbr - SWD connector fixed
2019-02-01 HW_1V2 - SWD connector fixed, PCB board house failed on 6 mil trace distances
    [DL0WH_BiTuner_Ctrl_1V2.brd, DL0WH_BiTuner_Ctrl_1V2.sch]
2019-02-01 DOCS - README.md - new PCB screenshots added
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2019-02-02 HW_1V0 HW_1V1 HW_1V2 - TPS62051 changed to TPS62056
    [DL0WH_BiTuner_Ctrl_1V0.brd, DL0WH_BiTuner_Ctrl_1V0.sch, DL0WH_BiTuner_Ctrl_1V1.brd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]
2019-02-03 HW_1V2 - CAD/Eagle - add CRS08 to power the 5V rail when no 12V is attached
    [DL0WH_BiTuner_Ctrl_1V2.brd, DL0WH_BiTuner_Ctrl_1V2.sch]
2019-02-03 SW - SPI1 around switched fixed
    [DL0WH_BiTuner.ioc, bus_spi.c, main.c]
2019-02-04 SW - SPI1 to 4MHz and 2nd clock phase, missing DMAs added
    [DL0WH_BiTuner.ioc, adc.c, main.c]
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2019-02-05 Docs - 76_SWD-connector - try this shorter file name
2019-02-05 SW - task_USB - uartTx works fine with 9.600 baud together with USB CDC
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2019-02-08 SW - interleaved fixed. Max 15W output when switching L,C,mode
    [main.h, task_Controller.c, task_Interpreter.c]
2019-02-08 SW - task_UART - DMA rollover still needs a fix
    [main.c, task_Controller.c, task_Interpreter.c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]
2019-02-08 SW - task_UART - DMA rollover fixed
    [task_UART.c]
2019-02-08 SW - task_Interpreter - fix-up help, restart
    [task_Interpreter.c]
2019-02-09 SW - minor but many fixes
    [main.h, task_Controller.c, task_Interpreter.c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]
2019-02-09 SW - many ADC issues fixed
    [device_adc.c, device_adc.h, task_Controller.c]
2019-02-10 SW - main.c - mainCalcFloat2IntFrac() rounding fixed
    [main.c, main.h]
2019-02-10 SW - device_adc - ADCs fixed and adjusted
    [DL0WH_BiTuner.ioc, adc.c, device_adc.c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]
2019-04-04 HW_1V3 - forward until df4fd7a65716eb1a1b8dad1e9e020a2e6c04cd7f (2019-04-03)
    [DL0WH_BiTuner_Ctrl_1V3.brd, DL0WH_BiTuner_Ctrl_1V3.sch]
2019-04-04 SW - prepare RtosDefault timer for the ADCs
2019-04-04 SW - RtosDefault timer running at every 30ms
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2019-04-06 SW - help message text fixes (cherry: b48870203dc3e88748f9b94d8d446dfb6c681701)
    [task_Interpreter.c]
2019-04-06 SW - task_Interpreter - fix for clear screen
    [task_Interpreter.c]
2019-04-06 SW - task_Interpreter - init fix (cherry: 5b80c603c5e35eadf550d8289eeb7ec82cb53e50)
    [task_Interpreter.c]
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2019-04-06 SW - missing help line fixed, all cherry-picking from previous branch done
    [task_Interpreter.c]
2019-04-06 SW - VSWR calculation fixed
    [device_adc.c, task_Controller.c]
2019-04-06 SW - I2C1 bus scan OK, addr 0x28 for DigPot. found
2019-04-06 HW_1V2 - CAD/Eagle - wrong I2C address fixed
    [DL0WH_BiTuner_Ctrl_1V2.sch]
2019-04-06 HW_1V3 - CAD/Eagle - wrong I2C address fixed
    [DL0WH_BiTuner_Ctrl_1V3.sch]
2019-04-07 DOCS - Spice simulation - re-work for Log-Amp after voltage divider was added
2019-04-07 HW_1V2,HW_1V3 - CAD/Eagle - voltage divider added to tolerate voltages 0V..10V
    [DL0WH_BiTuner_Ctrl_1V2.brd, DL0WH_BiTuner_Ctrl_1V2.sch, DL0WH_BiTuner_Ctrl_1V3.brd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]
2019-04-08 SW - linearity checks and tests vs. ambient temperature
2019-04-10 SW - stop UART DMA before starting again
2019-04-10 SW - relay OFF by timer event 30ms after ON signal
2019-04-13 SW - controller - timing fixes
    [main.h, task_Controller.c, task_Interpreter.c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]
2019-04-14 SW - task_UART - eventgroup handling fixed
    [DL0WH_BiTuner.ioc, main.h, task_Controller.c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]
2019-04-16 SW - interpreter, controller - switch for automatic matching added
2019-04-16 SW - controller - init relays in both directions
2019-04-18 SW - STM32CubeMX project file - ST.com try to get a clean version of the previous V5.10 *.ioc variant
2019-04-18 SW - STM32CubeMX project file - removed again, it is not needed anymore
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2019-04-20 SW - 2nd device proof - adjustments for the 2nd device
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2019-04-22 SW - adc - fwd voltage fix
    [device_adc.c]
2019-04-25 SW - task_Controller - auto offset calibration only when no RF energy is metered
2019-04-25 SW - device_adc - temperature calibration for current MCU / Diode done
